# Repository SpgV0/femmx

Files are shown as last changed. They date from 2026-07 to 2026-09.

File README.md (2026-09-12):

# FEMMX

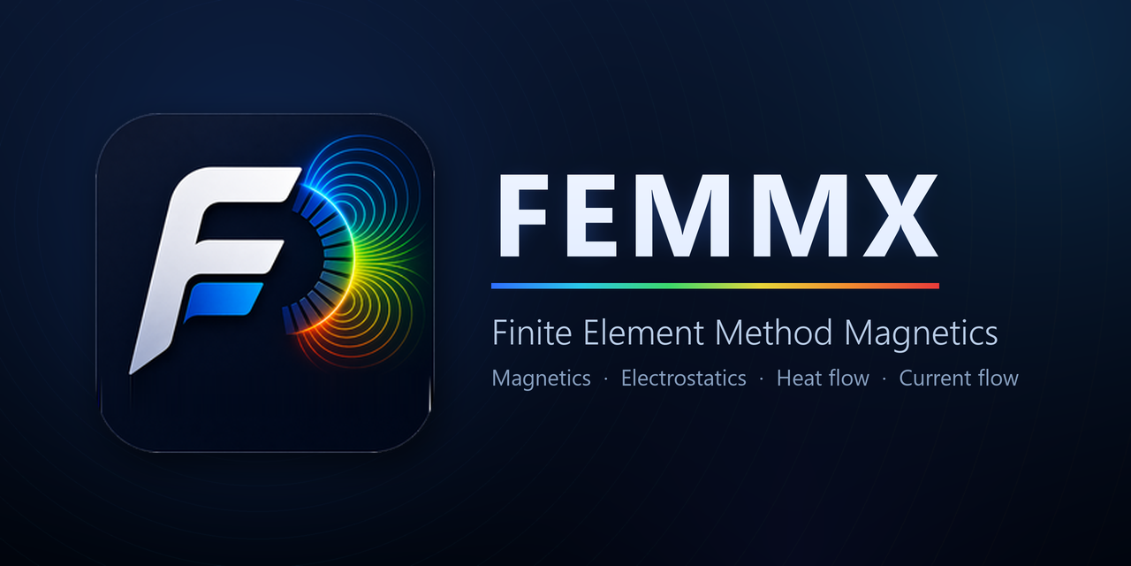
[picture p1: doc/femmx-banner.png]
FEMMX -- Finite Element Method Magnetics


FEMMX is a fork of [FEMM 4.2](https://www.femm.info/) (Finite Element Method
Magnetics), a Windows application for solving 2D planar and axisymmetric
problems in:

* Magnetics (magnetostatic and time-harmonic/eddy-current)
* Electrostatics
* Heat flow
* Current flow (DC conduction)

Problems are built and meshed in a native MFC editor (`femmx.exe`), solved by
one of four solver executables — one per problem type — and results are
inspected in a built-in post-processor.

| Problem type | Solver | Invoked from |
|---|---|---|
| Magnetics | `fkn.exe` | `femm/FemmeView.cpp` |
| Electrostatics | `belasolv.exe` | `femm/beladrawView.cpp` |
| Heat flow | `hsolv.exe` | `femm/hdrawView.cpp` |
| Current flow | `csolv.exe` | `femm/cdrawView.cpp` |

(`belasolv` is BELA, FEMM's electrostatics companion program. The Kelvin
transformation is a modelling technique for open boundaries, available across
problem types — not a solver of its own.)

Problems can also be driven entirely by script via
Lua (built in), Octave/Matlab (`octavefemm`), Mathematica (`mathfemm`),
Scilab (`scifemm`), or Python ([`pyfemm`](https://www.femm.info/wiki/pyFEMM),
via the `femm.ActiveFEMM` COM automation server).

This fork is hosted at https://github.com/SpgV0/femmx as a fork of
https://github.com/cenit/FEMM. It adds an optional CUDA-accelerated linear
solve, a CPU/GPU load monitor, dark-theme editor/results views, an installer
that mirrors the original `C:\femm42` layout with automatic COM
self-registration, and a pytest-based regression suite -- see
[CHANGELOG.md](CHANGELOG.md) for the full, dated history of every change
since the [22Oct2023](https://github.com/cenit/FEMM) upstream baseline, and
[NOTICE.md](NOTICE.md) for the license-required per-file modification
record.

FEMMX is distributed under the terms of the Aladdin Free Public License --
see [license.txt](license.txt).

## Requirements

Building and running FEMMX requires **Windows** (the project is MFC/Win32
native code; there is no cross-platform build). You'll need:

* [Git](https://git-scm.com/)
* [CMake](https://cmake.org/) 3.10 or later
* Visual Studio 2019 or 2022, with the **"Desktop development with C++"**
  workload, which must include the **MFC and ATL** optional component
  (`find_package(MFC REQUIRED)` in several `CMakeLists.txt` files depends on
  it)

Optional, depending on what you want to build:

* [NSIS](https://nsis.sourceforge.io/) (`makensis` on `PATH`) -- to build the
  installer (`FEMMX_v<version>_installer.exe`). If not found, the
  executables still build fine; only installer packaging is skipped.
* [NVIDIA CUDA Toolkit](https://developer.nvidia.com/cuda-toolkit), **12.x**
  (13.x dropped compute capability `sm_60`, one of this project's default
  target architectures) -- to build `fkn.exe`'s optional GPU-accelerated
  linear solver. Also needs an NVIDIA GPU to actually use at runtime (it
  falls back to the CPU solver automatically if none is found). CUDA's
  MSVC-support window tends to lag behind the newest installed Visual
  Studio, so a VS2022 toolset is also needed alongside a newer VS if one is
  installed (auto-detected by `build_cuda.bat`; see below).
* A LaTeX distribution (e.g. [MiKTeX](https://miktex.org/)), with `latex` on
  `PATH` -- to build the PDF manual (`manual/manual.tex.in`). Skipped
  automatically if not found.
* [Python](https://www.python.org/) 3.9+ with the packages in
  [`test/requirements.txt`](test/requirements.txt) -- to run the regression
  suite under `test/` (see [test/README.md](test/README.md)).

## Building

The simplest way to build is the zero-argument wrapper scripts, which
auto-detect all of the above and print diagnostics for anything missing:

```
build_plain.bat
```
builds `femmx.exe` and the other executables without GPU support, into
`bin\plain\`.

```
build_cuda.bat
```
additionally builds `fkn.exe`'s CUDA-accelerated linear solver, into
`bin\cuda\`. Auto-detects the CUDA Toolkit root (preferring a 12.x install)
and an `nvcc`-compatible VS2022 toolset; pass a CUDA Toolkit path as the
first argument to override, or set the `FEMM_CUDA_CCBIN` environment
variable to force a specific MSVC toolset.

Either way, once the build finishes you'll have:

* `bin\<plain|cuda>\femmx.exe` -- the main application
* `bin\<plain|cuda>\FEMMX_v<version>_installer.exe` -- the NSIS installer
  (if NSIS was found)

Both scripts are thin wrappers (`build_femmx.ps1`) around the underlying
`build.ps1`, which can also be invoked directly for more control, e.g.:

```
.\build.ps1 -DisableInteractive -DisableLaTeX -ForceTriangle32bit `
  -AdditionalBuildSetup "-DENABLE_CUDA_SOLVER=ON -DFEMM_CUDA_ROOT=`"C:\Program Files\NVIDIA GPU Computing Toolkit\CUDA\v12.6`""
```

`build.ps1` runs `cmake --build . --target install`, which places
executables directly in `bin\` (not the `plain\`/`cuda\` split -- that split
is done by `build_femmx.ps1` afterwards so a plain and a CUDA build don't
clobber each other).

### Useful CMake options

Pass these via `build.ps1`'s `-AdditionalBuildSetup "..."` parameter, or
directly to `cmake` if configuring by hand:

| Option | Default | Effect |
|---|---|---|
| `ENABLE_CUDA_SOLVER` | `OFF` | Build `fkn.exe`'s CUDA-accelerated solver. Requires `FEMM_CUDA_ROOT`. |
| `FEMM_CUDA_ROOT` | (none) | Path to the CUDA Toolkit, e.g. `C:/Program Files/NVIDIA GPU Computing Toolkit/CUDA/v12.6` |
| `FEMM_CUDA_CCBIN` | (none) | Optional `nvcc -ccbin` override: an alternate MSVC toolset `bin` dir |
| `FEMM_CUDA_ARCHS` | `60;75;86;89` | CUDA compute capabilities to build for |
| `BUILD_MANUAL` | `OFF` | Build the PDF manual (needs LaTeX) |
| `SKIP_<target>` | `OFF` | Skip building an individual component, e.g. `SKIP_scifemm` |

## Installing

Run the installer produced by the build (`bin\plain\FEMMX_v<version>_
installer.exe` or `bin\cuda\FEMMX_v<version>_installer.exe`). It installs to
a fixed `C:\FEMMX`, laid out like the original FEMM 4.2 installer:

```
C:\FEMMX\
  bin\        executables and data libraries
  mathfemm\   Mathematica interface
  mfiles\     Octave/Matlab interface (octavefemm)
  scifemm\    Scilab interface
```

and self-registers the `femm.ActiveFEMM` COM automation class (used by
`pyfemm`, Octave, Matlab, Mathematica, and Scilab), so scripting works
immediately after install with no separate manual registration step. A CUDA
build's installer also bundles the required CUDA runtime DLLs.

## Testing

The regression suite under `test/` builds and solves FEMM models through the
`pyfemm` COM interface and checks results, timings, and Lua-command
coverage. See [test/README.md](test/README.md) for details; in short:

```
pip install -r test/requirements.txt
pytest test/
```

## More information

* [CHANGELOG.md](CHANGELOG.md) -- dated history of every change, this fork
  and upstream
* [NOTICE.md](NOTICE.md) -- license-required modification record
* [test/README.md](test/README.md) -- regression suite details
* [manual/](manual/) -- LaTeX source for the user manual
* Upstream: https://github.com/cenit/FEMM, https://www.femm.info/

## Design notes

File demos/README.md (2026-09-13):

# FEMMX demo models

A small library of worked models, one set per problem type, intended to be opened,
solved and read rather than edited in place. Every one of them is a case with a known
closed-form answer, so the demo is not just "a model that opens" -- it is a model whose
result you can check against physics.

These are the sources the planned **File > Demo Models** browser lists (issue #89).
Treat this directory as read-only: a demo should be opened as a working copy, and
solving must not write mesh or solution files back here. The demos are committed, so
`git status` will notice if something does.

Each model also carries its own description in its `[Comment]` field, which the
Problem Information dialog shows.

## Magnetics (`.fem`)

| Model | What it shows | Analytic reference |
|---|---|---|
| `straight_wire.fem` | A single 10 A conductor in open-boundary air. The simplest model here. | `B = mu0*I/(2*pi*r)` |
| `coax_cable.fem` | Coax with equal and opposite currents; external inductance from stored energy. | `L' = (mu0/2pi)*ln(b/a)` |
| `circular_loop_axi.fem` | Single-turn loop, axisymmetric -- the standard introduction to axisymmetric modelling. | `B = mu0*I*a^2/(2*(a^2+z^2)^(3/2))` |
| `solenoid_axi.fem` | A solenoid short enough that end effects pull the centre field well below `mu0*n*I`. | finite-solenoid on-axis form |
| `two_wires_force.fem` | Force between parallel conductors; Lorentz and weighted stress tensor on the same block. | `F/L = mu0*I1*I2/(2*pi*d)` |
| `saturating_core.fem` | Nonlinear B-H core driven into saturation -- relative permeability falls from ~13000 to ~100. | no closed form; check against the B-H curve |
| `skin_effect_ac.fem` | Time-harmonic at 100 kHz: skin depth ~0.21 mm in a 5 mm conductor. | `delta = sqrt(2/(omega*mu*sigma))` |

## Electrostatics (`.fee`)

| Model | What it shows | Analytic reference |
|---|---|---|
| `parallel_plate.fee` | Periodic side boundaries remove fringing, leaving a uniform field. | `C = eps*A/d` |
| `coax_capacitor_axi.fee` | Coaxial conductors at fixed potentials; logarithmic potential. | `C' = 2*pi*eps/ln(b/a)` |

## Heat flow (`.feh`)

| Model | What it shows | Analytic reference |
|---|---|---|
| `slab_1d.feh` | 400 K / 300 K faces: linear profile, uniform flux. | `q = k*dT/L` |
| `cylindrical_shell_axi.feh` | Radial conduction, logarithmic rather than linear. | `T(r)` logarithmic |
| `convection_wall.feh` | A convection boundary, so the outer face temperature is solved rather than prescribed. | `q'' = h*(T_s - T_inf)` |

## Current flow (`.fec`)

| Model | What it shows | Analytic reference |
|---|---|---|
| `conducting_bar.fec` | Uniform current density between two fixed potentials. | `R = rho*L/A` |

## Where these came from

Each model was taken from the analytic regression suite -- `test/analytic_fields_test.py`
and `test/magnetics_analytic_test.py` build them and assert the results against the
formulas above, typically to well under 1%. `demos.json` records the source path for
each in its `derivedFrom` field.

That shared origin is deliberate: the demo library and the analytic tests stay
meaningful together, and a demo that stopped matching its formula would fail the test
suite first. Note the test suite regenerates its own copies under `test/results/`
(gitignored) on every run -- these committed copies are independent of that.

`demos.json` is the machine-readable manifest: title, problem type, description,
analytic reference and source path per demo.

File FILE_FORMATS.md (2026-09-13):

# FEMMX file formats

FEMMX uses four file types. `.fem`/`.ans` are the original, plain-text
formats shared by every FEMMX component (both GUIs, the solvers, and
every language binding). `.femx`/`.ansx` are newer, pure-binary **caches**
of that same data, introduced to make loading fast for large models —
never a second source of truth, and never shell-registered or meant to
be edited by hand.

Both GUIs (the classic MFC app, `femm/`, and the Qt app, `femmqt/`) read
and write all four formats independently — there is no shared parsing
code between them, matching this project's existing convention that each
consumer (GUI or solver) owns its own reader/writer for these formats.

## Relationship between the four formats

```
   .fem  (geometry + properties, text)
     |
     |  triangle.exe (mesh) + fkn.exe (solve)
     v
   .ans  (.fem's own header, plus the solved mesh, text)

   .femx = binary cache of .fem, regenerated whenever stale
   .fes  = femmqt's sketch layer for .fem -- NOT a cache, see below
   .ansx = binary cache of .ans's MESH data only, regenerated whenever stale
```

- A `.femx`/`.ansx` file is always named after its source
  (`foo.fem` → `foo.femx`, `foo.ans` → `foo.ansx`) and lives next to it.
- **Freshness check**: each cache's header records its source file's
  size (bytes) and mtime (seconds since epoch). A GUI opening `foo.fem`
  compares `foo.femx`'s recorded size/mtime against `foo.fem`'s current
  size/mtime on disk; any mismatch (or a missing/corrupt/wrong-version
  cache) means "stale" — the GUI falls back to the normal text parser
  and, on success, rewrites the cache for next time. This is always a
  **best-effort** step: a write failure (e.g. a read-only directory)
  never fails the operation the user actually asked for, it just means
  no speedup next time.
- Every numeric field in `.femx`/`.ansx` is a byte-for-byte copy of what
  the text parser would have produced from `.fem`/`.ans` — opening a
  file via its cache and via its text source must always produce
  identical in-memory state.

---

## `.fem` — geometry + properties (plain text)

Written by `CFemmeDoc::OnSaveDocument` (`femm/FemmeDoc.cpp`) /
`FemmFileIO::writeFem` (`femmqt/FemmFileIO.cpp`); read by
`OnOpenDocument` / `FemmFileIO::readFem`. Tag-value lines
(`[Tag]  =  value` or, inside a property block, `<Tag> = value`),
whitespace around `=` is not significant. Numbers are written with
`%.17g` (exact `double` round-trip). Every table below is 0-indexed in
memory but 1-indexed on disk (`0` = "none" for an optional reference; an
in-file index of `N` means the `N`th entry, 1-based, of the referenced
list).

### Header (top-level `[Tag] = value` lines, in this order)

| Tag | Field | Notes |
|---|---|---|
| `[Format]` | file format version | `4.0` currently |
| `[Frequency]` | Hz | 0 = magnetostatic |
| `[Precision]` | solver precision | e.g. `1e-8` |
| `[MinAngle]` | degrees | triangle.exe mesh quality constraint |
| `[DoSmartMesh]` | 0/1 | auto-refine mesh near small features |
| `[Depth]` | into-the-page depth | planar problems only |
| `[LengthUnits]` | `inches`\|`millimeters`\|`centimeters`\|`meters`\|`mils`\|`microns` | |
| `[ProblemType]` | `planar`\|`axisymmetric` | |
| `[Coordinates]` | `cartesian`\|`polar` | |
| `[ACSolver]` | 0=successive approx, 1=Newton | |
| `[GPUAccel]` | 0/1 | ask fkn.exe to try its CUDA solve; no effect unless fkn.exe was built with CUDA support |
| `[PrevType]` / `[PrevSoln]` | previous-solution info, for incremental permeability problems | |
| `[Comment]` | quoted string | free-text problem note |
| `[extZo]` / `[extRo]` / `[extRi]` | axisymmetric exterior-region parameters | only written if `extRo`/`extRi` are both non-zero |

### Property sections

Each is `[XProps]  = <count>` followed by `<count>` `<BeginX>...<EndX>`
blocks.

**`[PointProps]`** (`<BeginPoint>`): `<PointName>`, `<I_re>`/`<I_im>`
(applied point current, A), `<A_re>`/`<A_im>` (prescribed nodal value).

**`[BdryProps]`** (`<BeginBdry>`): `<BdryName>`, `<BdryType>` (0=fixed
A, 1=small-skin-depth eddy current, 2=mixed, 3=SDI, 4/5=periodic/
antiperiodic, 6/7=periodic/antiperiodic air-gap), `<A_0>`/`<A_1>`/
`<A_2>`/`<Phi>` (BdryType=0), `<c0>`/`<c0i>`/`<c1>`/`<c1i>` (mixed BC
coefficients), `<Mu_ssd>`/`<Sigma_ssd>` (eddy BC), `<innerangle>`/
`<outerangle>` (air-gap element rotation).

**`[BlockProps]`** (`<BeginBlock>`): `<BlockName>`, `<Mu_x>`/`<Mu_y>`
(relative permeability), `<H_c>` (magnetization, A/m), `<H_cAngle>`
(magnetization direction, degrees), `<J_re>`/`<J_im>` (applied current
density, MA/m²), `<Sigma>` (conductivity, MS/m), `<d_lam>` (lamination
thickness, mm), `<Phi_h>`/`<Phi_hx>`/`<Phi_hy>` (hysteresis angles,
degrees), `<LamType>` (0=none/in-plane, 1=x-laminated, 2=y-laminated,
≥3=stranded/litz), `<LamFill>` (lamination fill factor), `<NStrands>`,
`<WireD>` (strand diameter, mm), `<BHPoints>` followed by that many
`B<tab>H` lines (a linear material has `BHPoints = 0` and uses `Mu_x`/
`Mu_y` directly instead).

**`[CircuitProps]`** (`<BeginCircuit>`): `<CircuitName>`,
`<TotalAmps_re>`/`<TotalAmps_im>`, `<CircuitType>` (0=parallel,
1=series), and optionally `<VoltGradient_re>`/`<VoltGradient_im>`.

`<CircuitType>` selects how the circuit is driven. 0 is a *parallel*
circuit: the whole region carries `TotalAmps`, and the solver finds the
current density that delivers it. 1 is a *series* circuit: every turn
carries `TotalAmps`, so the region's current density is scaled by the
block label's `<Turns>` count.

`<VoltGradient_re>`/`<VoltGradient_im>` prescribe a voltage gradient
along the circuit instead of a current, and are read into
`CCircuit::dVolts_re/im` by every magnetics solve path
([`fkn/femmedoccore.cpp:965`](fkn/femmedoccore.cpp#L965), used in
`prob1big.cpp` through `prob4big.cpp`). They default to 0 and are written
only when non-zero, so a model that does not use them is byte-identical
to one written before they were supported.

> **This field is inert in the shipped solver.** `LoadCircuits` rewrites
> every `CircuitType` of 1 to 0 just before the solve
> ([`fkn/femmedoccore.cpp:1100`](fkn/femmedoccore.cpp#L1100)) — "now, all
> circuits look like parallel circuits" — and the branch that reads
> `dVolts` runs only for a non-zero type. So no `.fem` can currently
> reach it. Both editors nevertheless parse and preserve the tags,
> because until they did, a hand-authored or third-party file carrying a
> voltage-driven circuit lost it silently on its next save. Documented
> here as what it is rather than left out: an undocumented field that a
> published format spec omits is how the loss went unnoticed.

### Geometry sections (in this order)

- **`[NumPoints] = N`**, then `N` lines: `x  y  pointPropIndex  inGroup`
  (`pointPropIndex`: 0=none, else 1-based into `[PointProps]`).
- **`[NumSegments] = N`**, then `N` lines: `n0  n1  maxSideLength
  boundaryMarker  hidden  inGroup` (`maxSideLength`: `-1` = no mesh
  constraint; `boundaryMarker`: 0=none, else 1-based into `[BdryProps]`).
- **`[NumArcSegments] = N`**, then `N` lines: `n0  n1  arcLength
  maxSideLength  boundaryMarker  hidden  inGroup  mySideLength`
  (`arcLength`/`mySideLength` in degrees).
- **`[NumHoles] = N`**, then `N` lines: `x  y  inGroup` — block labels
  with no assigned material ("`<No Mesh>`" in the classic GUI's own
  in-memory model).
- **`[NumBlockLabels] = N`**, then `N` lines: `x  y  blockTypeIndex
  meshSizeDiameter  circuitIndex  magDir  inGroup  turns
  isExternal+isDefault  ["magDirFctn"]` (`blockTypeIndex`: 1-based into
  `[BlockProps]`; `meshSizeDiameter`: `-1` = no constraint, else
  `sqrt(4*maxArea/pi)` — the *area* constraint, converted to a
  *diameter* only for this on-disk field; `circuitIndex`: 0=none, else
  1-based into `[CircuitProps]`; trailing quoted string is a custom Lua
  `MagDirFctn` expression, present only if non-empty).

---

## `.ans` — solved mesh (plain text)

Written by `fkn.exe` (`fkn/prob1big.cpp`); read by `CFemmviewDoc::
OnOpenDocument` (`femm/FemmviewDoc.cpp`) / `AnsFileIO::readAns`
(`femmqt/AnsFileIO.cpp`). The header and property sections are **byte-
for-byte the same tag format as `.fem`** (both readers tolerate the
other file type's trailing sections they don't recognize) — solving
never changes the original geometry/properties, so `fkn.exe` just
carries them through unchanged ahead of its own solved-mesh section.

After the properties sections and geometry sections (same as `.fem`,
above) comes an untagged `[Solution]` marker, then:

1. **Mesh nodes**: `<count>`, then that many lines:
   `x  y  A_re  [A_im]` (`A_im` only present if `Frequency != 0`) —
   the complex nodal vector potential (planar) or `r·A` flux function
   (axisymmetric), in Wb/m or Wb respectively.
2. **Mesh elements**: `<count>`, then that many lines:
   `p0  p1  p2  lbl` (0-based node indices; `lbl` = 0-based index into
   the block-label list from the header section above).
3. **Per-block-label circuit correction**: `<count>` (always equal to
   the block-label count — every label gets a row, even ones with no
   circuit assigned), then that many lines: `Case  value_re  [value_im]`
   — `fkn.exe`'s own solved correction for circuits with a prescribed
   voltage (`Case=0`, `value` = the solved voltage-drop `dVolts`) or
   prescribed current (`Case=1`, `value` = the solved current-density
   correction `J`); a label with no circuit gets a harmless placeholder
   row (`Case=1`, `value=0`). This section is easy to miss reading the
   format casually — it's untagged and comes immediately after the
   element list with no header of its own.
4. **PBC (periodic boundary) data** — not actively used by either
   post-processor GUI today, but must still be read (to reach the data
   after it): `<count>`, then that many lines (skipped).
5. **Air gap elements**: `<count>`, then for each: a name line, a
   parameter line (`BdryFormat  InnerAngle  OuterAngle  ri  ro
   totalArcLength  agc_re  agc_im  totalArcElements  InnerShift
   OuterShift`), and (if `totalArcElements > 0`) further per-element
   sample data. Used for rotating-machine "moving band" simulations —
   an advanced, comparatively rare feature; not yet supported by the Qt
   GUI.

**Derived data, recomputed after loading, not stored in the file**:
each element's centroid, `rsqr` (max corner distance from centroid,
used for point-location queries), magnetization direction (evaluates
any custom `MagDirFctn` Lua expression), and `B1`/`B2` (flux density,
from nodal `A` via shape-function gradients) — this recomputation is
`.ans`'s single most expensive load step for a large mesh, and is
exactly what `.ansx` exists to cache (below).

---

## `.femx` — binary cache of `.fem`

Defined in `femmqt/FemxFileIO.h`/`.cpp`; ported to the classic GUI in
`femm/FemxFileIO.h`/`.cpp` (byte-for-byte the same format, independent
implementation — Qt types on one side, MFC/plain C++ on the other,
matching this project's established pattern of independent format
readers per consumer). Current version: **2**.

All multi-byte fields are little-endian (native x86/x64), and every
struct is `#pragma pack(push, 1)` — no padding.

```
FemxHeader {
  char     magic[8];            "FEMMFEMX"
  uint32_t version;              2
  uint32_t headerSize;           sizeof(FemxHeader) -- lets a future
                                  version add trailing fields a reader
                                  built against an older version can
                                  still skip past
  uint32_t problemType;          0=planar, 1=axisymmetric
  uint32_t lengthUnits;          matches .fem's [LengthUnits] encoding
  uint8_t  coordsPolar;
  uint8_t  smartMesh;
  uint8_t  reserved[6];
  double   frequency, precision, minAngle, depth;
  double   extZo, extRo, extRi;
  int32_t  acSolver, gpuAccel, prevType;
  char     prevSoln[260];        fixed-size, NUL-padded
  char     comment[512];         fixed-size, NUL-padded
  uint64_t sourceFemSize;        source .fem's size, for the freshness check
  uint64_t sourceFemMtimeSecs;   source .fem's mtime, for the freshness check
  uint64_t pointPropCount, boundaryPropCount, materialPropCount, circuitPropCount;
  uint64_t nodeCount, segmentCount, arcCount, blockLabelCount;
}                                 -- 952 bytes
```

Followed by flat arrays, in this order, each `count` from the header
above: point-prop records, boundary-prop records, material-prop records,
circuit-prop records, node records, segment records, arc records,
block-label records. Every property/geometry field maps directly to its
`.fem` text-format counterpart (see the `.fem` section above); a few
notable on-disk differences from the in-memory model:

- **BH curve data** (`FemxMaterialPropRecord`) is a fixed
  `double[256][2]` array (`bhPointCount` says how many are actually
  used) rather than a dynamic list — 256 comfortably exceeds every
  material in `bin/matlib.dat` (the largest ships 149 points); classic
  FEMM's own in-memory model has no fixed cap, so this is a cache-format
  limit only, not a modeled one. **Changing this cap changes the
  record's byte size and requires a version bump** — a real bug this
  session (cap silently truncating past-64-point curves) was caused by
  extending the in-memory field without remembering this.
- **Point/boundary/circuit references** (a node's point-prop, a
  segment/arc's boundary marker, a block label's material/circuit) are
  stored as the same 0/1-based index convention as the `.fem` text
  format, not as names — even though the classic GUI's own in-memory
  model stores these as name strings (`CString`) internally; the reader/
  writer resolves name↔index against the property arrays exactly like
  `.fem`'s own text reader/writer already does.
- **Block label area vs. diameter**: `.femx`'s `maxArea` field stores
  the *area* directly (unlike `.fem` text, which stores a derived
  diameter) — matching the in-memory field it mirrors, since there's no
  text-format round-trip step to justify the conversion here.

---

## `.ansx` — binary cache of `.ans`'s mesh

Defined in `femmqt/AnsxFileIO.h`/`.cpp`; ported to the classic GUI in
`femm/AnsxFileIO.h`/`.cpp`. Current version: **3**.

**Deliberately not a serialization of the whole `.ans` file** — only the
mesh-node and mesh-element arrays (the two sections whose size scales
with mesh size and dominates load time for a large solved model).
Geometry/properties, the per-block-label circuit correction section, and
the air gap element section are always still read from the source
`.ans` text regardless of whether the mesh cache is used — all three are
bounded by geometry complexity (not mesh density), so cheap even for a
multi-million-element mesh, and re-reading them keeps this format simple
and its scope obviously "mesh only."

```
AnsxHeader {
  char     magic[8];            "FEMMANSX"
  uint32_t version;              3
  uint32_t headerSize;           sizeof(AnsxHeader)
  uint32_t coordSystem;          0=planar, 1=axisymmetric
  uint32_t lengthUnits;
  double   frequency;
  double   bMagMin, bMagMax;     precomputed |B| range, for the density-plot legend
  uint64_t sourceSize;           source .ans's size, for the freshness check
  uint64_t sourceMtimeSecs;      source .ans's mtime, for the freshness check
  uint64_t nodeCount;
  uint64_t elementCount;
}                                 -- 80 bytes

AnsxNodeRecord {
  double x, y, Are, Aim;
}                                 -- 32 bytes

AnsxElementRecord {
  int64_t  p0, p1, p2, lbl;      node/label indices (int64 purely to
                                  keep every field 8-byte aligned, not
                                  because indices need the range)
  double   B1re, B1im, B2re, B2im;
  double   ctrX, ctrY;
  double   muX, muY;             resolved material properties (see below)
  double   sigma;
  double   jSrcRe, jSrcIm;
  double   jRe, jIm;             total current density: source + eddy +
                                  solved circuit correction, MA/m^2
}                                 -- 136 bytes
```

Followed by `nodeCount` node records then `elementCount` element
records.

- **B1/B2/centroid are precomputed**, not recomputed from nodal `A` on
  every load — this is the actual point of the format (see `.ans`'s own
  "derived data" note above). `rsqr` and magnetization direction are
  *not* cached (cheap, in-memory-only recomputation, no text re-parse
  needed either way) — a reader still derives those itself after loading
  either the text or the binary path.
- **muX/muY/sigma/jSrcRe/jSrcIm/jRe/jIm are precomputed too**, resolved
  once from each element's block label → material lookup (plus, for
  jRe/jIm, `fkn.exe`'s own solved circuit-correction data) — this is
  what drives the `|H|` and `|Js+Je|` density plots without needing a
  live material-list lookup at render time. The classic GUI's own
  post-processor doesn't need these cached (it already has fast,
  direct, in-memory material-list access at render time) but still
  writes them correctly, purely so a `.ansx` written by the classic GUI
  behaves identically when later opened by the Qt GUI.
  `CFemmviewDoc::GetJA()`'s return value is scaled to A/m² internally
  (despite its own comment claiming MA/m²) — the writer divides by 1e6
  to match every other current-density field's actual MA/m² units.

## The four solution formats

Each solver writes its own solution file, and each is **the model file it
was given, with a `[Solution]` section appended**. Everything before that
marker is the same `[PointProps]`/`[BdryProps]`/`[BlockProps]`/geometry
content the input had, so a solution file is openable as a model.

| physics | solver | solution | post-processor |
|---|---|---|---|
| magnetics | `fkn.exe` | `.ans` | `femm/FemmviewDoc.cpp` |
| electrostatics | `belasolv.exe` | `.res` | `femm/belaviewDoc.cpp` |
| heat flow | `hsolv.exe` | `.anh` | `femm/hviewDoc.cpp` |
| current flow | `csolv.exe` | `.anc` | `femm/CVIEWDOC.CPP` |

### The `[Solution]` section

After the `[Solution]` marker: a node count, that many node lines, an
element count, then that many element lines.

**Element lines are identical in all four** — `p0  p1  p2  lbl`, three
0-based mesh-node indices plus the 0-based index of the block label whose
material the element carries.

**Node lines carry that physics' potential, and differ:**

| physics | node line | notes |
|---|---|---|
| magnetics | `x  y  A_re  A_im` | `A_im` present **only when `[Frequency]` is non-zero**; a DC solution has three columns, not four |
| electrostatics | `x  y  V  Q` | `Q` is the conductor the node belongs to, or 0 |
| heat flow | `x  y  T  Q` | same shape as electrostatics, with temperature in place of voltage |
| current flow | `x  y  v_re  v_im  Q` | the only one that is both complex **and** carries a conductor column |

Two traps worth stating, because both produce a file that parses without
complaint and means something else:

- **Magnetics' column count depends on the frequency in the header.**
  Reading a DC `.ans` as though it were AC consumes the next line's `x`
  as `A_im`, and everything after is shifted. The frequency has to be
  known before the node loop starts — it is in the same file, above.
- **A magnetics node has no conductor column and the other three do.**
  The same asymmetry as the model formats, where magnetics attaches a
  circuit to block labels and the rest attach conductors to geometry.

An *incremental* magnetics solution additionally writes a boundary-code
int and the previous solution's `A` per node; femmqt does not produce
those.

### Derived quantities

The solvers store only the potential per node. Everything the viewer
plots is derived from its gradient over each element:

| physics | stored | derived |
|---|---|---|
| magnetics | `A` | `B = curl A`, `H = B/mu`, `J` |
| electrostatics | `V` | `E = -grad V`, `D = eps*E` |
| heat flow | `T` | `F = -k grad T`, `G = -grad T` |
| current flow | `V` | `E = -grad V`, `J = sigma*E` |

## The four model formats, and what differs between them

`.fem` (magnetics), `.fee` (electrostatics), `.feh` (heat flow) and
`.fec` (current flow) are the same file with different property
payloads. femmqt reads and writes all four through one driver
(`femmqt/ProblemFileIO.cpp`) with the differing parts in
`femmqt/PropertyCodec.cpp`; the classic GUI has four separate document
classes instead.

**Identical in all four:** the `[Format]`, `[Precision]`, `[MinAngle]`,
`[DoSmartMesh]`, `[Depth]`, `[LengthUnits]`, `[ProblemType]`,
`[Coordinates]`, `[extZo]`/`[extRo]`/`[extRi]`, `[GPUAccel]` and
`[Comment]` header scalars; the `[NumPoints]`, `[NumSegments]`,
`[NumArcSegments]` and `[NumHoles]` sections; and the
`<BeginX>`/`<EndX>` record framing of the property sections.

**Per-format header scalars:** `[Frequency]`, `[ACSolver]`, `[PrevType]`
and `[PrevSoln]` for magnetics; `[Frequency]` for current flow; `[dT]`
and `[PrevSoln]` for heat flow. Electrostatics has none of its own.

**Property payloads:**

| section | `.fem` | `.fee` | `.feh` | `.fec` |
|---|---|---|---|---|
| `[PointProps]` | `I_re` `I_im` `A_re` `A_im` | `Vp` `qp` | `Tp` `qp` | `vpr` `vpi` `qpr` `qpi` |
| `[BdryProps]` | `A_0`…`A_2` `Phi` `c0`/`c0i` `c1`/`c1i` `Mu_ssd` `Sigma_ssd` `innerangle` `outerangle` | `Vs` `qs` `c0` `c1` | `Tset` `qs` `beta` `h` `Tinf` `TinfRad` | `vsr` `vsi` `qsr` `qsi` `c0r`…`c1i` |
| `[BlockProps]` | `Mu_x` `Mu_y` `H_c` `J_re` `Sigma` `Phi_h` … `BHPoints` | `ex` `ey` `qv` | `Kx` `Ky` `Kt` `qv` `TKPoints` | `ox` `oy` `ex` `ey` `ltx` `lty` |
| sources | `[CircuitProps]` | `[ConductorProps]` | `[ConductorProps]` | `[ConductorProps]` |

**The geometry is *not* quite identical**, which is easy to miss and
expensive to get wrong:

- `.fee`, `.feh` and `.fec` carry a **conductor index** as an extra
  trailing column on every node and segment row, and on the arc row it
  sits **between `inGroup` and `mySideLength`** — so reading an arc with
  the magnetics column layout does not drop a field, it reads
  `mySideLength` out of the conductor column.
- `.fem` block-label rows are `x y blockType maxsidelen circuit MagDir
  group turns flags ["MagDirFctn"]`; the other three are
  `x y blockType maxsidelen group flags`. No circuit, no MagDir, no
  turns — those are magnetics ideas.

Magnetics attaches its source to a **block label** (a circuit carries
current through a region); the other three attach theirs to **nodes,
segments and arcs** (a conductor is an equipotential surface).

### `.femx` is magnetics-only, deliberately

The binary cache exists for `.fem` and is not extended to the other
three. It is a mirror of the `.fem` record layout and it exists **twice**
— `femmqt/FemxFileIO.cpp` and `femm/FemxFileIO.cpp`, which must stay
byte-identical — so each new format would mean another record layout kept
in lockstep across both copies. The payoff would be load time on models
that do not exist: the very large models that motivated the cache are
magnetics.

The format also has no field saying which physics it holds, so a `.femx`
cannot describe a `.fee` without a version bump invalidating every
existing cache.

The correctness consequence matters more than the reasoning: a `.femx`
sitting next to a `.fee` is a cache of some *other* model that shared the
base name, so femmqt consults the cache only when opening a `.fem`.

## `.fes` — the sketch sidecar (femmqt only)

`foo.fes` holds the constraints and dimensions femmqt's CAD sketch layer
attaches to `foo.fem`. Added for issue #27; before it, the sketch was
session-only and closing the file discarded every constraint.

It is **not a cache**. `.femx`/`.ansx` are regenerable from their source
and are rewritten whenever they go stale; `.fes` is the only copy of what
it holds, which is exactly why it could not live inside `.femx` — sketch
data there would be destroyed the first time anyone touched the `.fem` in
the classic editor, or copied only the `.fem` somewhere else.

- Plain text, versioned by a `<Format>` line, so it diffs and can be
  repaired by hand like `.fem` itself.
- **Nothing about the `.fem` changes.** A `.fem` written by femmqt with a
  sketch is byte-identical to one written without, so it stays readable
  by the classic MFC editor and all four solvers, none of which know
  anything about constraints.
- Safe to delete. A model with no `.fes` loads as an unconstrained
  sketch, which is what every model predating the feature is.
- Each reference is stored with a geometric fingerprint (a node's
  coordinates, an edge's two endpoints) as well as its index, because
  indices shift under insert and delete. On load the stored index is
  accepted only if the entity there still matches; otherwise the
  fingerprint finds it. If nothing matches, or several do, the constraint
  is **dropped and reported** rather than attached to whatever now
  occupies that index.
- Written best-effort, like the caches: a read-only directory never fails
  the save the user asked for. Unlike a cache, the failure is reported.

### Format 2 — construction geometry (issue #31)

`<Format> = 2` adds three sections, written **before** the constraints
because a constraint may reference what they define and references are
resolved as the file is read:

```
<NumConstructionNodes> = 1
cnode 5 0 0
<NumConstructionSegments> = 1
cseg 5 -2 5 12 0
<NumConstructionArcs> = 0
```

- `cnode x y group`
- `cseg x0 y0 x1 y1 group`
- `carc x0 y0 x1 y1 includedAngleDeg group`

Construction geometry is a centreline, a bolt circle, a reference
rectangle — something to constrain and dimension the real geometry
against. It is **excluded from the `.fem` and the `.femx`** and is never
meshed, so the `.fes` is its only copy; that is why these sections carry
the geometry itself rather than a flag.

Endpoints are stored by **coordinate, not index**, because these entities
do not exist in the `.fem` at all and so have no index there to survive
as. On load each endpoint finds the node already at that position or
creates one — finding it is the normal case and the important one, since
a centreline endpoint that coincides with a real corner is exactly what
it was drawn against.

A format-1 file simply has no construction sections, which reads as "no
construction geometry" — the state every model written before this is in.

Keeping it out of the `.fem` is what makes it safe: a centreline written
into the model would be a material boundary, splitting the region it runs
through, meshed and solved like any other edge.

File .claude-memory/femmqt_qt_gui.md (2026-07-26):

---
name: femmqt-qt-gui
description: "New Qt6-based GUI (femmqt/) built alongside the classic MFC GUI: magnetics-only Phase 1, full property editing, and a menu-by-menu parity pass (zoom/pan/grid/undo/move/copy/scale/mirror, mesh split, post-processor analysis tools) -- what it covers, what it doesn't, and where the design decisions live"
metadata:
  type: project
  originSessionId: 846a52dc-e5cc-4b0f-9a4f-7b5debeae297
  modified: 2026-07-24T19:07:58.144Z
---

**Current state (2026-07-21, supersedes Round 10 below): the CLASSIC GUI
is the default again, not Qt.** Round 10 made `FEMMX.lnk` launch
`femmqt.exe` exclusively; a later session reverted this per direct user
instruction ("QT has too many bugs at the moment, use the old GUI as the
default option") -- `script.nsi`'s `FEMMX.lnk` now launches `femmx.exe`
(classic), with a separate `FEMMX (Qt).lnk` for Qt. Also see
[[qt_gui_scope_deferred]]: as of the same session, new non-magnetics
physics-type work (heat/electrostatics/current-flow) is going into the
classic GUI + solvers only, not femmqt -- femmqt stays magnetics-only,
not being actively extended right now.

Built a second GUI for FEMMX, `femmqt/` (Qt6.11.1, MSVC kit at
`C:\Qt\6.11.1\msvc2022_64`), alongside the existing MFC one
(`femm/`/`femmx.exe`), per the user's request to modernize geometry
creation and solution plotting while keeping the classic GUI available.
Committed 2026-07-19 as `68e088c` on `new_features` (pushed).

**Scope: magnetics only (Phase 1).** Electrostatics/heat/current-flow are
untouched -- the classic GUI is still the only option for those. Full
design/implementation plan (including what's explicitly deferred) is at
`C:\Users\spgry\.claude\plans\quizzical-chasing-kernighan.md` -- read that
before starting Phase 2 (the other 3 physics types) or extending Phase 1.

**What it does**: `.fem` geometry editor (`QGraphicsScene`-based,
interactive add/move/delete of nodes/segments/arcs/block labels), drives
`triangle.exe` -> `fkn.exe` to solve (reimplements the `.poly`/`.pbc` mesh
step independently of `femm/writepoly.cpp`, verified byte-identical
output), and a density-plot solution viewer reading `.ans`.

**Two new binary cache formats**, both designed the same way (magic +
versioned header, flat POD record arrays, bulk read/write, staleness
checked via source file size+mtime, silently regenerated when stale):
- `.ansx` -- caches a solved `.ans`'s mesh with flux density precomputed
  once. ~80x faster to reopen than re-parsing the source `.ans`.
- `.femx` -- same idea for `.fem` geometry (added when the user asked
  for a `.fem`-side equivalent after seeing `.ansx`'s speedup).
Neither is a new "source of truth" format -- `.fem`/`.ans` stay canonical
and portable; the `x` variants are pure, regenerable performance caches,
each Qt-app-private (`femmx.exe`/`fkn.exe`/`triangle.exe` never read or
write them).

**GUI switching**: a "Switch to Qt/Classic GUI" menu item in *each* GUI
(added to the classic GUI's `IDR_FEMMETYPE`/`IDR_FEMMVIEWTYPE` menus too,
`femm/FemmeView.cpp`/`FemmviewView.cpp`'s `OnSwitchToQtGui` -- the first
change to `femm/` this whole effort made) writes `<PreferredGUI>` to
`femm.cfg` and hands the current file to the other executable via
`CreateProcess`/`QProcess::startDetached`, then closes. Verified working
in both directions. femmqt.exe is now the **default** GUI (`script.nsi`'s
primary Start Menu shortcut launches it; classic GUI has its own
`FEMMX (Classic).lnk`). **COM automation still targets `femmx.exe`
unchanged** -- femmqt.exe has no COM automation support, so pyfemm/
Octave/Mathematica/Scilab scripts are unaffected by any of this.

**Real bugs found and fixed during implementation** (worth knowing about
if touching this code): `.fem`'s bare closing tags (`<EndBdry>` etc. have
no `=`) need a special check before the tag-dispatch `continue`, or a
parser silently swallows the rest of the file (see FemmFileIO.cpp);
`QGraphicsItem`s need `ItemIgnoresTransformations` + explicit `setZValue`
for node handles to stay clickable/on-top regardless of zoom or z-order;
`QGraphicsScene` needs an explicit large fixed `setSceneRect()` or the
view silently repans between edits, breaking click-to-scene-coordinate
mapping; Qt's default double-click handling swallows the second press of
two same-position clicks, so tool-click handling must be duplicated into
`mouseDoubleClickEvent` too; populating a scene via `setPos()` on fresh
items fires the same `itemChange`/edited-signal path as a real drag, so
`m_dirty = false` must be set *after* `setProblem()`, not before.

**Build system notes**: `femmqt/CMakeLists.txt` is fully independent of
`femm/`'s (own `CMAKE_CXX_STANDARD 17`, since `femm/` has none and relies
on MSVC's legacy mode -- see [[build_and_com_registration_gotchas]] for
the related `<chrono>` finding). No 32-bit Qt6 kit exists, so `build.ps1`
now passes `-DSKIP_femmqt:BOOL=ON` on its 32-bit-only passes (both the
`-ForceTriangle32bit` secondary pass and the plain full-32-bit path).
`build_femmx.ps1`'s plain/cuda variant-move step now also moves Qt's
plugin subdirectories (`platforms/`, `styles/`, etc.), not just top-level
files, using a named allowlist rather than "any directory in bin\" --
learned the hard way after a blanket-move first draft relocated an
unrelated pre-existing stray folder.

See also [[push_branch_policy]] (updated same day: now push to
`new_features` once a day as a work backup, not just when told).

**Update (2026-07-19, same day): full property editing added, committed
`e2cad69`.** Problem Properties dialog; Material/Boundary/Circuit/
PointProp libraries via a shared `PropertyListDialog` (Add/Duplicate/
Edit/Delete callbacks) + a per-type field editor, under a new Problem
menu; per-entity (node/segment/arc/block-label) dialogs on double-click
in Select mode; an Add Arc tool; index-renumbering helpers
(`FemmProblemEdit::delete*Prop`) so deleting a still-referenced property
resets/renumbers cleanly instead of corrupting indices. Toolbar is now
icon-only (`femmqt/toolbar_icons/*.svg`), recolored at runtime from
`QPalette::ButtonText` (`IconTheme.cpp`) so it's correct in both light
and dark modes without shipping two asset sets.

**Real bug found and fixed**: `FemmNode`'s third `.fem` column was
modeled as a `boundaryProps` reference (matching Segment/Arc's own
`boundaryMarker`) but the classic GUI's writer (`femm/FemmeDoc.cpp:
2596-2601`) actually resolves it against `nodeproplist`/`pointProps` --
individual nodes only ever carry a *point* property in classic FEMM,
never a standalone boundary condition. Renamed to `pointPropIndex`
everywhere (FemmProblem.h, FemmFileIO.cpp, FemxFileIO.cpp,
MeshBuilder.cpp). Round-tripping was already correct by accident (the
raw integer just passed through untouched, nothing dereferenced it), so
this stayed latent until building the point-property assignment UI
required getting the semantics right. Worth checking for if this data
model is extended further.

**Other gotchas found this round**: `qt_standard_project_setup()` does
NOT reliably enable `CMAKE_AUTORCC` -- a `.qrc` listed in
`qt_add_executable()`'s sources silently never got compiled until
`set(CMAKE_AUTORCC ON)` was added explicitly before the `qt_add_executable`
call. `.gitignore`'s standalone `Icon?` line (for macOS's cursed
`Icon\r` custom-folder-icon files) collides case-insensitively with any
5-letter directory named `icons` on Windows git (`core.ignorecase`) --
new icon assets went in `femmqt/toolbar_icons/` instead, not
`femmqt/icons/`, to dodge it (don't touch the `Icon?` rule itself, it's
legitimate elsewhere). A `.qrc`'s resource path is `prefix + "/" +
alias` (default alias = the `<file>` text verbatim) -- `<file>icons/
foo.svg</file>` under `prefix="/icons"` resolves to `:/icons/icons/
foo.svg`, not `:/icons/foo.svg`; use an explicit `alias="foo.svg"` to
get the shorter runtime path.

**Update (2026-07-19, later same day): menu-by-menu parity pass,
committed on `new_features`.** User asked directly whether every classic-
GUI button had been covered -- it hadn't (checked `femm.rc`'s actual menu
resources for the real gap list). Added: geometry-editor Zoom/Pan/Grid,
single-level Undo (snapshot-before-destructive-op, matching classic's own
`UpdateUndo`/`Undo`), Move/Copy/Scale/Mirror on selection, Show Block
Names, Mesh menu split (Create/Show/Purge, separate from Solve --
`SolveRunner::mesh()`/`MeshOverlay.h`), Show Orphans, simplified Group
mode, Help/Recent Files; post-processor Contour/Vector plot modes
alongside Density (`MeshSolutionItem::PlotMode`), Point/Contour/Area
analysis tools, Plot X-Y (text table, no charting lib linked), Problem
Info. Full details and exact scope trims (Create Radius/Open Boundary/
Materials Library/Preferences/Dark Theme toggle/DXF/Print/Lua Console all
deliberately deferred, documented) are in the plan doc's "Round 3"
section -- read that before extending any of this further. Contour/
Vector plots verified against a real solved file (straight wire) with
textbook-correct output (concentric equipotential circles; tangential
right-hand-rule B field) -- high confidence. Point/Area tools share the
same verified interpolation code but weren't independently click-tested
(see the UI-automation note below -- the host was in active concurrent
use during this round, confirmed via `win32gui.GetForegroundWindow()`
changing mid-script, so heavy interactive automation was deliberately
scaled back in favor of code review + build verification).

**Update (2026-07-19, later still): user asked directly whether Round 3
covered the analysis (post-processor) window -- it hadn't.** Checking
`femm.rc`'s `IDR_FEMMVIEWTYPE` menu directly (rather than trusting my own
earlier summary) showed Zoom/Edit/several View items had only been added
to the geometry editor, not the Solution Viewer. Also caught a dead stub
in my own prior work: `MeshSolutionItem::setSmoothing()` was wired to a
member no paint method ever read. Filled in: Zoom menu, Copy as Bitmap,
real Smoothing (bands on node-averaged |B| -- `QPainter` has no native
triangle-gradient primitive so this approximates true Gouraud shading,
see `m_nodeBMagAvg`), Show Mesh/Points overlays, Status Bar toggle (added
to both windows -- missing from the geometry editor too), Reload, Recent
Files (shares `MainWindow`'s `QSettings` key), Switch to Classic GUI,
Help Topics/License, Integrate. Full accounting of what's still missing
(Circuit Props/BH Curves/Print/Preferences/Dark Theme/Lua Console/Output
Window) is in the plan doc's "Round 4" section.

**Real bug found via my own testing of this round's work**: zooming in
past ~8x on a real solved mesh showed black gaps between triangles in
the density plot. Root-caused (by toggling Smoothing on/off -- no
change -- and reloading fresh at low zoom -- clean) to `QPainter::
Antialiasing` being off (a pre-existing large-mesh-performance choice)
combined with triangles shrinking to a few screen pixels at high zoom --
a case only newly reachable because this round added zoom controls that
didn't exist before. Fixed with a scale-dependent AA toggle
(`SolutionGraphicsView::updateAntialiasingForScale()`, threshold 8x)
called after every zoom-changing operation. Worth remembering: adding a
new capability (zoom) can expose a latent issue in *unrelated*,
already-shipped code that was fine under the old, narrower reachable
state space -- re-test old features after adding new ways to reach them,
not just the new feature itself.

**`.qrc` resource paths and `CMAKE_AUTORCC` gotchas** (from the toolbar
icons work earlier the same day): a `.qrc`'s runtime resource path is
`prefix + "/" + alias` where alias defaults to the `<file>` element's
text verbatim -- `<file>icons/foo.svg</file>` under `prefix="/icons"`
resolves to `:/icons/icons/foo.svg`, not the shorter path you'd expect;
use an explicit `alias="foo.svg"` to get `:/icons/foo.svg`. Separately,
`qt_standard_project_setup()` does NOT reliably enable `CMAKE_AUTORCC` --
a `.qrc` listed in `qt_add_executable()`'s sources silently never got
compiled into a `qrc_*.cpp` until `set(CMAKE_AUTORCC ON)` was added
explicitly before the call, and the runtime symptom (`QFile::open(":/...")`
failing) doesn't point at the build system at all, easy to chase in the
wrong place. Also: this repo's `.gitignore` has a standalone `Icon?` line
(macOS Finder's cursed `Icon\r` custom-folder-icon convention) that
collides case-insensitively with any 5-letter directory literally named
`icons` on Windows git (`core.ignorecase`) -- new icon assets live in
`femmqt/toolbar_icons/`, not `femmqt/icons/`, to dodge this; don't touch
the `Icon?` rule itself, it's legitimate elsewhere.

**Double-click UI-automation gotcha (test methodology, not an app bug)**:
`pywinauto.mouse.double_click()` / `click_input(double=True)` did not
reproduce a genuine Qt double-click in this environment no matter the
timing -- confirmed via a temporary `mouseDoubleClickEvent` stderr trace
that Qt never received a coalesced double-click event, only two separate
single presses. A raw `ctypes`/`user32.SendInput`-style sequence
(`SetCursorPos` + `mouse_event(LEFTDOWN)` + 20ms + `mouse_event(LEFTUP)`,
~50ms gap, repeat) reliably registers as a real double-click. Reach for
this first next time double-click automation is needed against this app
rather than re-discovering it.

**Round 5 (2026-07-19, "implement these too"): the rest of Round 3/4's
deferred list, committed `c9f7e8d` on `new_features` (pushed).** User
explicitly rejected an `Agent`/subagent tool call for this round's
research -- all of it was done via direct `Read`/`Grep`, a hard
constraint for any further work on this codebase unless told otherwise.
Implemented, each a faithful port of the classic algorithm (not an
approximation) unless noted:
- **Create Radius**: all 3 cases (two segments/two arcs/one of each)
  ported from `femm/FemmeDoc.cpp`'s `CreateRadius` -- the tangent-circle
  geometry (up to 8 candidate solutions via `std::complex`, filtered by
  which actually touch both original entities) is in
  `FemmProblemEdit::createRadius`.
- **Create Open Boundary (ABC)**: `bin/init.lua`'s `mi_makeABC`, including
  the exact `u2D0`/`u2D1`/`uAx0`/`uAx1` permeability tables (n=1..12),
  transcribed verbatim into `OpenBoundaryDialog.cpp`.
- **Materials Library**: `MaterialLibraryIO` parses `bin/matlib.dat`'s
  `<BeginFolder>`/`<BeginBlock>` tree (same tags as `.fem`'s own
  `BlockProps`) into a browsable dialog.
- **DXF import/export** (`DxfIO.h/.cpp`): ports `femm/MOVECOPY.CPP`'s
  `ReadDXF`/`WriteDXF` line-for-line (POINT/LINE/ARC/CIRCLE/LWPOLYLINE/
  POLYLINE+VERTEX, bulge-factor arc splitting). One deliberate
  simplification, documented in the header: node merging is coincident-
  point dedup only, not classic's full `FancyEnforcePSLG`
  intersection-splitting -- a DXF with genuinely crossing, non-coincident
  geometry imports with those crossings unresolved.
- **Preferences + Dark Theme**: `AppPreferences` mirrors `GuiSwitch`'s
  tag-preserving femm.cfg read/write (the classic GUI's 5 keys +
  `<QtDarkTheme>`). `AppTheme` drives both `QApplication::setPalette()`
  and named scene colors that `GeometryScene`/`SolutionView` now read
  instead of hardcoded `Qt::black` etc. -- toggling calls `refreshTheme()`
  (a full `rebuild()`) since item colors are baked in at creation, not
  read live per-paint. Verified live: canvas, menus, and toolbar icons all
  repaint correctly on toggle.
- **CPU/GPU/RAM Load Monitor**: Qt-painted port of
  `femm/LoadMonitorDlg` (GetSystemTimes/NVML-dynamic-load/
  GlobalMemoryStatusEx same as the original). Exposed a real architecture
  gap while wiring it in: `SolveRunner::solve()`/`mesh()` used to call
  `QProcess::waitForFinished(-1)`, which blocks the event loop entirely --
  fine on its own, but it meant the Load Monitor's `QTimer` could never
  fire during a solve. Fixed by polling in short bursts and pumping
  `QCoreApplication::processEvents()` between them; `MainWindow` now
  disables its menu bar for the duration (that pumping makes a second
  concurrent solve/mesh reachable, which isn't safe -- both would write
  the same `.poly`/`.pbc`/`.ans` files).
- **Output Window**: a persistent dock in the Solution Viewer echoing
  every Point/Contour/Area result (classic FEMM only ever shows the
  *last* one in its docked `IDC_OUTBOX`; keeping a scrollback is strictly
  more useful and no harder).
- **Exterior Region dialog**, **Print/Print Preview** (Qt's built-in
  `QPrintDialog`/`QPrintPreviewDialog`), **Copy as Bitmap** for the
  geometry editor.

**Still deliberately deferred, with reasons** (not silently dropped):
Circuit Props and BH Curves need per-element J/sigma data (a
`GetJA`-equivalent current density calc, multi-turn `LocalEnergy`
correction, `PlnInt`/`AxiInt` integration) that `.ans`/`.ansx`/
`MeshSolutionElement` don't currently carry at all -- confirmed by
reading `femm/CircDlg.cpp` and `femm/FemmviewDoc.cpp`'s
`GetVoltageDrop`/`GetFluxLinkage` in full; this is a real numerical
feature on the order of the original `.ans` reader itself, not a
menu-item-sized task. Lua Console remains out of proportion
(`femmeLua.cpp` is thousands of lines). Copy as Metafile still skipped
(no clean cross-platform EMF path in Qt).

**Verification this round**: full local rebuild via `build_qt` (direct
`cmake --build . --target femmqt`, not the full `build.ps1`, for faster
iteration -- caught two real compile errors this way: `windows.h`'s
`max`/`min` macros clobbering `std::max`/`std::min` in
`LoadMonitorDialog.cpp`, needing `#define NOMINMAX` before the
`#include <windows.h>`). Then live-tested: launched the built exe,
force-foregrounded it (the established `keybd_event(VK_MENU)` +
`SetForegroundWindow` trick), and screenshotted the Edit/Problem/View
menus (all new items present), the Dark Theme toggle (canvas + toolbar
icons repainted correctly), the Preferences dialog, and the Load Monitor
dialog (GPU trace detected via NVML on this machine) -- all opened and
rendered correctly with no crash. Note for next time: pywinauto's
`Application.windows()`/`app.window(title=...)` did NOT enumerate a
QDialog as a top-level window in this environment (returned only the
main window) even though it was genuinely open and visible -- had to
fall back to raw `win32gui.EnumWindows` + `win32process.
GetWindowThreadProcessId` to find its real HWND, then drive it via
`win32gui`/`win32api` directly (or `app.window(handle=...)` once the
HWND is known) instead of pywinauto's own window-finding.

**Round 6 (2026-07-19, same day, "continue with the rest"): Circuit
Props and BH Curve editing, committed `5cc2ca5` on `new_features`
(pushed).** User pushed past Round 5's Circuit Props/BH Curves deferral;
delivered both. Lua Console stays deferred -- and got a second, sharper
reason while investigating: `liblua/CMakeLists.txt` calls
`find_package(MFC REQUIRED)` (`CMAKE_MFC_FLAG 2`), so femmqt (which
deliberately avoids MFC -- see this file's very first paragraph) can't
link the existing liblua target as-is; embedding Lua would mean building
a second, non-MFC variant of it first, on top of the ~200-function
`femmeLua.cpp` binding surface already flagged as its own project.

**BH Curve editing** (`BHCurveDialog.h/.cpp`): straightforward --
`FemmMaterialProp::bhData` was already read/written by `FemmFileIO.cpp`,
just not exposed for editing. A `QTableWidget` (B, H columns) plus a
Qt-painted linear/log chart, wired into `MaterialPropDialog` via a new
"Edit BH Curve..." button. Verified live: added rows, typed in a real
saturation-curve-shaped point set via raw coordinate clicks (pywinauto
couldn't address `QTableWidgetItem`s as `Edit` controls until a cell is
double-clicked into edit mode -- raw `win32api.mouse_event` double-click
at the cell's screen coordinates worked instead), and the chart rendered
the correct curve shape.

**Circuit Props** (`CircuitAnalysis.h/.cpp`) -- the one worth reading
carefully before touching again. Ported `femm/FemmviewDoc.cpp`'s
`GetVoltageDrop`/`GetFluxLinkage`/`GetJA`, solid-conductor branches only
(stranded/litz needs `GetFillFactor`'s frequency-dependent curve fits,
not ported; zero-current circuits need a separate mutual-inductance
cascade, not ported -- both rejected with a clear `Result::error` rather
than guessed at). The real story is the validation method, not the
formulas themselves:

1. First pass: derived the solid-conductor voltage/current relationship
   from first principles (Kirchhoff's current law over the block, solving
   for the unknown terminal voltage) rather than trusting a literal
   source port, out of concern that classic FEMM's own length-unit
   conventions (`LengthConv[LengthUnits]`) might not be applied
   consistently across the functions involved.
2. That derivation was WRONG -- off by exactly the length-conversion
   factor (1000x for a millimeters file) -- caught only by an empirical
   check: opened the *same* real solved file
   (`test/results/straight_wire_field/straight_wire_field.ans` -- a 10A
   DC single-solid-conductor series circuit, currently untracked/
   uncommitted local test data, not yet in git) in the classic GUI
   (`bin/plain/femmx.exe`) via the same UI-automation approach used
   throughout this session, read its actual Circuit Properties dialog
   output (Voltage Drop = 5.48984e-05 V, Flux Linkage = 1.1653e-08 Wb),
   and cross-checked a standalone Python re-implementation against it.
3. Root cause: `Depth` (planar) DOES need `LengthConv` to meters in the
   final `Volts = -Depth*dVolts` formula, but the raw `dVolts` value read
   directly from `.ans`'s block-label circuit-info section (right after
   the node/element lists in `[Solution]`, written by
   `fkn/prob1big.cpp`'s `WriteStatic2D`) is used as-is, NOT further
   converted -- an inconsistency-looking mix that's exactly what the real
   source does, and exactly what an "obviously correct" reasoned
   re-derivation got wrong.
4. After fixing, re-verified BOTH the standalone Python calc AND the
   actual built Qt app's Circuit Properties dialog against the same
   file -- byte-identical to the classic GUI's displayed values (Total
   current, Voltage Drop, Flux Linkage, Flux/Current, Voltage/Current,
   Power all matched).

**Round 7 (2026-07-19, same day, "skip the lua console, make sure
everything else is added... show coordinates when drawing... and the
value of the field when hovering"), committed `65df00f` on
`new_features` (pushed).** Two explicitly-requested live status-bar
readouts, plus a fresh femm.rc audit now that the big deferred-list items
were done (found real remaining gaps: Print Setup was missing in both
windows, Print/Print Preview/Print Setup were missing *entirely* from
the Solution Viewer, Delete/Open Selected had no menu items -- keyboard/
double-click only -- and the Solution Viewer had no read-only "BH
Curves" viewer distinct from the geometry editor's editable one).
- **Mouse-position readout** (geometry editor): `GeometryScene::
  mousePositionChanged` emitted from `mouseMoveEvent` (grid-snapped),
  driving a permanent status-bar `QLabel` in `MainWindow`. Needed
  `GeometryView::setMouseTracking(true)` -- without it, `QGraphicsScene::
  mouseMoveEvent` only fires while a button is held (dragging), not on
  plain hover.
- **Field-value-on-hover readout** (Solution Viewer): `SolutionGraphicsView::
  hoveredAt`, reusing the Point tool's own `findContainingElement`/
  `interpolateA`. Throttled to ~20 updates/sec (`QElapsedTimer`) --
  `findContainingElement` is a documented linear scan over every mesh
  element, fine for one deliberate click but not for firing on every
  pixel of mouse movement across a multi-million-element mesh.
- Verified live for both: screenshotted the status bar mid-hover over the
  straight-wire test file -- showed live x/y plus `|B|`/`A` matching the
  known-correct field pattern at that point.

**Round 8 (2026-07-19, same day, 3 direct fixes: dark-theme text
contrast, cursor-following coordinates "like Fusion 360", and toolbar
icons), committed `f191e1a` on `new_features` (pushed).**
- **Dark theme text-field bug, found and fixed**: `QLineEdit`/
  `QComboBox` backgrounds stayed a light native gray with barely-visible
  near-white text in every dialog, even though the custom `QPalette` was
  applied and OTHER widgets (labels, checkboxes) went dark correctly.
  Root cause, confirmed by screenshotting Problem Properties before/
  after: Windows' native styles (windowsvista/windows11) render those
  two controls from OS theme chrome rather than fully honoring a custom
  `QPalette::Base`. Fix: `AppTheme::setDark(true)` now also switches to
  the Fusion style (Qt's own recommended style for custom palettes --
  the ONLY style that reliably honors every palette role), restoring
  whatever native style was active at startup on light mode. **Lesson
  for any future Qt dark-mode work on Windows**: a custom `QPalette`
  alone is not sufficient for full theming on native Windows styles --
  pair it with `QStyleFactory::create("Fusion")` or expect exactly this
  kind of silently-wrong-contrast bug in text-entry widgets specifically.
- **Cursor-following coordinate/value readout** ("like Fusion 360"): a
  floating `QLabel` parented to the viewport, repositioned on every
  mouse move (offset down-right of the cursor, clamped to the viewport
  edges) -- `GeometryView` shows the live model-space coordinate while
  drawing, `SolutionGraphicsView` shows coordinate + interpolated `|B|`/
  `A`. Additive to the fixed status-bar readouts added in Round 7, not a
  replacement -- both now show the same live text.
- **Toolbar icons**: searched `femm.rc`'s actual `TOOLBAR` resource
  blocks (`IDR_FEMMETYPE`, `IDR_LEFTBAR`, `IDR_FEMMVIEWTYPE`) for the
  authoritative icon list per direct user request ("list all the icons
  used... by searching in the old GUI") rather than guessing -- found
  the Solution Viewer had **no toolbar at all** (text menus only) and
  the geometry editor only had its original 5 drawing-tool icons.
  ~32 new SVGs added to `toolbar_icons/` (same `CURRENTCOLOR`-
  placeholder convention as the existing 5). Wired into 4 new toolbars
  total: geometry editor gets Edit (Undo/Open Selected/Delete/Move/Copy/
  Scale/Mirror/Create Radius/Create Open Boundary/Select by Group), Mesh
  (Create Mesh/Solve/View Results), and a left-docked Navigate toolbar
  (Zoom/Pan/Grid, matching `femm.rc`'s own separate `IDR_LEFTBAR`
  layout); Solution Viewer gets one Operation toolbar (Point/Contours/
  Areas/Plot X-Y/Integrate/Circuit Props/Show Mesh/Contour/Density/
  Vector Plot). Checkable actions reuse the exact same `QAction` objects
  their menu items already created (not copies) so toolbar buttons and
  menu checkmarks never drift apart -- `MainWindow`/`SolutionWindow` each
  got an `addThemedAction()` helper that remembers every new action's
  icon path in `m_themedActions` so `refreshToolbarIcons()` re-tints all
  of them (not just the original 5) after a dark/light toggle.
- Verified live: screenshotted both windows' toolbars in light and dark
  mode (icons correctly re-tint), the floating tooltips tracking the
  cursor with live text in both windows, and the fixed dark-theme dialog
  fields (white-on-dark, confirmed before/after the Fusion-style fix).

**Round 9 (2026-07-19, same day, 3 more direct requests: 2-second hover
help text on every icon, "make sure all icons have the implemented
functionality and test it", and boundary-condition edge coloring),
committed `1accc3c` on `new_features` (pushed).**
- **2-second hover tooltips** (`HoverTooltip.h/.cpp`): Qt's own tooltip
  appears almost instantly (~700ms) -- this suppresses that (`QEvent::
  ToolTip` swallowed in an event filter) and shows the same text itself
  via `QToolTip::showText()` from an `Enter`-triggered 2000ms `QTimer`
  instead. Every toolbar action in both windows got an explicit
  `setToolTip()` -- text pulled from `femm.rc`'s own `STRINGTABLE`
  where a description exists for that command ID (confirmed most core
  edit/mesh/zoom/pan/grid commands DO have one there), written fresh for
  Qt-only commands (Dark Theme, Load Monitor, Circuit Props, plot
  modes) that have no classic equivalent. Verified by screenshotting a
  button at 0.8s (nothing) and 2.2s (tooltip visible, correct text).
- **Comprehensive click-through verification**: opened a real test file
  and clicked every single toolbar button in both windows, checking for
  a REAL effect (dialog opened with sane content, geometry actually
  changed, files actually written), not just "didn't crash". Caught and
  fixed a genuine TEST-SCRIPT bug worth remembering for next time: using
  `win32gui.GetWindowRect` (full window incl. title bar) instead of the
  client area for click coordinates silently misaligned every click by
  the title-bar height -- fixed by using `win32gui.ClientToScreen(hwnd,
  (0,0))` as the coordinate origin instead. Also hit a **modal-dialog-
  eats-later-clicks** trap: a `QDialog::exec()`-opened dialog left open
  by an earlier test step silently absorbed every subsequent synthetic
  click in the same script (no crash, no visible effect) -- looked
  exactly like "button does nothing" until checking for a stray already-
  open window. Confirmed genuinely working, with real evidence, not just
  a click: Create Mesh (fresh `.node`/`.ele`/`.poly`/`.pbc` files with
  matching timestamps), Zoom In (5 clicks visibly revealed individual
  mesh triangles), Zoom Window (a real multi-step rubber-band drag
  correctly reframed the view -- a single-jump `SetCursorPos` drag
  without intermediate move steps did NOT register with Qt, worth
  remembering: synthetic drags need multiple intermediate `SetCursorPos`
  calls, not just press-at-A/release-at-B), Delete+Undo (node removed,
  then restored), Solve (produced a real solved `.ans`, auto-opened the
  Solution Viewer), and in the Solution Viewer: Point/Contours/Areas
  (each produced correct results, all three echoed to the Output
  Window), Circuit Props (reproduced this session's earlier-validated
  reference numbers exactly, again), Density/Contour/Vector plot mode
  (Vector mode visibly showed real directional arrows).
- **Boundary-condition edge coloring** (`AppTheme::boundaryEdgeColor()`,
  wired into `GeometryScene::addSegmentItem`/`addArcItem`): a segment or
  arc with `boundaryMarker != 0` now renders in a distinct orange shade
  instead of its normal segment/arc color -- classic FEMM has no
  equivalent, purely a modern-CAD-style affordance. Free-riding on
  already-existing behavior: `MainWindow::onEntityDoubleClicked` already
  unconditionally calls `m_scene->rebuild()` after any accepted property
  edit, so this recolors automatically the moment a boundary condition
  is assigned/cleared via the properties dialog -- no new refresh logic
  needed. Verified live against a file with a real Dirichlet ("A=0")
  boundary on its outer arc -- rendered orange as expected.

**Lesson, worth remembering beyond this one feature**: when a classic-
FEMM formula involves `LengthConv`/unit conversions, do not trust a
"this looks dimensionally sensible" re-derivation over a literal port --
this codebase's internal unit conventions are inconsistent enough
(confirmed directly: the same physical quantity is converted in one call
site and left raw in another, apparently deliberately, not a typo) that
only two things are reliable: (a) a literal, line-by-line port of the
actual source, or (b) empirical validation against the classic GUI's own
output on a real file. Prefer having both, as this round ended up doing.
The `bin/plain/femmx.exe` + UI-automation-screenshot technique (already
established this session for other verification) is directly reusable as
an oracle for any future post-processing/numerical feature ported from
`femm/FemmviewDoc.cpp` -- worth reaching for immediately rather than
trusting a from-scratch derivation, given this session's experience.

## Round 10: v2.0.0 -- Qt becomes the sole Start Menu entry, a real MFC bug found via user report (2026-07-19/20)

Committed `d2eb7c8` on `new_features` (pushed). User reported "switch to
qt gui did not work for me" / "the application crashed" after launching
"FEMMX (Classic)" from the Start Menu and using its Solution Viewer's
"Switch to Qt GUI..." menu item.

**Real bug, confirmed by direct reproduction, not the user's environment**:
`femm/FemmviewView.cpp`'s `CFemmviewView` (the classic GUI's post-
processor) had a fully-implemented `OnSwitchToQtGui()` handler and a
correctly-declared header/menu-resource entry, but the
`ON_COMMAND(ID_VIEW_SWITCHTOQT, OnSwitchToQtGui)` line was simply
missing from its `BEGIN_MESSAGE_MAP`/`END_MESSAGE_MAP` block -- clicking
the menu item silently did nothing (not a crash; "did not work" was the
accurate half of the report). `femm/FemmeView.cpp` (the pre-processor/
editor)'s copy of the same feature *was* wired correctly, which is why
reproducing against the editor first showed nothing wrong -- only
testing the post-processor specifically (`.ans` file, not `.fem`)
surfaced it. **Reproduction technique**: launch `femmx.exe <file>` as a
real subprocess, find its real window via `win32gui.EnumWindows` +
`win32process.GetWindowThreadProcessId` filtered to that PID (there can
be more than one top-level window -- e.g. a modeless "FEMM Output"
dialog, class `#32770`, alongside the real main frame; grabbing the
first enumerated match without checking the title is a trap), then
`win32gui.PostMessage(hwnd, win32con.WM_COMMAND, <resource.h ID>, 0)` --
exactly reproduces a real menu click for MFC's command routing (verified
`GetMenu`/`GetSubMenu`/`GetMenuItemID` walk to confirm the ID is really
in that window's menu tree first), and poll `proc.poll()` / `Get-Process
-Id ... | Responding` afterward to distinguish "silently did nothing"
(still alive, responsive, no effect) from a real crash/hang. Fix: one
added `ON_COMMAND` line.

**Per user request, also removed the "FEMMX (Classic)" Start Menu
shortcut** (`script.nsi`) -- a user following it out of habit is exactly
who hit the bug above. `femmx.exe` stays fully installed (still load-
bearing: `femm.ActiveFEMM` COM automation, and the only option for
electrostatics/heat-flow/current-flow, which femmqt doesn't support
yet), just no longer pinned to the Start Menu -- reachable via
`bin\femmx.exe` directly or the Qt GUI's own "Switch to Classic GUI".
`FEMMX.lnk` now launches `femmqt.exe` exclusively. This is a real
behavior change other users of the installer will notice.

**Version bumped to 2.0.0** (major, not patch -- marks Qt becoming the
default a fresh install actually launches): `femm/femm.rc`'s
`FEMMX_VERSION_MAJOR`/`MINOR` macros + the 2 hardcoded strings
(`IDD_ABOUTBOX`, `IDR_MAINFRAME` STRINGTABLE) that can't use the macro
(rc.exe rejects it there, RC2116/RC2108 -- established in the v1.2.0
round), `script.nsi`'s `PROJECT_VERSION`, `CHANGELOG.md`. **Not tagged**
-- version bump only, per explicit instruction; tagging/merge-to-main is
a separate, not-yet-done step (see [[release_tagging_workflow]]).

**Found while touching versioning: `manual/manual.tex` is gitignored**
(`.gitignore:38`, pre-existing, not something this session added) -- so
the v1.2.0-era changelog's claim of updating the manual's title page
never actually landed (found it still hardcoded "1.1.1" from the v1.1.1
round). Fixed locally (now says "2.0.0") but that edit is *not*
committed/pushed and never will be under the current `.gitignore` --
flagged to the user rather than unilaterally changing `.gitignore`
(their call whether that's intentional or an oversight).

**Build hygiene lesson, expensive to learn**: killing a `build_cuda.bat`
mid-compile (via `TaskStop` on the background task) does NOT clean up
`bin\` -- whatever CMake had already written there (in this case ~900MB
of CUDA runtime DLLs, staged early via an `install(FILES ...)`-style
step, well before final linking) sits there and silently contaminates
the *next* build, regardless of variant. Concretely: a killed CUDA build
left `cudart64_12.dll`/`cublas64_12.dll`/etc. in top-level `bin\`; the
next `build_plain.bat` run's move-to-`bin\plain\` step swept them in
too, producing a 664MB "plain" installer (should be ~32MB) that bundled
CUDA libraries a CPU-only build has no business shipping, and separately
made `test/gpu_solver_test.py` wrongly detect the plain build as CUDA-
capable (see [[gpu_speedup_investigation]] for the test-heuristic
detail). Fix used: `git clean -ndx bin/` (dry run first) then `-fdx` --
safe because the 6 static data files (`condlib.dat`, `heatlib.dat`,
`init.lua`, `license.txt`, `matlib.dat`, `statlib.dat`) are git-tracked
and `git clean` never touches tracked files, so it's the right tool for
"wipe build output, keep source assets" in this repo specifically.
**Rule going forward**: never trust `bin\` after killing a build
mid-flight -- `git clean -fdx bin/` before the next build, every time.

**GPU regression test results this round** (see
[[gpu_speedup_investigation]] for full detail and the older, conflicting
DC-speedup numbers): full plain-build suite clean (15 passed, 2 correctly
skipped, run in isolation -- no concurrent build). CUDA build's own
correctness checks pass perfectly on both DC and AC problems; AC/harmonic
GPU solve genuinely 3.16x faster, but DC/real-valued GPU solve measured
3x *slower* than CPU this round -- left as an honest failing assertion,
not investigated further (out of scope), not worked around.

## Round 12: geometry editor zoom/pan stutter -- FullViewportUpdate, fixed by porting SolutionGraphicsView's own prior fix (2026-07-21)

User: "the problem i find is that when i zoom i[n] or move the geometry
is not smooth." Found via direct code reading (no Agent/subagent, per
the standing constraint from Round 5): `GeometryView`'s constructor set
`setViewportUpdateMode(QGraphicsView::FullViewportUpdate)` to fix a
stale-tooltip-trail bug (the floating cursor coordinate readout is a
plain `QLabel` child of the viewport, not a scene item, so
`MinimalViewportUpdate`'s scene-change-driven dirty tracking doesn't
know to repaint its old position when it moves). But `FullViewportUpdate`
forces a full repaint on **every** viewport update, not just tooltip
moves -- including every wheel-zoom (`scale()` in `wheelEvent`) and
every toolbar/scrollbar pan (`onPanLeft/Right/Up/Down` in
`MainWindow.cpp`, plain `scrollBar->setValue()` calls, which normally
get a cheap blit-and-fill-the-new-strip optimization that
`FullViewportUpdate` disables) -- exactly the reported stutter.

**The fix already existed in the codebase, just not ported.**
`SolutionGraphicsView::mouseMoveEvent` (`SolutionView.cpp`) had already
solved the *identical* tooltip problem the right way:
`scene()->invalidate(mapToScene(oldGeometry).boundingRect())` on just
the tooltip's vacated rect -- `scene()->invalidate()` is the mechanism
`MinimalViewportUpdate` actually respects for "redraw this region even
though nothing scene-side changed." Its own comment even names a PRIOR
"everything is slow on large geometries" complaint that motivated that
fix -- meaning this exact class of regression had already been found
and fixed once, in the solution viewer, and just never got applied to
the geometry editor. Ported it: removed `GeometryView`'s
`FullViewportUpdate` call entirely, added the same
`scene()->invalidate()` call to its `mouseMoveEvent`. Zoom and pan now
go through Qt's efficient default update path; only genuine mouse-hover
moves pay the (correctly-scoped) invalidate cost, same frequency as
before.

**Lesson**: when two sibling classes solve the same UI problem (here:
`GeometryView` and `SolutionGraphicsView`, both `QGraphicsView`
subclasses with an identical floating-tooltip pattern), check whether
one already has a better fix before re-deriving one -- grep for the
similar class name/pattern first, don't assume symmetry has to be
re-verified from scratch every time.

**Verified live**: built via `build_qt` (`cmake --build build_qt --target
femmqt`), then launched the real exe against a loaded `.fem`, swept the
cursor across the canvas with synthetic `SetCursorPos` calls, and
screenshotted -- confirmed exactly one tooltip label at the final
position, no stale trail left behind anywhere along the path. Confirms
`FEMMQT_HAVE_OPENGL` is active in this build too (`QOpenGLWidget`
viewport, per the constructor's `#ifdef`), so the fix is layered on top
of already-GPU-composited rendering, not fighting it.

**Separately investigated but not (yet) fixed**: `MeshSolutionItem`'s
constructor (`SolutionView.cpp:104-166`, runs synchronously on the UI
thread every time a solved file opens) does 6 full passes over every
mesh element -- one per `DensityQuantity` enum value -- eagerly
precomputing node-averaged values and min/max ranges for all 6 plot
quantities, even though a session typically only ever looks at 1-2.
Not captured by the file's own `QElapsedTimer` load-time profiling
(that timer stops *before* this constructor runs) so it's an invisible
cost in whatever load-time numbers already exist. Recommended fix:
lazy per-quantity computation on first actual use instead of eager-all-6
at construction. Not implemented -- flagged to the user, awaiting a
decision on whether it's worth doing (tradeoff: switching density
quantities mid-session would get a one-time hitch instead of being
instant, in exchange for a faster initial big-file open).

## Round 12b: floating tooltip removed entirely; mesh-point-dots-grow-when-zoomed bug fixed (2026-07-21, same day as Round 12)

Follow-up to Round 12 (zoom/pan stutter fix). User: "if the moving text
box slows down things, remove and make it stationary somewhere." Rather
than keep tuning `GeometryView`'s floating cursor-following tooltip
(the thing that needed the `scene()->invalidate()` workaround at all),
removed it entirely -- `GeometryView::mouseMoveEvent`/`leaveEvent` are
now just the base `QGraphicsView` behavior (no override needed). The
stationary status-bar coordinate readout (`MainWindow::m_positionLabel`,
wired independently via `GeometryScene::mousePositionChanged`, added
back in Round 7) shows the same x/y info with zero per-move viewport
cost -- confirmed nothing was lost by checking it live after the
removal. **Left `SolutionGraphicsView`'s identical floating tooltip
alone** -- user's ask was scoped to "the geometry" (the editor), and
that one already uses the cheap `scene()->invalidate()` approach with
no reported complaint against it.

User then asked: "when the geometry is zoomed, I want the edges and
points to not appear thicker -- is this some kind of vector graphics?"
plus "same in solution viewer, I want an option to show the edges and
points." Investigated both:

- **Answer to the conceptual question**: it's not really about "vector
  vs. raster" per se (an SVG zoomed via image scaling would ALSO get
  thicker lines) -- it's specifically whether the pen width is defined
  in *device pixels* (a "cosmetic" pen, `QPen::setCosmetic(true)`) vs.
  *scene/world units* (the default, which DOES scale with zoom). The
  classic GDI-based GUI gets the same constant-width effect via
  `PS_COSMETIC` pens.
- **Geometry editor**: already correct in current source --
  `GeometryScene.cpp` sets `pen.setCosmetic(true)` on every segment/arc/
  node pen, and `NodeItem`/block-label markers already use
  `ItemIgnoresTransformations` for constant on-screen size. Tested
  directly (built via `build_qt`, zoomed ~264x on a real loaded model,
  screenshotted before/after) and could NOT reproduce any thickening --
  edges and node dots stayed visually the same size. **If the user still
  sees this, they're very likely testing an older installed/pre-built
  exe** (the Start Menu shortcut, or a `bin\plain\`/`bin\cuda\` copy from
  earlier in this session), not current source -- worth asking which
  exe before assuming a live bug exists.
- **Solution Viewer -- real bug found and fixed**: "Show Mesh" and
  "Show Points" already existed as checkable View-menu items
  (`SolutionView.cpp`'s `viewMenu->addAction("Show &Mesh"/"Show
  &Points")`, wired since Round 4) -- confirmed live via a real menu
  click + screenshot that "Show Mesh" already renders correctly. But
  `MeshSolutionItem::paintMeshOverlay`'s "Show Points" dots WERE
  genuinely growing with zoom: `drawEllipse(pos, r, r)` used
  `r = model_diagonal * 0.0015`, a fixed SCENE-space value, unlike the
  mesh edges just above (a cosmetic `QPen`, correctly zoom-invariant).
  `QPen::setCosmetic` only affects *stroked* lines, not a filled
  shape's own geometry -- a filled circle needs the equivalent done by
  hand: divide a fixed on-screen pixel radius by
  `painter->worldTransform().m11()` (the app only ever does uniform
  `scale()` zooming, never skew, so `m11()` alone is a safe proxy for
  the current zoom factor without needing a full singular-value
  decomposition). Fixed, verified live (built, enabled Show Points,
  screenshotted before/after a ~13x zoom -- dots stayed small and
  consistent instead of growing into blobs).

**UI-automation gotcha hit again this round**: keyboard menu mnemonics
(`Alt+V` then a letter) misfired at least once -- landed on "Contour
Plot" instead of "Show Mesh"/"Show Points", turning the whole density
plot into a solid-white contour render that looked like a rendering bug
at first glance. Switched to direct mouse clicks on the menu (open View,
screenshot to find the exact row, click it) instead, which worked
reliably. **Also**: `SolutionWindow`'s actual canvas center is NOT the
client-rect center -- the docked Output Window panel eats a large
fraction of the bottom of the window, so a wheel-zoom aimed at the
naive client-rect midpoint can land on the Output Window instead of the
canvas and silently do nothing (looked like "zoom doesn't work" until
traced to aiming at the wrong widget). Use a screenshot-verified
canvas-area point instead of assuming client-rect center is inside the
graphics view for this specific window.

## Round 12c: "white screen" in Contour Plot root-caused (not fixed); original problem geometry was entirely missing from the Solution Viewer (fixed) (2026-07-21, same day)

User: "i see a white screen there, is it supposed to look like this?"
(Contour Plot mode, the default -- see Round 12b -- on
`gpu_solver_cpu.ans`, a wire+ABC magnetics model).

**Root-caused, not yet fixed**: confirmed `paintContour`'s algorithm
itself is correct by opening a clean reference file
(`straight_wire_field.ans`) -- renders textbook concentric circles.
Directly measured `gpu_solver_cpu.ans`'s node values (two ways: parsing
`[Solution]` in the raw `.ans` text directly, AND a slow ~38K-node
`mo_getpointvalues` COM loop as a cross-check) -- the vector potential
A itself has NO extreme outlier values (smooth percentile distribution,
p1-p99 span is 72% of the full span). But switching the SAME file to
Density Plot revealed the real story: `|B|` is anomalously HIGH in a
ring right at the outer domain boundary (>3.66e-3 T there vs. ~2-6e-4 T
everywhere else) -- almost certainly from `mi_makeABC`'s multi-layer
Kelvin-transform boundary construction. Since Contour Plot spaces its
20 levels evenly across A's *value* (not radius), and that thin outer
boundary region evidently accounts for a large fraction of A's total
dynamic range despite being geometrically thin, nearly all 20 contour
lines end up compressed into/near that boundary -- exactly what the
NEW geometry-overlay feature (below) then visually confirmed: you can
literally see the multiple closely-packed ABC layers there once
segment/arc geometry is drawn. **Offered but not implemented**: making
Contour Plot's level computation more robust (e.g. percentile-based
instead of true min/max) -- user hasn't asked for this yet.

**Real, separate feature gap found and fixed**: user's follow-up, "in
the solution viewer the edges and nodes of the geometry do not show
up." Checked `femm/FemmviewView.cpp` directly -- the classic GUI
ALWAYS overlays the original problem geometry (nodelist/linelist/
arclist -- the actual nodes/segments/arcs drawn in the pre-processor,
e.g. "20 nodes, 20 arcs") on top of whichever plot is active in the
post-processor, completely distinct from the solved FE MESH (millions
of elements). femmqt had genuinely nothing for this -- "Show Mesh"/
"Show Points" only ever meant the solved mesh's own triangulation/
nodes. Added `MeshSolutionItem::setProblemGeometry()`/
`paintProblemGeometry()` (`SolutionView.cpp`/`.h`): segments/arcs as
cosmetic-pen lines (`AppTheme::segmentColor()`/`arcColor()`, matching
the geometry editor's own colors -- arcs via an independent copy of
`GeometryScene.cpp`'s `arcGeometry()` math, this codebase's established
precedent over a shared header), nodes as small fixed-screen-size
squares (same divide-by-`worldTransform().m11()` technique as the
mesh-point-radius fix two rounds ago). Always drawn when available, no
new toggle -- matches classic's own unconditional behavior for
segments/arcs.

`SolutionWindow` didn't have the original `FemmProblem` at all before
this (only the `MeshSolution`) -- `openAnsFile()`'s two load paths
needed different plumbing: the slow (.ans direct) path already parses
`FemmProblem` as a side effect of extracting `problemType`/
`lengthUnits`/`frequency`, so it's now just kept (`m_problemGeometry =
problem;`) instead of discarded; the fast (.ansx cache) path has
nothing to reuse (the cache only ever stores the mesh, by design), so
it does one extra best-effort `FemmFileIO::readFem()` call against the
`.ans` file -- already proven safe/fast against `.ans` files elsewhere
in this exact class (`onProblemInfoTriggered`/`onCircuitPropsTriggered`/
`onBhCurvesTriggered` all do the same thing already).

Verified live against both files mentioned above -- concentric boundary
arcs and node markers now clearly visible over the density plot in
both, and neither grows when zoomed (confirmed by construction, reusing
the just-established fixed-screen-size technique, not just assumed).

## Round 11: real installer bug behind "the shortcut doesn't work" -- missing Qt6PrintSupport.dll (2026-07-20)

Committed `47b3414` on `new_features` (pushed), plus two CI-only commits
(`65d9a67`, `4bc1b38`) fixing an unrelated Qt6-install-in-CI mirror/module
issue found along the way (see [[build_and_com_registration_gotchas]] for
that one). User reported the installed app's Start Menu shortcut "doesn't
work" after installing the real `bin\cuda\FEMMX_v2.0.0_installer.exe` --
this turned out to be a second, genuine bug, unrelated to Round 10's
message-map fix: `script.nsi` bundled `femmqt.exe`'s Qt6 DLLs via
individually-named `File` lines, and `Qt6PrintSupport.dll` (added when
femmqt gained Print/Print Preview support) was never added to that list.
Every installed copy silently shipped without it. Symptom was NOT a loud
"DLL missing" dialog -- `femmqt.exe` would start, load 41 DLLs, then hang
forever (0% CPU, zero windows, `qwindows.dll` never loaded) -- see
[[build_and_com_registration_gotchas]] for the full diagnostic play-by-
play (module-count polling, CPU-delta deadlock check, `Compare-Object`
directory diffing, `dumpbin /dependents`) and the fix (switched to a
`Qt6*.dll` wildcard). Verified end-to-end this round: clean uninstall,
fresh silent install from the rebuilt installer, launched via the real
`FEMMX.lnk` Start Menu shortcut, screenshotted working.
**Also worth remembering**: ~13 failed test launches from before the fix
each left an undismissed native "System Error" dialog on screen (owned by
`csrss.exe`, not the failed app's own PID) -- a *later*, genuinely-working
launch's screenshot (a screen-region capture, not a true per-window
capture) visually picked up one of those stale overlapping dialogs,
making the fix look broken until the stale dialogs were found via
`EnumWindows` and closed. Don't trust a "still broken" screenshot without
checking what's actually still on screen from earlier test runs.

## Round 13: spurious vertical line when arcs form a circle -- Qt's arcTo angle convention needed a sign flip; undo extended to a 20-step stack (2026-07-21/22)

User reported a spurious straight line appearing when arcs are drawn to
form a circle, in both the geometry editor and Solution Viewer, most
visibly on ABC-boundary shell circles (e.g. `test/results/straight_wire_field/straight_wire_field.fem`'s outermost, boundary-marked shell pair).
Root-caused via a minimal from-scratch repro (a 2-node, 1-or-2-arc `.fem`,
isolating every variable the real file had -- mesh overlay, block labels,
9 nested shells, etc.) rather than continuing to stare at the 20-arc
file: a single 180-degree, exactly-vertical arc reproduced it standalone,
proving the CURVE itself rendered correctly (both semicircle bulges
present, correctly shaped) but grew an EXTRA straight bridging line from
the `moveTo()` point to a second point.

Cause: `arcGeometry()`'s `startAngleDeg = atan2(y0 - cy, x0 - cx)` used
plain math atan2, but `QPainterPath::arcTo`'s own point-at-angle formula
effectively negates the y-term (Qt's documented convention: 0 deg = 3
o'clock, 90 deg = 12 o'clock, even though scene y increases downward --
confirmed by deriving the y0=2*cy-y0 mirror relationship and checking it
against Qt's own worked example). Whenever Qt's own arc-start point
(computed from our `startAngleDeg` via ITS formula) didn't match the
`moveTo()` point we'd already placed, Qt bridged the two with a straight
line before drawing the curve. For a 180-degree, purely-vertical arc,
the y-mirror of the start point lands EXACTLY on the opposite node --
maximally visible as a full diametric line -- which is why this went
unnoticed for non-vertical/non-180 arcs (the mismatch there is a shorter,
easy-to-miss bridging segment or a wrong-bulge-direction curve, not a
dramatic full-height line).

Fix: negate the y-term -- `atan2(-(y0 - cy), x0 - cx)` -- applied
identically to both independent copies of `arcGeometry()`
(`GeometryScene.cpp` and `SolutionView.cpp`, per this codebase's
established precedent of independent copies over a shared header, see
Round 9's note on the same function). Verified empirically, not just by
re-deriving the math again: (1) minimal 1-arc and 2-arc vertical repros
both went from "curve + spurious diameter line" to "clean curve, no
line"; (2) the real `straight_wire_field.fem` file, opened fresh (after
deleting its stale `.femx` cache) with NO click performed, rendered with
zero stray lines -- the earlier "still broken" screenshot in this same
investigation turned out to be a SEPARATE artifact: the repro script's
own diagnostic click (deliberately aimed at the old bug's line location)
was landing on the now-correctly-positioned arc's edge and selecting it,
and Qt's default dashed-selection-rectangle outline (one edge sitting
exactly on the shared node x-coordinate) was being mistaken for a
surviving version of the original bug; (3) an asymmetric, off-axis,
non-90-degree arc (endpoints (30,5) and (10,25), 75-degree sweep)
rendered identically in femmqt and the classic GUI (via COM automation
screenshot comparison) -- confirms the fix produces the geometrically
*correct* bulge direction, not merely "no visible line" for the
symmetric cases that happened to be tested.

Same session, follow-up request: extend `MainWindow`'s undo from a
single overwritten snapshot (`m_undoSnapshot`/`m_hasUndo`, matching
classic FEMM's own single-slot `CFemmeDoc::UpdateUndo`/`Undo`) to a
20-step stack. Mechanical change -- `QList<FemmProblem> m_undoStack`
capped at `kMaxUndoSteps = 20` (push in `snapshotForUndo()`, evicting the
oldest via `pop_front()` once over the cap; `onUndoTriggered()` pops via
`takeLast()`) -- covering the exact same 7 call sites as before (Create
Radius, Create Open Boundary, Import DXF, Move/Copy/Scale/Mirror
Selected, and Delete Selected via the `aboutToEdit` signal); still no
redo (wasn't requested, and classic FEMM doesn't have one either).
Verified two ways, both via UI automation with numeric ground truth
(reading saved `.fem` node coordinates back, not just eyeballing
screenshots): (1) 3 sequential single-node deletes followed by 4 Ctrl+Z
presses showed the node count step correctly back up 2->3->4->5 with the
status bar reporting "Undone (N more steps available)" at each step, and
the 4th (extra) undo correctly reported "Nothing to undo"; (2) a 25-node
file with 25 sequential `Move (+1,0)` operations (using a rubber-band
re-select before each -- `rebuild()` after a move does not preserve the
graphics-item selection state, so a stale selection would silently hit
"Nothing selected" on the 2nd+ iteration if not re-selected) followed by
21 Ctrl+Z presses: saving and reading the `.fem` back at each checkpoint
showed +25mm after the moves, +5mm after 20 undos (exactly 20 of 25
recovered, confirming the cap evicts the oldest 5), and still +5mm
unchanged after the 21st undo (confirming it correctly no-ops once the
stack is empty rather than under- or over-shooting).
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

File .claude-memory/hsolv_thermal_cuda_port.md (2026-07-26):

---
name: hsolv-thermal-cuda-port
description: "CUDA-accelerated linear solve ported from fkn (magnetics) to ALL THREE other solvers -- hsolv (heat), belasolv (electrostatics), csolv (current flow) -- plus *_setgpuaccel/*_setredraw Lua commands for each. Shipped on new_features."
metadata: 
  node_type: memory
  type: project
  originSessionId: 846a52dc-e5cc-4b0f-9a4f-7b5debeae297
  modified: 2026-07-21T14:48:39.167Z
---

Implemented and shipped 2026-07-21 in three commits on `new_features` in
`femmx` (see [[push_branch_policy]]): `8e9093f` (hsolv/heat), `6e1f271`
(belasolv/electrostatics + csolv/current-flow), `72f4b5f` (CHANGELOG +
CI fix). Direct continuation of [[gpu_speedup_investigation]]'s
architecture (originally fkn/magnetics-only), now applied to **all four**
FEMM solvers. Session order: hsolv first (own request), then belasolv +
csolv together (user: "now make the same steps for electrostatics and
current flow" + "GPU acceleration related and add the redraw function" +
"Also add the load monitor option in all of them").

## What shipped

- `hsolv/spars_cuda.h`/`.cu` (new): real-only port of `fkn/spars_cuda.h`/
  `.cu`'s `CudaPCGSolve` (no complex counterpart needed -- heat flow has
  no AC/harmonic formulation).
- `hsolv/SPARS.H`/`.CPP`: `CBigLinProb::GPUAccel` + `PCGSolveGPU()`,
  dispatched from `PCGSolve()` exactly like fkn's, adapted to hsolv's own
  `MsgBox`-based singularity-check style (no `fprintf(stderr,...)`) and
  `ChsolvDlg* TheView` (not `CFknDlg`).
  `hsolv/CMakeLists.txt`: full CUDA build wiring (nvcc custom command,
  `FEMM_CUDA_ENABLED` define, delay-loaded CUDA runtime DLLs, DLL
  install/copy) mirroring `fkn/CMakeLists.txt`, declared self-sufficiently
  (own `FEMM_CUDA_ROOT`/`FEMM_CUDA_CCBIN`/`FEMM_CUDA_ARCHS` cache vars,
  not assumed to inherit fkn's since subdirectory order isn't guaranteed).
  `ENABLE_CUDA_SOLVER` itself is declared once at the root CMakeLists.txt
  (added in an earlier session), visible to both fkn's and hsolv's
  subdirectories regardless of add_subdirectory() order (CMake cache vars
  are global once set).
- `hsolv/hsolvdoc.h`/`.cpp` (the solver's own `.feh` reader) + `MAIN.CPP`:
  `Doc.GPUAccel` parsed from `[GPUAccel]`, passed through to
  `L.GPUAccel` before `PCGSolve`. Default 0 (not gated on
  `FEMM_CUDA_ENABLED`) -- matches fkn/femmedoccore.cpp's convention: the
  solver-side default is always CPU-only; the GUI is what defaults it to
  1 on CUDA builds when creating a *new* problem.
- Classic GUI (`femm/HDRAWDOC.H`/`.CPP`): `GPUAccel` field, default
  `#ifdef FEMM_CUDA_ENABLED 1 #else 0` in `OnNewDocument` (mirrors
  `CFemmeDoc`'s identical pattern), `.feh` `[GPUAccel]` read/write.
- `femm/HDRAWLUA.CPP`: **both registration and implementation live in
  this one file** for heat flow (unlike magnetics, which splits across
  `femm/femmeLua.cpp`) -- `hi_setgpuaccel` (mirrors `mi_setgpuaccel`) and
  `hi_setredraw` (mirrors `mi_setredraw`; the underlying `NoDraw` field +
  `hdrawView.cpp` honoring it were *already* present for heat flow, just
  missing the Lua command to toggle it -- confirmed by grep before
  assuming it needed new plumbing).
- Documented both new commands in `manual/heatlua.tex` (Problem Commands
  / Editing Commands sections) and added `octavefemm/mfiles/
  hi_setgpuaccel.m` + `hi_setredraw.m` (one-function-per-file convention,
  each a thin `callfemm(...)` wrapper -- no CMakeLists/installer changes
  needed, `script.nsi` globs `octavefemm\mfiles\*.m`).
- Deliberately did **not** add a Problem Definition dialog checkbox for
  `hi_setgpuaccel` (magnetics has one, `IDC_GPUACCEL`) -- out of scope
  per explicit user direction this session ("don't bother with Qt for
  other problem types yet, just focus on the old GUI and solver
  accelerations"); the Lua command + `.feh` persistence is sufficient for
  scripted use and the regression test.
- `test/thermal_gpu_solver_test.py` (new): mirrors `gpu_solver_test.py`'s
  shape. Model is a radial heat-conduction annulus (fixed-temperature
  inner/outer boundaries via two pairs of arcs, `hi_addboundprop(name,
  0, Tset)` for Dirichlet), NOT a wire+ABC domain like magnetics --
  `hi_makeABC` exists for heat flow too but is unnecessary/inappropriate
  for a bounded conduction problem. **Gotcha caught before it could
  become a flaky test**: the disk inside the inner boundary (r <
  INNER_RADIUS) is a separate enclosed region that needs its own block
  label -- without one, `hi_analyze` fails outright with "Material
  properties have not been defined for all regions" (not a silent wrong
  answer). Fixed by adding a block label there with `hi_setblockprop("<No
  Mesh>", 0, 1, 0)` to mark it as an excluded hole, same sentinel
  mechanism as `.fem`'s `<No Mesh>` block type confirmed earlier during
  the `.femx`/`.ansx` port. Verified against the analytic steady-state
  solution T(r) = T1 + (T0-T1)*ln(r/r1)/ln(r2/r1): test measured
  T(20mm)=26.906, analytic=26.83 -- close enough to confirm the model
  and solve are physically correct, not just internally self-consistent.

## Verification

Initially built/tested on this machine's plain (non-CUDA) build only.
**Updated 2026-07-21, same day**: also built with
`-DENABLE_CUDA_SOLVER=ON` (`-DFEMM_CUDA_ROOT="C:\Program Files\NVIDIA GPU
Computing Toolkit\CUDA\v12.6"`) on this machine's real CUDA 12.6 + RTX
GPU -- all three of hsolv/belasolv/csolv's `spars_cuda.cu` files compiled
via nvcc and linked cleanly, matching what the `win-cuda` GitHub Actions
job does (see the CI section below). Re-registered COM at
`bin\cuda\femmx.exe` (via `scripts\register_femm_com.ps1
-FemmExePath bin\cuda\femmx.exe`) and reran all three tests for real
numbers -- correctness still exact (0.0000% diff) for all three.
**Speedup at this problem size (~35K nodes): hsolv 1.02x, belasolv
1.00x, csolv 0.98x -- essentially none.** This matches
[[gpu_speedup_investigation]]'s own "Conflicting DC/real-solver speedup
measurement" finding for fkn's real-valued solver at similar sizes --
not a new regression, a consistent pattern across every real-valued
(non-AC) GPU path in this codebase so far. Left as an honest, documented
result (`test/results/*/[...]_gpu_solver.txt`, committed) rather than
tuned to force a pass -- `currentflow_gpu_solver_test.py`'s
`test_gpu_is_faster_when_available` assertion actually FAILS at this
problem size on real hardware (0.98x), though CI never hits this since
its `win-cuda` job deselects that assertion entirely (no GPU on CI
runners). **Before assuming any of these three solvers benefit from GPU
acceleration at typical problem sizes, don't just trust this note --
rerun for real; a larger problem (see fkn's own 700K-node 3.49x result)
might show genuine speedup where this ~35K-node test doesn't.**
Restored COM back to `bin\plain\femmx.exe` afterward and deleted the
temporary top-level `bin\cudart64_12.dll` copy (see
[[gpu_speedup_investigation]]'s "hides the CUDA DLLs from
gpu_solver_test.py's own detection heuristic" gotcha for why that copy
was needed at all) -- don't leave either change lying around for a
future session to trip over.

**Update, same day, user asked for a 10x-node comparison**: reran both
hsolv (real-valued) and csolv (complex) at ~10x the node count (mesh
size scaled by 1/sqrt(10), ~0.19mm instead of 0.6mm -> ~343K nodes each,
via ad-hoc scratch scripts, not committed tests -- mirrored the real
test models exactly). **Still no speedup at 10x either: hsolv 1.03x
(65.1s CPU vs 63.4s GPU), csolv 1.00x (80.0s vs 80.3s)** -- essentially
identical to the ~35K-node result, not a "just needs a bigger problem"
issue. This is now a **robust, reproduced-twice-at-two-sizes** finding,
not noise -- worth taking seriously before ever claiming GPU
acceleration helps for these three solvers on annulus-shaped problems on
this hardware (RTX 4060 Laptop). Contrast with fkn's own DC path, which
in one measurement DID show growing speedup with size (1.32x@70K ->
3.49x@700K) -- so "bigger problem = more speedup" is true for *that*
solver/problem-shape combination but evidently not guaranteed in
general; something about hsolv/belasolv/csolv's specific problem
structure, matrix bandwidth (thin annulus + Cuthill-McKee renumbering),
or subprocess/mesh-generation overhead swamping the actual solve time is
suppressing the GPU win here. **Not root-caused** (out of scope for a
quick benchmark ask) -- if this matters later, profile where the wall-
clock time actually goes (mesh generation vs. matrix assembly vs. PCG
iterations themselves, same technique as the original "CPU profiling
that motivated the AC/harmonic extension" section in
[[gpu_speedup_investigation]]) before assuming the GPU kernel itself is
at fault.

## CI verification (2026-07-21, prompted by "is the manual build working in CI too" / "do you need to update anything for CI")

Found and fixed a real gap: `.github/workflows/ccpp.yml`'s `win-cuda`
job hardcoded its pytest file list (only `gpu_solver_test.py`
`ac_gpu_solver_test.py`) rather than running the whole `test/` directory
like the plain `win-vcpkg` job does -- so it was already compiling
hsolv/belasolv/csolv with CUDA (shared `ENABLE_CUDA_SOLVER` option) but
never actually running their new tests. Fixed by adding the three new
test files to that line (commit `72f4b5f`).

Also **directly verified, not just read the config for**, two other
CI-relevant things this session, both confirmed working:
- **The manual PDF build**: CI's `manual/build_manual.bat` uses plain
  `latex.exe` -> `dvips.exe` -> `ps2pdf.exe` (NOT `xelatex`, despite
  `manual.tex`'s own misleading `!TEX program = XeLaTeX` magic comment
  at the top -- that comment is contradicted by the document's own
  `\usepackage[dvips]{graphicx}`/`[dvips]{hyperref}` options, and is
  just a stale/wrong editor hint, not what any actual build path uses).
  Ran that exact pipeline locally (this machine's MiKTeX is installed
  but not on PATH -- same class of issue as
  [[build_and_com_registration_gotchas]]'s choco-latex finding; used
  `C:\Users\spgry\AppData\Local\Programs\MiKTeX\miktex\bin\x64\` directly)
  and it succeeded end-to-end, producing a clean 164-page PDF with the
  new `hi_`/`ei_`/`ci_` `setgpuaccel`/`setredraw` content rendering
  correctly.
- **The CUDA build itself** (see above) -- confirms `win-cuda`'s
  `-DENABLE_CUDA_SOLVER=ON` build will succeed for all four solvers, not
  just fkn.

Also checked and confirmed no other CI changes needed: `test/
requirements.txt` already covers everything the 3 new test files import
(just `pytest`+`pyfemm`, nothing new); all 5 test files referenced in
the `win-cuda` pytest line actually exist; no other hardcoded
file/solver lists exist elsewhere in `ccpp.yml`.

## belasolv (electrostatics) -- same shape as hsolv

Structurally identical port: `belasolv/spars.h`/`.cpp` already had the
exact same `CBigLinProb` (real-valued, SSOR CPU / Jacobi GPU PCG) as
hsolv's, byte-for-byte same `PCGSolve` including the `MsgBox("singular
flag tripped...")` style and `Lambda=1.5` placement -- confirmed by
direct comparison before writing anything, not assumed. `ei_setgpuaccel`/
`ei_setredraw` added to `femm/beladrawLua.cpp` (doc pointer is
`pBeladrawDoc`, view class `CbeladrawView`). File extension `.fee`.
`test/electrostatic_gpu_solver_test.py` reuses the exact same annulus
model as the thermal test (same Laplace equation, same analytic profile)
-- passed first try, T(20mm)=26.906 again (same geometry -> same answer).
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

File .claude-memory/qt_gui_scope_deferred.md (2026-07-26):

---
name: qt-gui-scope-deferred
description: "User wants new physics-type work (heat/electrostatics/current-flow) done in the classic MFC GUI + solvers first, not the Qt GUI, which stays magnetics-only for now"
metadata: 
  node_type: memory
  type: feedback
  originSessionId: 846a52dc-e5cc-4b0f-9a4f-7b5debeae297
  modified: 2026-07-21T11:17:34.978Z
---

When adding a feature for a non-magnetics physics type (heat flow,
electrostatics, current flow), implement it in the classic MFC GUI
(`femm/`) and the relevant solver, not [[femmqt_qt_gui]] (which per its
own plan is deliberately magnetics-only, Phase 1 MVP).

**Why:** stated directly, 2026-07-21: "Do not bother with the qt
application for the other problem types yet, just focus on the old gui
and the solver accelerations." This came mid-turn while I was mid-
investigation for the hsolv (heat-flow) CUDA port -- confirms the
existing plan's magnetics-only Qt scope is intentional and current, not
just an unfinished backlog item to pick up opportunistically.

**How to apply:** default new non-magnetics feature work to classic
GUI + solver only. Only extend femmqt to a new physics type if the user
explicitly asks for it.

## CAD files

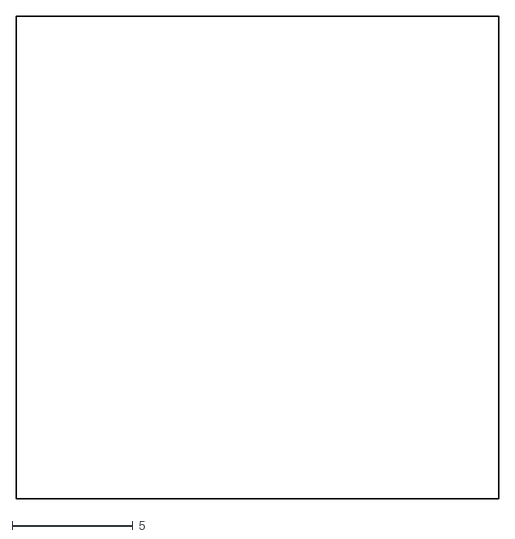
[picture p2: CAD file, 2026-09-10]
test/fixtures/dxf/square.dxf
20.0 x 20.0

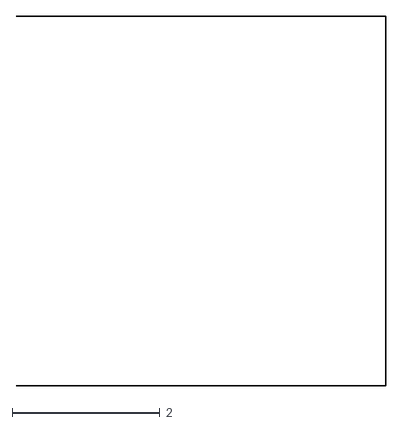
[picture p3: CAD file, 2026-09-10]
test/fixtures/dxf/layers.dxf
5.00 x 5.00

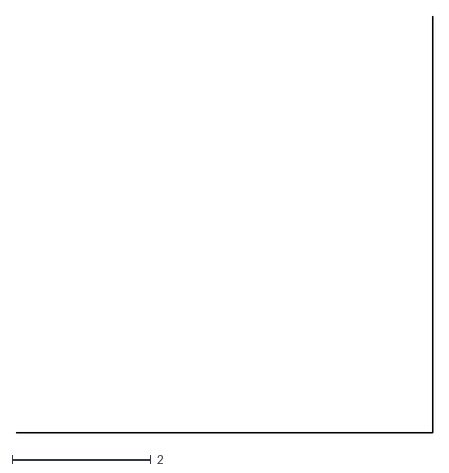
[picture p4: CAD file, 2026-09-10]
test/fixtures/dxf/polyline.dxf
6.00 x 6.00

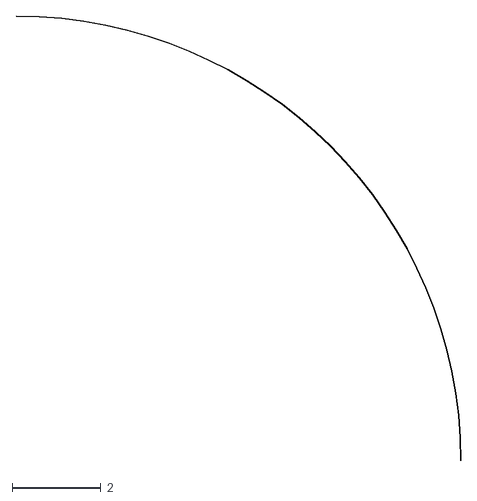
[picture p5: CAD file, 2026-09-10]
test/fixtures/dxf/arc.dxf
10.0 x 10.0

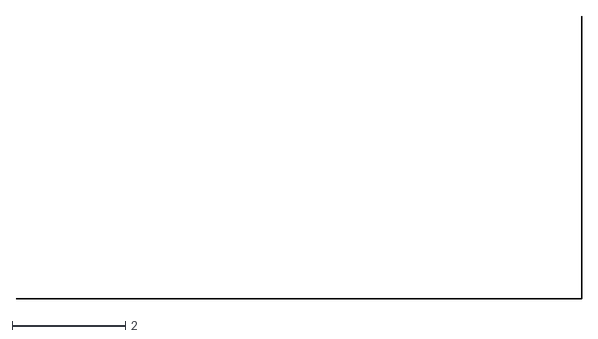
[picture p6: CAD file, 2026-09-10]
test/fixtures/dxf/line.dxf
10.0 x 5.00

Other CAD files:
test/fixtures/dxf/circle.dxf
test/fixtures/dxf/garbage.dxf
test/fixtures/dxf/truncated.dxf
test/fixtures/dxf/lwpolyline.dxf
test/fixtures/dxf/inches.dxf

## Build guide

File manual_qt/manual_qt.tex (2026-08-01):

% !TEX program = pdflatex
% !TEX spellcheck = en_US
%
% FEMMX Qt GUI (femmqt) User's Manual.
% Companion to manual/manual.tex (the classic MFC GUI manual) -- this
% document covers only the new Qt6-based GUI (femmqt.exe), which as of
% this writing supports Magnetics and Heat Flow problems sharing one
% geometry editor, one Materials library, and the same property-list
% workflow. Built with a plain pdflatex pipeline (native PNG support,
% no dvips/Ghostscript step) -- see build_manual.bat.
\documentclass[11pt]{report}

\usepackage[letterpaper,margin=1in]{geometry}
\usepackage{graphicx}
\usepackage{float}
\usepackage{enumitem}
\usepackage{xcolor}
\usepackage{hyperref}
\usepackage{parskip}

\graphicspath{{images/}}

\hypersetup{
  colorlinks=true,
  linkcolor=blue!50!black,
  urlcolor=blue!50!black,
  citecolor=blue!50!black,
  pdftitle={FEMMX Qt GUI User's Manual},
  pdfauthor={FEMMX Project}
}

% Every figure in this manual is small and directly tied to the
% paragraph that introduces it, so pin them with [H] rather than
% letting LaTeX's float algorithm drift them onto later pages.
\newcommand{\dlgfig}[2]{%
  \begin{figure}[H]
    \centering
    
    \caption{#2}
  \end{figure}
}
\newcommand{\winfig}[2]{%
  \begin{figure}[H]
    \centering
    
    \caption{#2}
  \end{figure}
}

\title{\LARGE FEMMX Qt GUI\\[8pt]\Large A Modern Interface for Magnetics and Heat Flow\\[8pt]\large User's Manual}
\author{}
\date{\today}

\begin{document}

\begin{titlepage}
\centering
\vspace*{2in}
{\LARGE FEMMX Qt GUI (femmqt)\par}
\vspace{16pt}
{\Large A Modern Interface for Magnetics and Heat Flow Analysis\par}
\vspace{24pt}
{\large Version 2.1.0\par}
\vspace{8pt}
{\large User's Manual\par}
\vspace{16pt}
\today
\vspace{48pt}

\begin{minipage}{0.8\textwidth}
\centering
\small
This manual documents \texttt{femmqt.exe}, the Qt6-based graphical
interface that ships alongside FEMMX's original interface (the
``Classic GUI''). It is a companion to, not a replacement for, the main
FEMMX manual -- the underlying solvers, file formats, and Lua scripting
interface are unchanged and are documented there. This manual covers
only the Qt GUI's own windows, menus, and dialogs, and walks through
two complete worked examples: a magnetics problem, and adding a
heat-flow analysis to that same geometry.
\end{minipage}

\vfill
FEMMX project \\
\href{https://github.com/SpgV0/femmx}{\tt github.com/SpgV0/femmx}
\end{titlepage}

\tableofcontents

\chapter{Introduction}

FEMMX's Qt GUI (\texttt{femmqt.exe}) is a second, modern interface for
building and solving finite-element problems, built with Qt6 instead of
the original MFC toolkit. It is designed to feel closer to a modern CAD
program -- mouse-wheel zoom, click-and-drag selection, a real Undo, and
a resizable window -- while reading and writing the exact same file
formats the Classic GUI and command-line solvers already use.

\section{Magnetics and Heat Flow, one workflow}

The Qt GUI currently supports two physics types:

\begin{itemize}
  \item \textbf{Magnetics} (\texttt{.fem} problem files, \texttt{.ans}
    solutions) -- the same planar/axisymmetric magnetics analysis as
    the rest of FEMMX.
  \item \textbf{Heat Flow} (\texttt{.feh} problem files, \texttt{.anh}
    solutions) -- steady-state thermal conduction analysis.
\end{itemize}

The key idea behind the Qt GUI is that these two physics types
\emph{share one geometry editor and one Materials library}. You draw
your nodes, segments, arcs, and block labels once. Every material in
your problem carries \emph{both} its magnetic properties (permeability,
conductivity, BH curve, \ldots) \emph{and} its heat-flow properties
(thermal conductivity, heat capacity, volumetric heat generation) in a
single, unified Material Property dialog -- if a material has no data
for one side, that side is simply left at zero, rather than being
hidden or forced to some faked default. This means a typical workflow
is: finish drawing and solving your magnetics problem, then -- reusing
the exact same geometry -- open the Heat Flow boundary/point property
lists, assign a thermal boundary condition to the same segments, save
the result as a sibling \texttt{.feh} file, and solve for temperature
without redrawing anything. The second worked example in this manual
(Chapter~\ref{ch:example-heatflow}) does exactly this.

Boundary conditions and point properties are \emph{not} unified the
same way materials are, because the two physics types' boundary
concepts are genuinely different (a magnetics ``Mixed'' boundary and a
heat-flow ``Convection'' boundary need different input fields). Instead,
each physics type gets its own boundary/point property list, but both
lists use the exact same Add/Duplicate/Edit/Delete workflow, so once you
know one you know the other.

\section{Everything you do here is optional -- the Classic GUI still works}

Nothing in the Qt GUI modifies how the Classic GUI or the command-line
solvers (\texttt{fkn.exe}, \texttt{hsolv.exe}, \ldots) behave, and files
are fully interchangeable in both directions: a \texttt{.fem}/\texttt{.feh}
file saved from the Qt GUI opens correctly in the Classic GUI, and vice
versa. A ``Switch to Classic GUI'' menu item is available from the File
menu of both the main editor and the Solution Viewer if you want to move
a file over to the older interface.

\chapter{The Main Window}

\begin{figure}[H]
  \centering
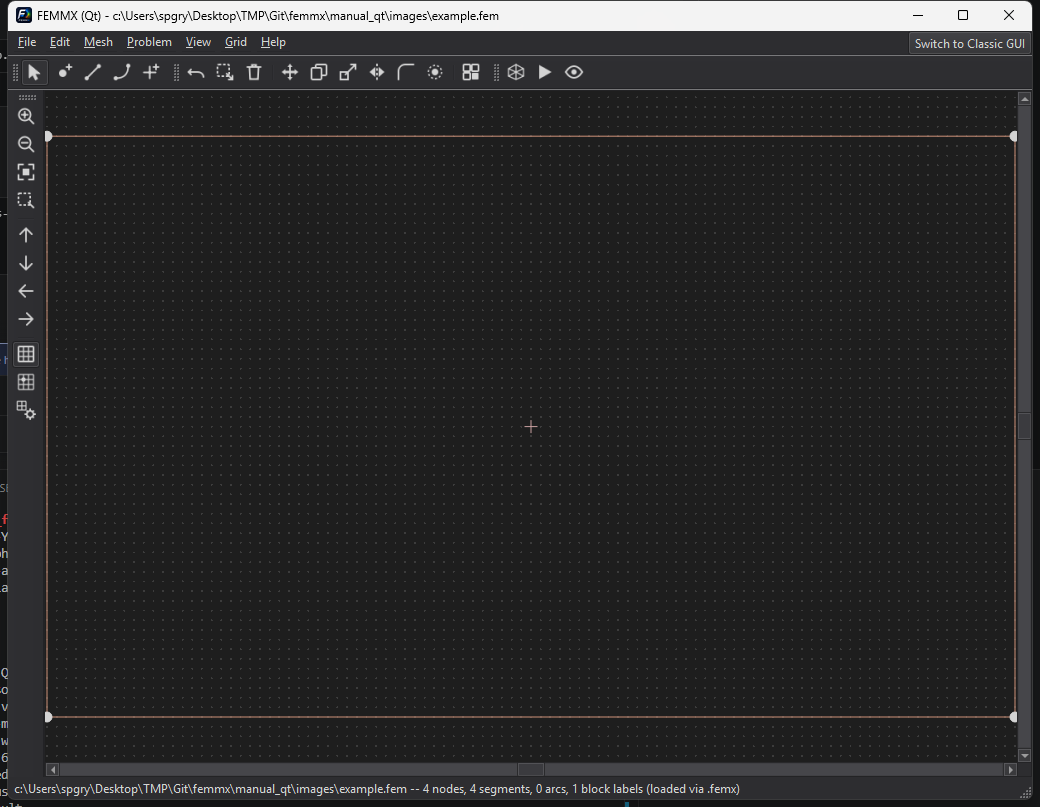
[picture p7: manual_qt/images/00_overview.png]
  
  \caption{The main window: an empty problem, showing the drawing
    toolbar (left), zoom/pan/grid tool buttons (far left), and the
    six main menus.}
\end{figure}

The main window is where you build problem geometry, assign materials
and boundary conditions, and launch a solve. The left-hand toolbar
provides drawing/editing tools (Select, Add Node, Add Segment, Add Arc,
Add Block Label, Undo, Open Selected, Delete, Move, Copy, Scale,
Mirror, Create Radius, Create Open Boundary, and Select by Group),
mirroring the Edit menu described below in the same order; the
play-arrow icon solves the problem and the eye icon opens the Solution
Viewer. A narrower strip of buttons on the far left controls zoom,
pan, and the grid. Hovering over any toolbar button shows its name in
a tooltip.

\section{File menu}
\winfig{menu_file.png}{The File menu.}

\begin{description}[leftmargin=2cm,style=nextline]
  \item[New / Open\ldots / Save / Save As\ldots] Standard file
    operations for the \textbf{magnetics} (\texttt{.fem}) problem.
  \item[Open Heat Flow\ldots / Save Heat Flow / Save Heat Flow As\ldots]
    The same operations for the \textbf{heat-flow} (\texttt{.feh})
    problem sharing this window's geometry. See
    Section~\ref{sec:dual-save} for how the two save paths interact.
  \item[Import DXF\ldots / Export DXF\ldots] Import or export the
    geometry (nodes, segments, arcs) as a DXF file.
  \item[Print Preview\ldots / Print\ldots / Print Setup\ldots] Print the
    geometry view.
  \item[Recent Files] A shared list of recently opened files, for
    either physics type.
  \item[Switch to Classic GUI\ldots] Saves the current file(s) if
    needed, launches \texttt{femmx.exe} (the Classic GUI) with the same
    file open, and closes this window.
\end{description}

\subsection{Saving both a magnetics and a heat-flow file together}
\label{sec:dual-save}

The main window tracks two independent file paths: the currently open
\texttt{.fem} path and the currently open \texttt{.feh} path, since both
can refer to the same underlying geometry. Once \emph{both} paths have
been established (i.e.\ you have saved or opened both a \texttt{.fem}
and a \texttt{.feh} for this geometry), saving one opportunistically
re-saves the other too, so they never drift out of sync with each
other's copy of the shared geometry. When you use ``Save Heat Flow
As\ldots'' for the first time on a geometry that already has a saved
\texttt{.fem}, the Save dialog conveniently defaults the suggested file
name to the \texttt{.fem}'s own base name with a \texttt{.feh}
extension (Figure~\ref{fig:save-heatflow-dialog}) -- the concrete
realization of ``finish the magnetics problem, then easily add heat
flow to it.''

\begin{figure}[H]
  \centering
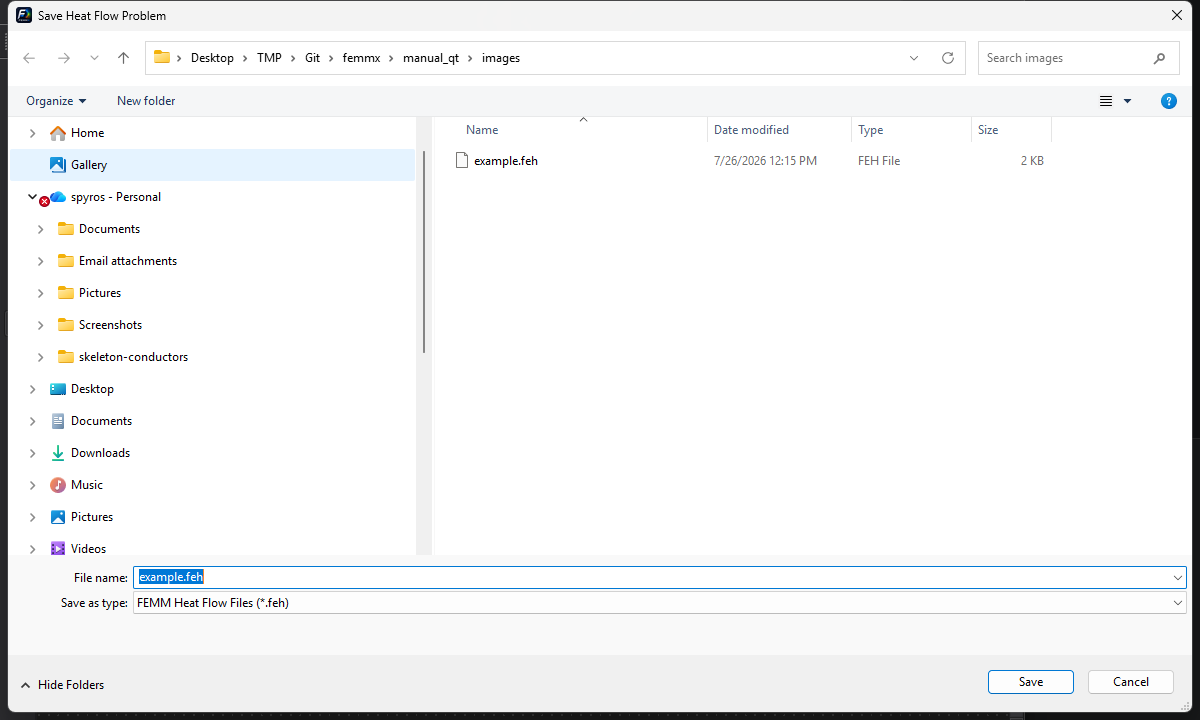
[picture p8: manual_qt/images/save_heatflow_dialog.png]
  
  \caption{``Save Heat Flow As\ldots'' defaults to \texttt{example.feh}
    because \texttt{example.fem} was already saved in this folder.}
  \label{fig:save-heatflow-dialog}
\end{figure}

\section{Edit menu}
\winfig{menu_edit.png}{The Edit menu.}

\begin{description}[leftmargin=2cm,style=nextline]
  \item[Undo] Reverts the last destructive operation (a single-level
    undo, matching the Classic GUI's own behavior).
  \item[Open Selected] Opens the properties dialog for whatever is
    currently selected (equivalent to double-clicking it).
  \item[Delete] Deletes the current selection.
  \item[Move\ldots / Copy\ldots / Scale\ldots / Mirror\ldots] Geometric
    transforms applied to the current selection.
  \item[Create Radius\ldots] Fillets a corner between two selected
    segments/arcs into a smooth radius.
  \item[Create Open Boundary\ldots] Adds an asymptotic outer-boundary
    layer (the Kelvin-transform ``ABC'' technique) around the selected
    region, for problems that extend to infinity.
  \item[Copy as Bitmap] Copies the current geometry view to the
    clipboard as an image.
  \item[Select by Group\ldots / Set Group\ldots] Selects, or assigns,
    entities by their numeric group ID.
  \item[Preferences\ldots] Opens the application Preferences dialog
    (Section~\ref{sec:preferences}).
\end{description}

\section{Mesh menu}
\label{sec:mesh-menu}
\winfig{menu_mesh.png}{The Mesh menu.}

\begin{description}[leftmargin=2.5cm,style=nextline]
  \item[Create Mesh / Show Mesh / Purge Mesh] Generate, toggle the
    display of, and delete the triangular mesh, without running a
    solve.
  \item[Solve] Meshes (if needed) and solves the \textbf{magnetics}
    problem, then opens the Solution Viewer on the resulting
    \texttt{.ans}.
  \item[View Results\ldots] Opens an existing \texttt{.ans} file in the
    Solution Viewer.
  \item[Solve (Heat Flow)] The same, for the \textbf{heat-flow} problem
    sharing this geometry -- meshes and solves the \texttt{.feh},
    producing a \texttt{.anh}.
  \item[View Results (Heat Flow)\ldots] Opens an existing \texttt{.anh}
    file in the Solution Viewer.
\end{description}

Both Solve commands require the corresponding problem file
(\texttt{.fem} or \texttt{.feh}) to already be saved to disk, since the
mesher and solver are external executables (\texttt{triangle.exe}, then
\texttt{fkn.exe} or \texttt{hsolv.exe}) invoked against that file --
exactly as the Classic GUI does.

\section{Problem menu}
\label{sec:problem-menu}
\winfig{menu_problem.png}{The Problem menu. Note the single, unified
  \emph{Materials\ldots} entry near the top -- materials are shared
  between physics types, so there is no separate ``Heat Flow
  Materials'' item. Boundary Properties and Point Properties, by
  contrast, are physics-specific, so each gets its own entry.}

\begin{description}[leftmargin=3cm,style=nextline]
  \item[Problem Properties\ldots] Top-level problem settings shared by
    both physics types (Section~\ref{sec:problem-properties}).
  \item[Exterior Region\ldots] Defines an axisymmetric exterior region
    for the Kelvin-transform technique (Section~\ref{sec:exterior-region}).
  \item[Materials\ldots] The unified Materials list -- every material
    in the problem, with both magnetic and heat-flow properties
    (Section~\ref{sec:materials}).
  \item[Materials Library\ldots] Browse FEMMX's bundled material
    library and add entries to the current problem's Materials list
    (Section~\ref{sec:materials-library}).
  \item[Boundary Properties\ldots] The magnetics boundary-condition
    list (Section~\ref{sec:boundary-props}).
  \item[Circuits\ldots] The magnetics circuit list
    (Section~\ref{sec:circuits}).
  \item[Point Properties\ldots] The magnetics point-property list
    (Section~\ref{sec:point-props}).
  \item[Heat Flow Boundary Properties\ldots] The heat-flow
    boundary-condition list (Section~\ref{sec:heat-boundary-props}).
  \item[Heat Flow Point Properties\ldots] The heat-flow point-property
    list (Section~\ref{sec:heat-point-props}).
\end{description}

\section{View menu}
\winfig{menu_view.png}{The View menu.}

\begin{description}[leftmargin=2.5cm,style=nextline]
  \item[Zoom In / Zoom Out / Natural / Window] Zoom controls (the
    mouse wheel also zooms). \emph{Natural} fits the whole geometry in
    the view; \emph{Window} lets you drag a rectangle to zoom into.
  \item[Scroll Left/Right/Up/Down] Pans the view.
  \item[Show Block Names] Labels each block label with its material
    name directly on the canvas.
  \item[Show Orphans] Highlights any node not connected to a segment or
    arc, to help spot accidentally disconnected geometry.
  \item[Status Bar] Toggles the bottom status bar.
  \item[Dark Theme] Switches the whole application between light and
    dark palettes; the toolbar icons recolor to match automatically.
  \item[Load Monitor] Opens the CPU/GPU/RAM Load Monitor
    (Section~\ref{sec:load-monitor}).
\end{description}

\section{Grid menu}
\winfig{menu_grid.png}{The Grid menu.}

\begin{description}[leftmargin=2.5cm,style=nextline]
  \item[Show Grid] Toggles the dotted background grid.
  \item[Snap to Grid] When enabled, new points and dragged nodes snap
    to the nearest grid intersection.
  \item[Set Grid\ldots] Sets the grid spacing.
\end{description}

\section{Help menu}
\winfig{menu_help.png}{The Help menu.}

\begin{description}[leftmargin=2.5cm,style=nextline]
  \item[Help Topics] Opens the FEMMX manual (this document, or the main
    Classic-GUI manual, depending on what is installed).
  \item[License] Shows the license text.
  \item[About FEMMX\ldots] Shows the version number and credits.
\end{description}

\chapter{Drawing and Editing Geometry}

Geometry is built from four entity types, each with its own toolbar
button and its own Properties dialog (opened by double-clicking the
entity in Select mode, or via Edit~$\to$~Open Selected):

\section{Nodes}
Click the Add Node tool, then click anywhere on the canvas to place a
node. Double-clicking an existing node opens its Properties dialog:

\dlgfig{dlg_node_props.png}{Node Properties.}

\begin{description}[leftmargin=2.5cm,style=nextline]
  \item[X / Y] The node's coordinates; editable directly here as an
    alternative to dragging.
  \item[Point Property] Which magnetics point property (if any) is
    applied at this node (Section~\ref{sec:point-props}).
  \item[Point Property (Heat Flow)] Which heat-flow point property (if
    any) is applied at this node (Section~\ref{sec:heat-point-props}) --
    independent of the magnetics assignment above it.
  \item[In Group] The node's numeric group ID, used by Select by
    Group.
\end{description}

\section{Segments}
The Add Segment tool draws a straight line between two nodes (clicking
an empty point first places a node there). Double-clicking a segment
opens:

\dlgfig{dlg_segment_props.png}{Segment Properties.}

\begin{description}[leftmargin=2.5cm,style=nextline]
  \item[Boundary] The magnetics boundary condition applied along this
    segment (Section~\ref{sec:boundary-props}).
  \item[Boundary (Heat Flow)] The heat-flow boundary condition applied
    along this segment (Section~\ref{sec:heat-boundary-props}) --
    independent of the magnetics assignment.
  \item[Let Triangle choose mesh size / Max Segment Size] Controls how
    finely this segment is discretized by the mesher.
  \item[Hide this segment in postprocessor] Excludes the segment from
    the Solution Viewer's rendering (useful for internal construction
    lines).
  \item[In Group] The segment's numeric group ID.
\end{description}

\section{Arcs}
The Add Arc tool works like Add Segment, but after picking the two
endpoints it prompts for the arc's included angle:

\dlgfig{dlg_add_arc_prompt.png}{The Add Arc angle prompt.}

Once placed, an arc's Properties dialog offers the same fields as a
Segment's (Boundary, Boundary (Heat Flow), meshing controls, group),
plus the arc angle and maximum segment size used to discretize the
curve.

\section{Block Labels}
The Add Block Label tool drops a marker inside a closed region to
identify what material fills it (and, for magnetics, whether it
belongs to a circuit). Double-clicking a block label opens:

\dlgfig{dlg_blocklabel_props.png}{Block Label Properties.}

\begin{description}[leftmargin=2.7cm,style=nextline]
  \item[Block Type] Which material fills this region
    (Section~\ref{sec:materials}) -- this single field is used by
    \emph{both} a magnetics solve and a heat-flow solve of the same
    geometry, since materials are unified.
  \item[In Circuit] Which magnetics circuit (if any) this region
    belongs to (Section~\ref{sec:circuits}).
  \item[Let Triangle choose mesh size / Mesh Size] Controls the local
    mesh density inside this region.
  \item[Magnetization Direction (deg) / Mag.\ Direction Function
    (Lua, optional)] For permanent-magnet materials: a fixed
    magnetization angle, or an optional Lua expression for a spatially
    varying one.
  \item[Number of Turns] For regions inside a circuit, how many times
    the circuit's current effectively passes through this block
    (positive or negative, for winding direction).
  \item[In Group] The block label's numeric group ID.
  \item[Is an external region label (axisymmetric)] Marks this label as
    the exterior (Kelvin-transformed) region for an axisymmetric open
    boundary problem.
  \item[Is the default block label] Marks this as the material used to
    fill any point not enclosed by a labeled region.
\end{description}

\chapter{Materials, Boundaries, Circuits, and Point Properties}

These four property types are each edited through the same list-based
workflow: Problem menu $\to$ (property type), giving an
Add~New/Duplicate/Edit/Delete list, then a per-type field editor.
Once defined, a property is assigned to geometry from that entity's own
Properties dialog (Chapter~2).

\section{Materials}
\label{sec:materials}

Problem $\to$ Materials\ldots opens the list of every material defined
in the current problem:

\dlgfig{dlg_materials_list.png}{The Materials list.}

Choosing Add New or Edit\ldots opens the Material Property dialog --
and this is where the ``one shared library'' design is most visible:
every material carries \emph{both} its magnetics fields \emph{and} its
heat-flow fields in the same dialog, under a \textbf{Heat Flow}
section:

\begin{figure}[H]
  \centering
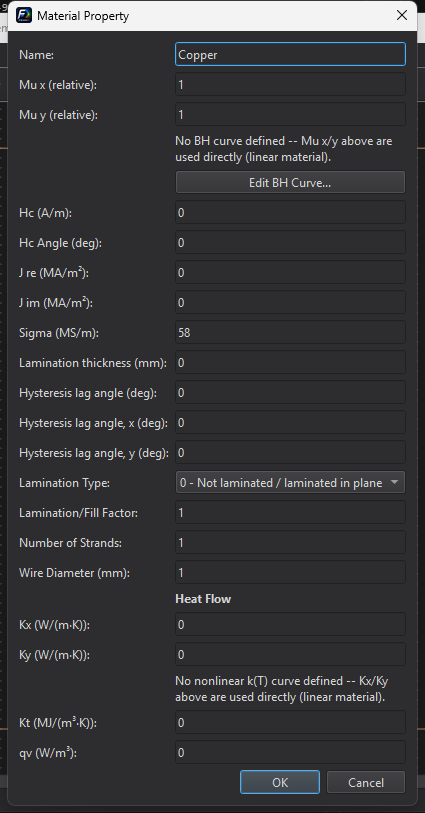
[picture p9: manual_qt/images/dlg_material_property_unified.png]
  
  \caption{Material Property: a purely-magnetic material (like
    ``Copper'' fresh from the library) leaves its Heat Flow fields at
    zero.}
\end{figure}

\begin{figure}[H]
  \centering
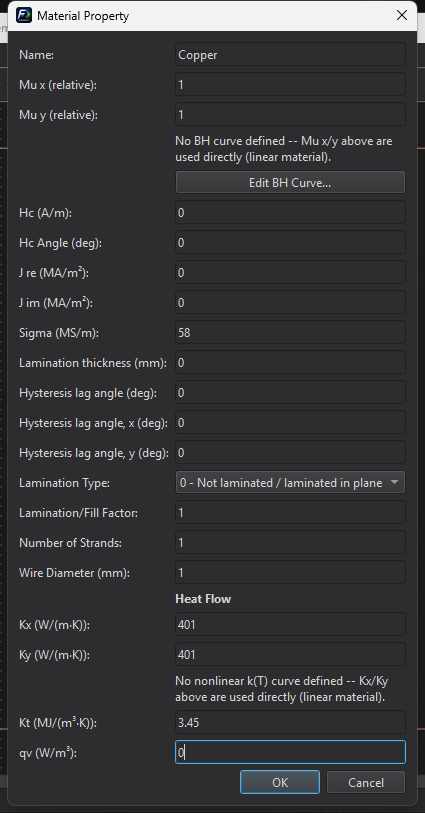
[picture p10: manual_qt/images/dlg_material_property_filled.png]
  
  \caption{The same material after filling in its thermal
    conductivity ($K_x$, $K_y$) and volumetric heat capacity ($K_t$).}
\end{figure}

\begin{description}[leftmargin=2cm,style=nextline]
  \item[Mu x / Mu y (relative)] Relative permeability, or use \emph{Edit
    BH Curve\ldots} for a nonlinear material.
  \item[Hc, Hc Angle] Coercivity, for permanent magnets.
  \item[J re / J im] Applied source current density (for solid
    conductors driven directly, rather than through a circuit).
  \item[Sigma] Electrical conductivity.
  \item[Lamination thickness, Hysteresis lag angles, Lamination Type,
    Lamination/Fill Factor, Number of Strands, Wire Diameter] Fields
    controlling laminated-core and stranded-wire loss/eddy-current
    modeling -- identical in meaning to the Classic GUI's Block
    Property dialog.
  \item[Kx, Ky (W/(m$\cdot$K))] Thermal conductivity in the x and y
    directions. Leave at 0 if this material is never used in a
    heat-flow problem.
  \item[Kt (MJ/(m$^3\cdot$K))] Volumetric heat capacity (only relevant
    for transient heat-flow analyses).
  \item[qv (W/m$^3$)] Volumetric heat generation -- use this to model
    resistive/ohmic heating, chemical reaction heat, etc. See
    Chapter~\ref{ch:example-heatflow} for a worked example that sets
    this field.
\end{description}

If \emph{no} thermal data is available for a material, simply leave
its Heat Flow fields at zero -- this is a deliberate design choice
(rather than substituting some made-up default conductivity), so it is
always obvious from the dialog whether a material actually has
thermal data behind it.

\subsection{Materials Library}
\label{sec:materials-library}

Problem $\to$ Materials Library\ldots browses FEMMX's bundled
\texttt{matlib.dat}/\texttt{heatlib.dat} material database and lets you
add an entry straight into the current problem's Materials list:

\dlgfig{dlg_materials_library.png}{The Materials Library, collapsed to
  its top-level folders.}

\dlgfig{dlg_materials_library_expanded.png}{Expanding ``Solid
  Non-Magnetic Conductors'' reveals its materials.}

The library is built by merging two source files: \texttt{matlib.dat}
(magnetics properties, organized by the folders shown above) and
\texttt{heatlib.dat} (heat-flow properties for a different, and only
partially overlapping, set of material names). Where a name matches
between the two files (case-insensitively), the resulting entry carries
both sets of properties already filled in. Any \texttt{heatlib.dat}
entry that has no matching magnetics material is still made available,
grouped under a final \textbf{Heat Flow Materials (no magnetics
match)} folder, so no thermal data from the bundled library is ever
silently dropped.

\section{Boundary Properties}
\label{sec:boundary-props}

Problem $\to$ Boundary Properties\ldots manages magnetics boundary
conditions, assigned to segments/arcs from their own Properties dialog:

\dlgfig{dlg_boundary_list.png}{The Boundary Properties list.}
\dlgfig{dlg_boundary_edit.png}{Editing a Fixed-A boundary.}

The \textbf{Type} dropdown selects the boundary condition form (Fixed
A, Small Skin Depth, Mixed, Strategic Dual Image, Periodic,
Antiperiodic); the fields below it change to match whichever type is
selected.

\section{Circuits}
\label{sec:circuits}

Problem $\to$ Circuits\ldots manages named circuits, which a Block
Label can join via its \emph{In Circuit} field (with a turns count):

\dlgfig{dlg_circuits_list.png}{The Circuits list.}
\dlgfig{dlg_circuit_edit.png}{Editing a circuit.}

\begin{description}[leftmargin=2.5cm,style=nextline]
  \item[Total Amps re / im] The total current driven through the
    circuit (real and imaginary parts, for AC problems).
  \item[Circuit Type] \emph{Series} (every block sees the same total
    current, split by turns) or \emph{Parallel} (current divides
    inversely with each block's impedance).
\end{description}

\section{Point Properties}
\label{sec:point-props}

Problem $\to$ Point Properties\ldots manages magnetics point
properties, assigned to nodes from the Node Properties dialog:

\dlgfig{dlg_pointprops_list.png}{The Point Properties list.}
\dlgfig{dlg_pointprop_edit.png}{Editing a point property.}

\begin{description}[leftmargin=2cm,style=nextline]
  \item[I re / I im] A point current source at this node.
  \item[A re / A im] A fixed value of the vector potential at this
    node.
\end{description}

\chapter{Heat Flow Properties}

Heat-flow boundary conditions and point properties are edited the same
way as their magnetics counterparts (Chapter~3), just from their own
Problem-menu entries -- there is deliberately no separate ``Heat Flow
Materials''; that list is shared (Section~\ref{sec:materials}).

\section{Heat Flow Boundary Properties}
\label{sec:heat-boundary-props}

\dlgfig{dlg_heat_boundary_list_empty.png}{The Heat Flow Boundary
  Properties list, before anything has been added.}

Choosing Add New opens the editor with sensible defaults for a new,
unnamed boundary:

\dlgfig{dlg_heat_boundary_edit_default.png}{A freshly added heat-flow
  boundary, defaulting to Fixed Temperature.}

\begin{description}[leftmargin=2cm,style=nextline]
  \item[BC Type] \emph{Fixed Temperature}, \emph{Heat Flux}, or
    \emph{Convection} (mixed convective/radiative).
  \item[Tset (K)] The fixed temperature, for a Fixed Temperature
    boundary.
  \item[qs (W/m\textsuperscript{2})] The prescribed heat flux, for a
    Heat Flux boundary.
  \item[h (W/(m\textsuperscript{2}K)) / Tinf (K)] The convective heat
    transfer coefficient and ambient temperature, for a Convection
    boundary.
  \item[beta / TinfRad (K)] Radiative emissivity coefficient and
    ambient radiative temperature, also for a Convection boundary.
\end{description}

Filling these in for a convective boundary to ambient air looks like
this:

\dlgfig{dlg_heat_boundary_edit_filled.png}{An ``Ambient Air'' convective
  boundary: $h=25\,\mathrm{W/(m^2K)}$, $T_\infty=293\,\mathrm{K}$.}

\dlgfig{dlg_heat_boundary_list.png}{The list after adding it.}

\section{Heat Flow Point Properties}
\label{sec:heat-point-props}

\dlgfig{dlg_heat_point_list_empty.png}{The Heat Flow Point Properties
  list, before anything has been added.}
\dlgfig{dlg_heat_point_edit.png}{Editing a heat-flow point property.}

\begin{description}[leftmargin=2cm,style=nextline]
  \item[Tp (K)] A fixed point temperature at the node this property is
    assigned to.
  \item[qp (W)] A point heat source at that node.
\end{description}

\chapter{Problem-Level Settings}

\section{Problem Properties}
\label{sec:problem-properties}

Problem $\to$ Problem Properties\ldots edits settings that apply to
the whole geometry, regardless of which physics type you solve for
(length units, mesh refinement, precision) alongside a few
magnetics-only fields (frequency, AC solver choice) that are simply
ignored when solving for heat flow, since heat flow here is
steady-state only:

\dlgfig{dlg_problem_properties.png}{Problem Properties.}

\begin{description}[leftmargin=2.7cm,style=nextline]
  \item[Problem Type] Planar or Axisymmetric.
  \item[Length Units] The units nodes' X/Y coordinates are given in.
  \item[Frequency (Hz)] The AC excitation frequency for a magnetics
    solve (0 for a magnetostatic/DC problem).
  \item[Smart Mesh] Enables automatic mesh refinement near sharp
    corners.
  \item[Depth] The out-of-plane depth used to scale integral
    quantities (planar problems only).
  \item[Precision] The linear solver's convergence tolerance.
  \item[Min Angle] The minimum triangle angle the mesher is asked to
    maintain.
  \item[AC Solver] \emph{Successive Approximation} or a direct solve,
    for AC magnetics problems.
  \item[GPU Accel] Requests the CUDA-accelerated linear solve, if the
    installed solver executables were built with CUDA support.
  \item[Prev Type / Prev Solution] References a previous solution to
    use as the starting point (for nonlinear time-stepping problems).
  \item[Comment] A free-text description saved with the file.
\end{description}

\section{Exterior Region}
\label{sec:exterior-region}

Problem $\to$ Exterior Region\ldots defines the parameters used by the
Kelvin-transform asymptotic boundary condition (paired with a Block
Label marked ``Is an external region label'' and a boundary/segment set
up via Edit~$\to$~Create Open Boundary\ldots):

\dlgfig{dlg_exterior_region.png}{Exterior Region Properties.}

\section{Preferences}
\label{sec:preferences}

Edit $\to$ Preferences\ldots controls a few application-wide defaults:

\dlgfig{dlg_preferences.png}{Preferences.}

\begin{description}[leftmargin=2cm,style=nextline]
  \item[Use smart mesh refinement by default] The initial value of new
    problems' Smart Mesh setting.
  \item[Open XY plots in a separate window] Whether Plot X-Y
    (Section~\ref{sec:plotxy}) opens as its own window or docks inline.
  \item[Show the Output Window] The Solution Viewer's Output Window
    default visibility.
  \item[Dark theme] The application's default color theme.
\end{description}

\section{CPU/GPU/RAM Load Monitor}
\label{sec:load-monitor}

View $\to$ Load Monitor opens a live strip-chart of CPU, RAM, and (if
present) GPU utilization, with green/red markers showing when a solve
started and finished -- useful for judging how much of a long solve is
actually using the GPU accelerated path:

\winfig{view_loadmonitor_check.png}{The Load Monitor, docked over the
  geometry view.}

\chapter{The Solution Viewer}
\label{ch:solution-viewer}

Solving a problem (or choosing View Results\ldots/View Results (Heat
Flow)\ldots) opens the Solution Viewer, a dedicated window for
inspecting a solved mesh. Its menu bar and toolbar are independent of
the main editor's.

\section{File menu}
\winfig{sv_menu_file.png}{The Solution Viewer's File menu, shown over a
  density plot of $|B|$ from the magnetics worked example
  (Chapter~\ref{ch:example-magnetics}).}

\begin{description}[leftmargin=2.7cm,style=nextline]
  \item[Open Solution\ldots / Open Heat Flow Solution\ldots] Opens an
    \texttt{.ans} or \texttt{.anh} file directly.
  \item[Reload] Re-reads the current solution file from disk.
  \item[Print Preview\ldots / Print\ldots / Print Setup\ldots] Print
    the current plot.
  \item[Recent Files] Shares its list with the main editor's.
  \item[Switch to Classic GUI\ldots] Reopens the same solution in the
    Classic GUI's post-processor.
\end{description}

\section{Edit menu}
\winfig{sv_menu_edit.png}{The Edit menu.}

Copy as Bitmap copies the current plot to the clipboard as an image.

\section{Zoom menu}
\winfig{sv_menu_zoom.png}{The Zoom menu.}

Zoom In/Out/Natural and Scroll Left/Right/Up/Down work the same as
their main-editor counterparts.

\section{View menu and plot modes}
\winfig{sv_menu_view.png}{The View menu, over a Contour Plot -- the
  equipotential ($A$) contour lines of the same coil problem.}

\begin{description}[leftmargin=2.7cm,style=nextline]
  \item[Density Plot / Contour Plot] The two main plot modes. Density
    Plot fills each element with a color from a legend according to
    the selected quantity; Contour Plot instead draws lines of constant
    value, which for a magnetics solution are the field's flux lines,
    and for a heat-flow solution are isotherms.
  \item[Density Quantity] Which scalar quantity the Density Plot color
    scale represents -- $|B|$, $B_{re}$, $B_{im}$, $\log_{10}|B|$,
    $|H|$, or $|J_s+J_e|$ for a magnetics solution. (A heat-flow
    solution's Density Plot always shows the magnitude of the heat
    flux vector, labeled accordingly in the legend -- see
    Chapter~\ref{ch:example-heatflow}.)
  \item[Density Plot Options\ldots] Customize the legend's color range.
  \item[Smoothing] Blends each triangle's color from its corner nodes'
    averaged values, instead of showing one flat color per element.
  \item[Show Mesh / Show Points / Show Field Arrows] Overlay the
    triangular mesh, mesh nodes, or a fixed-length vector plot of the
    field's direction.
  \item[Show Legend] Toggles the color-scale legend.
  \item[Circuit Props\ldots] For a magnetics solution: shows computed
    current, voltage, flux linkage, and power for a circuit
    (Section~\ref{sec:sv-circuit-props}). Not applicable to a
    heat-flow solution.
  \item[BH Curves\ldots] Shows the BH curve of a nonlinear material
    used in the solution. Not applicable to a heat-flow solution.
  \item[Problem Info\ldots] Shows a summary of the solved problem's
    settings and property counts.
  \item[Output Window / Status Bar / Dark Theme] Same toggles as the
    main editor.
\end{description}

\section{Operation menu -- Point, Contour, and Area tools}
\winfig{sv_menu_operation.png}{The Operation menu.}

\begin{description}[leftmargin=2.5cm,style=nextline]
  \item[Point Properties] Click anywhere in the mesh to read off the
    interpolated field value at that exact point.
  \item[Contours] Click a sequence of points to draw a polyline across
    the mesh; use \emph{Finish Contour} (below) to report its length
    and the field difference between its two endpoints.
  \item[Areas] Click inside a block-label region to report its area and
    the area-weighted average field magnitude across every element that
    shares that label.
  \item[Finish Contour / Clear Contour] Completes or discards the
    contour currently being drawn.
\end{description}

\subsection{Circuit Properties}
\label{sec:sv-circuit-props}

\dlgfig{sv_circuit_props.png}{Circuit Properties for the ``Coil
  Circuit'' from the magnetics worked example: 5\,A total current, with
  the resulting voltage drop, flux linkage, and impedance.}

\section{Plot X-Y}
\label{sec:plotxy}
\winfig{sv_plotxy_chart2.png}{Plot X-Y along a drawn contour, showing
  $|A|$ sampled along its length.}

After drawing a contour with the Contours tool, Plot~X-Y samples a
chosen field quantity at evenly spaced points along it and displays the
result as a chart (switchable to a raw data table), exportable as a PNG
image or a CSV file.

\section{Integrate menu}

A convenience alias for the same contour-integral result shown by
Finish Contour, exposed as its own top-level command.

\section{Help menu}
\winfig{sv_menu_help.png}{The Solution Viewer's Help menu.}

\chapter{Worked Example: A Coil Cross-Section (Magnetics)}
\label{ch:example-magnetics}

This example builds a small magnetostatic problem from scratch: a
$100\,\mathrm{mm}\times 60\,\mathrm{mm}$ rectangular cross-section of a
current-carrying coil, surrounded by a fixed-boundary condition, solved
for its magnetic field. Chapter~\ref{ch:example-heatflow} continues
this same example by adding a heat-flow analysis of the coil's resistive
heating, reusing this exact geometry.

\begin{enumerate}
  \item \textbf{Draw the geometry.} Using the Add Node tool, place four
    nodes at $(0,0)$, $(100,0)$, $(100,60)$, and $(0,60)$ (all in
    millimeters). Using the Add Segment tool, connect them into a
    closed rectangle: $(0,0)\to(100,0)\to(100,60)\to(0,60)\to(0,0)$.
  \item \textbf{Define materials.} Open Problem $\to$ Materials
    Library\ldots and add ``Air'' and a solid ``Copper'' to the
    problem's Materials list (Section~\ref{sec:materials-library}).
  \item \textbf{Define a boundary condition.} Open Problem $\to$
    Boundary Properties\ldots, add a new boundary named ``Fixed
    A=0'' of Type \emph{Fixed A} with all fields left at zero
    (Section~\ref{sec:boundary-props}), then double-click each of the
    four segments and set its \emph{Boundary} field to ``Fixed A=0''.
  \item \textbf{Define a point property and circuit.} Open Problem
    $\to$ Point Properties\ldots and add ``Applied Current'' with
    $I_{re}=5$ (Section~\ref{sec:point-props}); double-click node
    $(0,0)$ and set its \emph{Point Property} to ``Applied Current''.
    Open Problem $\to$ Circuits\ldots and add ``Coil Circuit'', Series,
    Total Amps~re $=5$ (Section~\ref{sec:circuits}).
  \item \textbf{Place and assign a block label.} Using the Add Block
    Label tool, click once inside the rectangle (e.g.\ at
    $(50,30)$). Double-click it and set \emph{Block Type} to
    ``Copper'', \emph{In Circuit} to ``Coil Circuit'', and
    \emph{Number of Turns} to 1.
  \item \textbf{Save.} File $\to$ Save As\ldots, as \texttt{example.fem}.
  \item \textbf{Solve.} Mesh $\to$ Solve (Section~\ref{sec:mesh-menu}).
    The Solution Viewer opens automatically once the solve completes.
\end{enumerate}

\begin{figure}[H]
  \centering
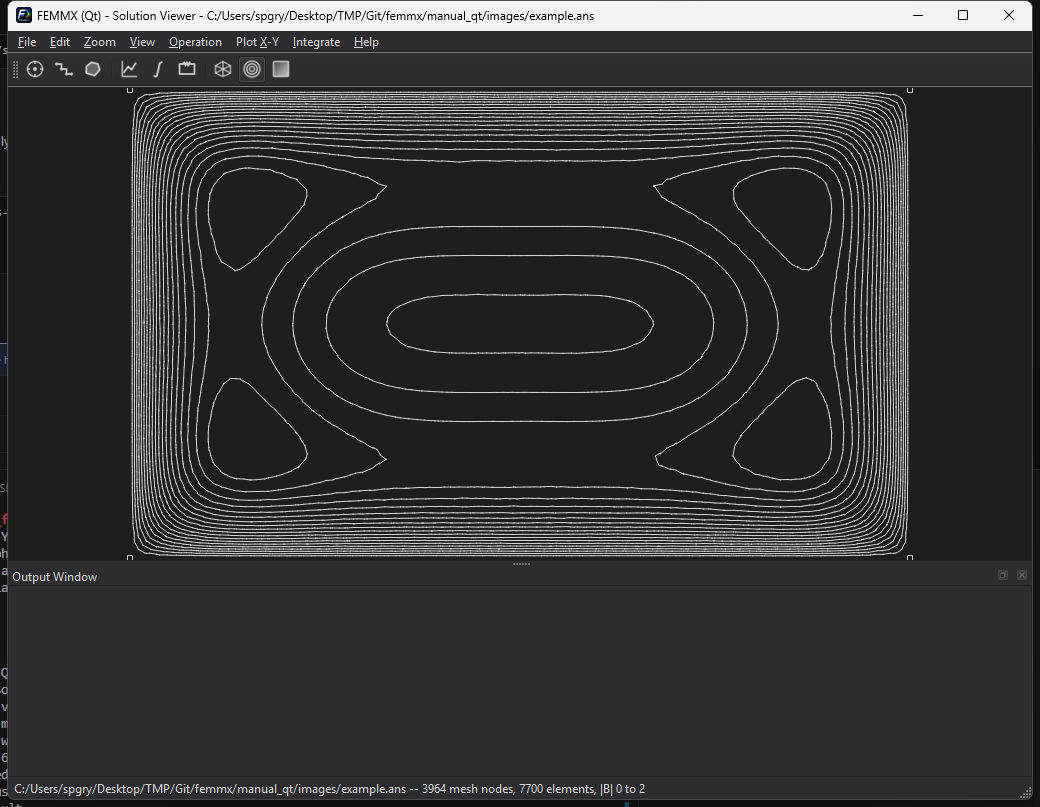
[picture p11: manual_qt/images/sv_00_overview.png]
  
  \caption{The solved coil problem's default Contour Plot: field lines
    bulge symmetrically out of the coil cross-section toward the four
    fixed-$A{=}0$ walls, exactly as expected for a single conductor
    centered in a shielded rectangular boundary.}
\end{figure}

\begin{figure}[H]
  \centering
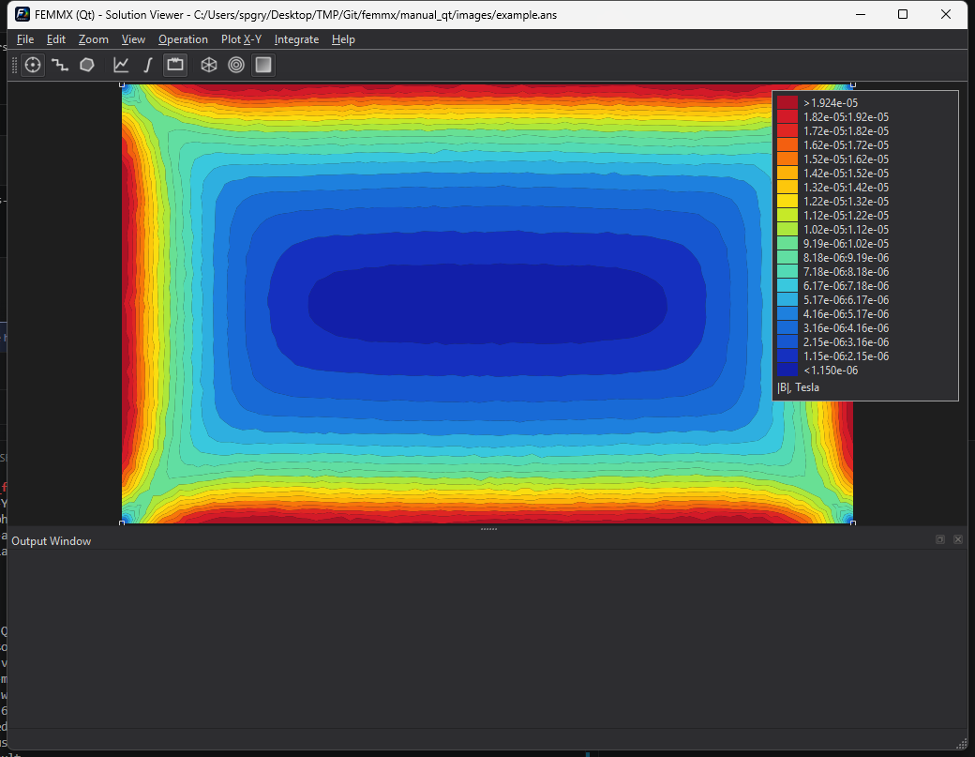
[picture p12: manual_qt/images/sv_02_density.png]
  
  \caption{The same solution as a Density Plot of $|B|$: field strength
    peaks inside the conductor and falls off toward the walls.}
\end{figure}

Opening View $\to$ Circuit Props\ldots and selecting ``Coil Circuit''
confirms the circuit actually carried the 5\,A we specified, and reports
the resulting voltage drop, flux linkage, and impedance
(Figure~\ref{fig:circuit-props-recap} -- the same figure shown in
Section~\ref{sec:sv-circuit-props}).

\begin{figure}[H]
  \centering
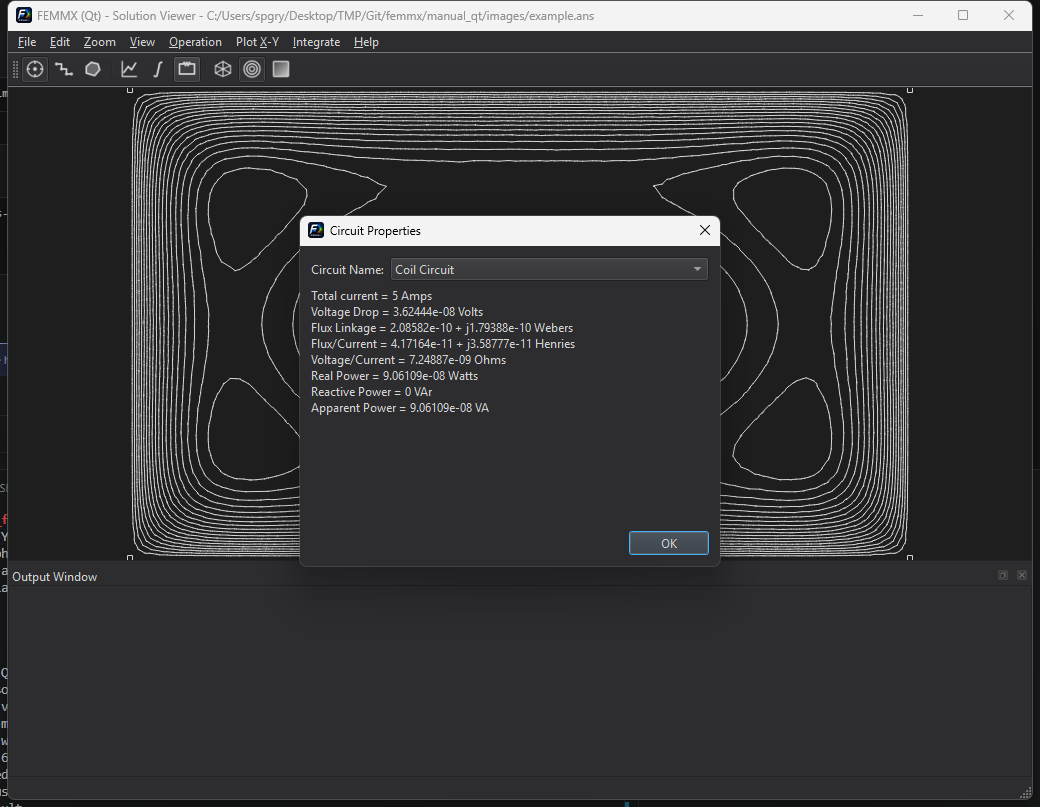
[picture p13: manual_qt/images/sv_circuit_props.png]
  
  \caption{Circuit Properties for ``Coil Circuit''.}
  \label{fig:circuit-props-recap}
\end{figure}

\chapter{Worked Example: Adding Heat Flow to the Same Model}
\label{ch:example-heatflow}

Continuing directly from Chapter~\ref{ch:example-magnetics}, this
example adds a steady-state heat-flow analysis to the exact same
rectangular geometry -- modeling the coil's resistive (I$^2$R) heating,
and asking how hot its cross-section gets before that heat conducts out
to the surrounding air.

\begin{enumerate}
  \item \textbf{Start the heat-flow file.} With \texttt{example.fem}
    still open, choose File $\to$ Save Heat Flow As\ldots. Because
    \texttt{example.fem} is already saved, the dialog defaults the
    suggested name to \texttt{example.feh} in the same folder
    (Figure~\ref{fig:save-heatflow-dialog}) -- accept it. The window
    title now shows both files, and its geometry (the same rectangle,
    same block label) is shared between them.
  \item \textbf{Define a convective boundary.} Open Problem $\to$ Heat
    Flow Boundary Properties\ldots and add a new boundary named
    ``Ambient Air'', Type \emph{Convection}, with $h=25\,
    \mathrm{W/(m^2K)}$ and $T_\infty=293\,\mathrm{K}$
    (Section~\ref{sec:heat-boundary-props}).
  \item \textbf{Assign it to the boundary.} Double-click each of the
    four segments in turn and set its \emph{Boundary (Heat Flow)} field
    to ``Ambient Air'' -- leaving the segment's magnetics
    \emph{Boundary} field (``Fixed A=0'') untouched, since the two
    assignments are independent.
  \item \textbf{Add a heat source.} A coil with no dissipation and a
    boundary already at ambient temperature would solve to a trivial,
    uniform $293\,\mathrm{K}$ everywhere -- not a very illuminating
    plot. Open Problem $\to$ Materials\ldots, Edit\ldots the ``Copper''
    material, and set its \textbf{qv} field
    (Section~\ref{sec:materials}) to $2{,}000{,}000\,\mathrm{W/m^3}$, a
    representative volumetric resistive-heating rate.
  \item \textbf{Save and solve.} File $\to$ Save Heat Flow, then Mesh
    $\to$ Solve (Heat Flow). The Solution Viewer opens on the resulting
    \texttt{.anh}.
\end{enumerate}

\begin{figure}[H]
  \centering
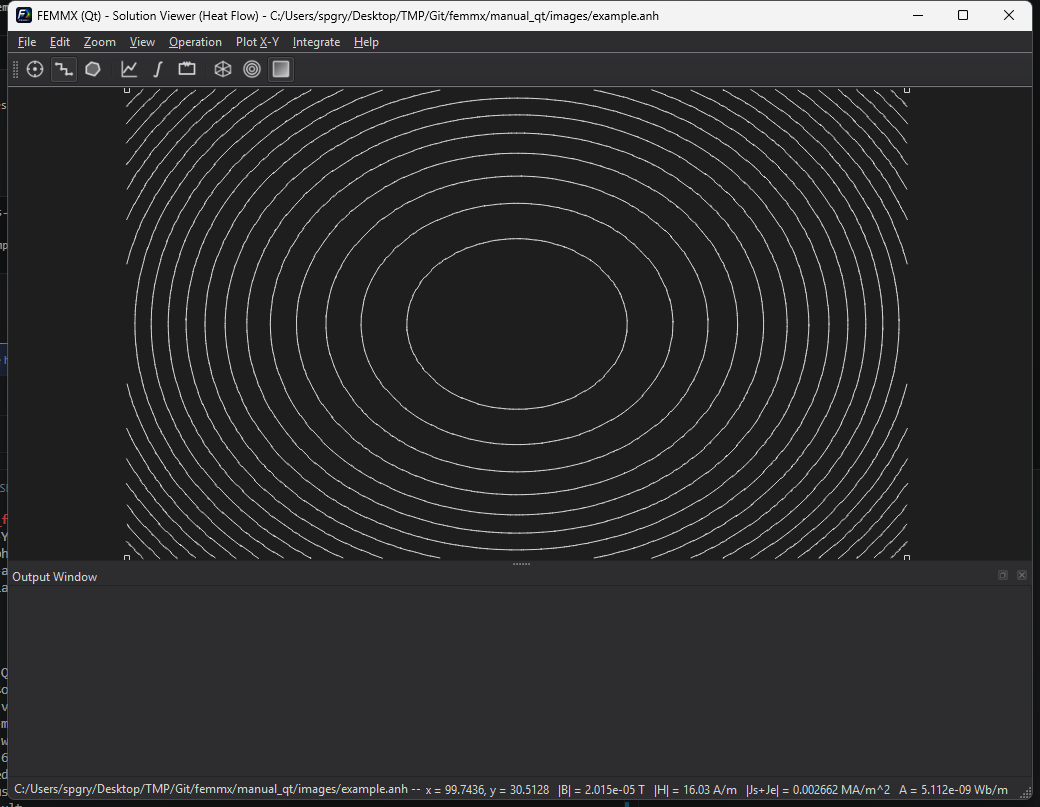
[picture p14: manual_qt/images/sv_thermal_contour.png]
  
  \caption{Contour Plot of the heat-flow solution: with the Density
    Plot/Contour Plot machinery reused from the magnetics side
    (Chapter~\ref{ch:solution-viewer}), the contour lines are now
    \emph{isotherms} -- concentric rings of constant temperature,
    hottest at the copper block's center and cooling smoothly toward
    the ambient boundary on all four sides.}
\end{figure}

\begin{figure}[H]
  \centering
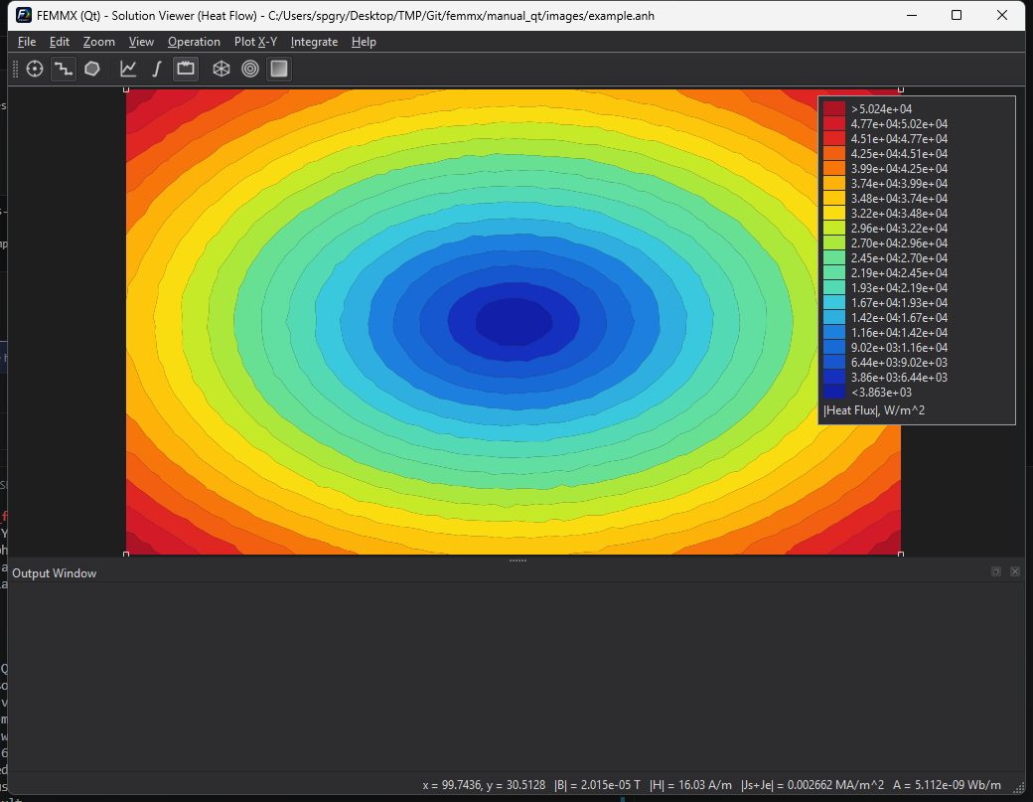
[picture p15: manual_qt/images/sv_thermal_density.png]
  
  \caption{Density Plot of the same solution: this always shows
    $|\mathrm{Heat\ Flux}|$ (in $\mathrm{W/m^2}$) for a heat-flow
    result. Flux is lowest at the symmetric center (where, by symmetry,
    no net heat flows in any one direction) and highest near the
    boundary, where all of the heat generated inside must ultimately
    cross to reach the ambient air.}
\end{figure}

This is the complete pattern for combining the two physics types on one
model: draw geometry once, keep materials in one shared list, and give
each physics type its own boundary/point property assignments and its
own Solve command -- without ever having to redraw or re-import
anything between them.

\end{document}

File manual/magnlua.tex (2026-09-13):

% ------------------------------------------------------------------------
%  My Format for a Article
%
% Modified by Claude (Anthropic), noreply@anthropic.com, 2026-07-09:
% documented mi_setgpuaccel (Problem Commands) and mi_setredraw (Editing
% Commands), the two Lua commands added since the femm-4.2-22Oct2023
% pre-fork baseline (see femm/femmeLua.cpp).
% Modified by Claude (Anthropic), noreply@anthropic.com, 2026-07-09:
% documented get_solve_stats() (Common Lua Command Set) -- reports the
% last solve's CPU/GPU/RAM/duration stats from the Load window, for
% benchmarking scripts (see femm/femm.cpp's lua_getsolvestats).

\chapter{Lua Scripting}

\section{What Lua Scripting?}

The Lua extension language has been used to add scripting/batch
processing facilities to FEMM. The Interactive Shell can run Lua scripts
through the {\tt Open Lua Script} selection on the Files menu, or Lua commands can be
entered in directly to the Lua Console Window.

Lua is a complete, open-source scripting language.  Source code for
Lua, in addition to detailed documentation about programming in
Lua, can be obtained from the Lua homepage at
\href{http://www.lua.org}{\tt http://www.lua.org}. 
%\verb+http://www.lua.org+. 
Because the
scripting files are text, they can be edited with any text editor
({\em e.g.} notepad). As of this writing, the latest release of Lua
is version 5.0. However, the version of Lua incorporated into FEMM
is Lua 4.0.

In addition to the standard Lua command set described in \cite{luaman}, a number of
FEMM-specific functions have been added for manipulating files in
both the pre- and post-processor.  These commands are described in
the following sections.

\section{Common Lua Command Set}

A number of FEMM-specific Lua commands exist that are not
associated with any particular problem type.

\begin{itemize}

\item {\tt clearconsole()} Clears the output window of the Lua console.

\item {\tt get\_solve\_stats()} Returns CPU/GPU/RAM usage and execution
time for the most recently completed solve (magnetics, heat flow,
electrostatics, or current flow), as tracked by the CPU/GPU/RAM Load
window (View menu). Intended for benchmarking scripts. Returns seven
values, in order: {\tt exec\_time} (seconds), {\tt cpu\_max}, {\tt
cpu\_avg}, {\tt gpu\_max}, {\tt gpu\_avg}, {\tt ram\_max}, {\tt
ram\_avg}. All usage figures are percentages from 0 to 100. {\tt
gpu\_max} and {\tt gpu\_avg} are {\tt -1} if no NVIDIA GPU was
available to sample. Raises a Lua error if the Load window is
disabled, or if no {\tt mi\_/hi\_/ei\_/ci\_analyze} has completed yet
in this session. Example:
\begin{verbatim}
mi_analyze(1)
exec_time,cpu_max,cpu_avg,gpu_max,gpu_avg,ram_max,ram_avg =
    get_solve_stats()
\end{verbatim}

\item {\tt newdocument(doctype)} Creates a new preprocessor document
and opens up a new preprocessor window.  Specify {\tt doctype} to
be {\tt 0} for a magnetics problem, {\tt 1} for an electrostatics
problem, {\tt 2} for a heat flow problem, or {\tt 3} for a current
flow problem. An alternative syntax for this command is {\tt create(doctype)} 

\item{\tt hideconsole()} Hides the floating Lua console window.

\item{\tt hidepointprops()} Hides the floating FEMM Properties
display window.

\item \texttt{messagebox("message")} displays the \texttt{"message" }string to the
screen in a pop-up message box.

\item {\tt open("filename")} Opens a document specified by
{\tt filename}.

\item \texttt{pause()} Waits for the ok button to be pressed, a debug helper.

\item \texttt{print()} This is standard Lua ``print'' command directed to the
output of the Lua console window. Any number of comma-separated items can be
printed at once via the print command.

\item \texttt{prompt("message")} This function allows a Lua script to prompt a
user for input. When this command is used, a dialog box pops up with the
\texttt{"message"} string on the title bar of the dialog box. The user can
enter in a single line of input via the dialog box. prompt returns the
user's input as a string. If a numerical value is desired, the syntax
\texttt{tonumber(prompt("message"))} can be used.

\item {\tt quit()} Close all documents and exit the the Interactive
Shell at the end of the currently executing Lua script.

\item {\tt setcompatibilitymode(value)} If {\tt value} is set to {\tt 1}, various magnetics-related
commands with complex arguments revert to their definitions in the FEMM 4.1 manual.  If {\tt value} is
set to {\tt 0}, the FEMM 4.2 definitions are used.  The default mode is compatibility mode {\tt 0}. Affected functions include:
\begin{itemize}
\item {\tt mi\_addmaterial}
\item {\tt mi\_modifymaterial}
\item {\tt mi\_addpointprop}
\item {\tt mi\_modifypointprop}
\item {\tt mi\_addcircprop}
\item {\tt mi\_modifycircprop}
\item {\tt mo\_getpointvalues}
\item {\tt mo\_lineintegral}
\item {\tt mo\_blockintegral}
\item {\tt mo\_getcircuitproperties}
\end{itemize}

\item {\tt setgui("name")} Chooses which GUI renders for the script
commands that produce GUI-derived output --- at present {\tt mi\_savepng}
and {\tt mo\_savepng}. Accepts {\tt "classic"} (equivalently {\tt "old"},
{\tt "femm"}, {\tt "mfc"} or {\tt 0}) for the traditional MFC interface,
and {\tt "qt"} ({\tt "new"}, {\tt "femmqt"} or {\tt 1}) for the newer Qt
interface. Lua itself always runs inside the classic application, so this
does not move the script; under {\tt "qt"} the commands above hand the
saved file to {\tt femmqt.exe}, which draws it with its own antialiased
density/contour plotting.

The setting lasts for the current session only. It starts out matching the
{\tt <PreferredGUI>} entry in {\tt femm.cfg}, so a script that never calls
{\tt setgui} renders with whichever GUI is preferred, but {\tt setgui}
deliberately does not write that entry back --- a script asking for one
image in a particular style should not change which GUI opens by default
afterwards. Use the {\tt View} menu's {\tt Switch To\ldots} item for that.

\item {\tt getgui()} Returns the current setting as a string, either
{\tt "classic"} or {\tt "qt"}.

\item{\tt showconsole()} Displays the floating Lua console window.

\item{\tt showpointprops()} Displays the floating FEMM Properties
display window.

\item{\tt smartmesh(state)} Calling with a state of 0 turns off ``smart mesh'' functionality for the present session; calling with a state of 1 turns ``smarth meshing'' on. The {\tt smartmesh} function applies across all problem types. 
To set smart meshing on or off on a file-by-file basis, use  \verb+mi_smartmesh+,\verb+ei_smartmesh+, \verb+hi_smartmesh+, and \verb+ci_smartmesh+, depending on problem type.  Note that calling the global \verb+smartmesh+ with a value of -1 sets the program to defer to the file-by-file setting rather than forcing all smart meshing on or off.
\end{itemize}

\section{Commands Added Since FEMM 4.2}

Every command below is specific to FEMMX and is not present in FEMM
4.2. They are documented in full alongside their peers in the sections
that follow; this list exists so that a script written for FEMM 4.2 can
be told apart from one that requires FEMMX.

\begin{itemize}
\item {\tt get\_solve\_stats()} --- returns the last solve's duration
and CPU/GPU/RAM usage, for benchmarking scripts.
\item {\tt setgui("name")} / {\tt getgui()} --- choose which GUI renders
for the commands that produce GUI-derived output.
\item {\tt mi\_setgpuaccel(flag)}, {\tt ei\_setgpuaccel(flag)},
{\tt hi\_setgpuaccel(flag)} and {\tt ci\_setgpuaccel(flag)} --- opt the
corresponding solver into CUDA-accelerated solving. All four solvers
carry the CUDA port and all four commands are registered; earlier
revisions of this list credited only the first two.
\item {\tt mi\_setredraw(flag)}, {\tt ei\_setredraw(flag)},
{\tt hi\_setredraw(flag)} and {\tt ci\_setredraw(flag)} --- suppress
redraws during a scripted sequence of edits. As with every other
command, the underscore-separated spelling ({\tt mi\_set\_redraw}, and
so on) works too.
\item {\tt mi\_savepng("filename")}, {\tt ei\_savepng("filename")},
{\tt hi\_savepng("filename")} and {\tt ci\_savepng("filename")} in the
editors, and {\tt mo\_savepng}, {\tt eo\_savepng}, {\tt ho\_savepng} and
{\tt co\_savepng} in the post-processors --- save a PNG screenshot; FEMM
4.2 could only write bitmaps and metafiles. The magnetics pair came
first; the other six were added later, since a script working in any
other physics could otherwise produce nothing but BMP or WMF.

All eight now honour {\tt setgui("qt")}. The six non-magnetics commands
refused it until {\tt femmqt} gained an editor and a Solution Viewer for
all four physics; what remains of that refusal is narrower and more
useful. The Qt Solution Viewer draws exactly one density quantity for
electrostatics, heat flow and current flow --- the field its solver
stores, namely {\tt |D|} in C/m$^2$, {\tt |F|} in W/m$^2$ and {\tt |J|}
in A/m$^2$ --- so if the view is showing the potential or the other
gradient instead, {\tt eo\_savepng} and its two siblings say so by name
and ask for {\tt setgui("classic")}, rather than rendering the one
quantity they do have and letting it pass for the one requested.
Contour plots, which show the potential, are drawn for every physics.
\end{itemize}

\section{Magnetics Preprocessor Lua Command Set}

A number of different commands are available in the preprocessor.
Two naming conventions can be used: one which separates words in
the command names by underscores, and one that eliminates the
underscores.

\subsection{Object Add/Remove Commands}

\begin{itemize}

\item{\tt mi\_addnode(x,y)} Add a new node at x,y

\item{\tt mi\_addsegment(x1,y1,x2,y2)} Add a new line segment from node
closest to (x1,y1) to node closest to (x2,y2)

\item{\tt mi\_addblocklabel(x,y)} Add a new block label at (x,y)

\item{\tt mi\_addarc(x1,y1,x2,y2,angle,maxseg)} Add a new arc segment
from the nearest node to (x1,y1) to the nearest node to (x2,y2)
with angle `angle' divided into `maxseg' segments.

\item{\tt mi\_deleteselected} Delete all selected objects.

\item{\tt mi\_deleteselectednodes} Delete selected nodes.

\item{\tt mi\_deleteselectedlabels} Delete selected block labels.

\item{\tt mi\_deleteselectedsegments} Delete selected segments.

\item{\tt mi\_deleteselectedarcsegments} Delete selects arcs.
\end{itemize}

\subsection{Geometry Selection Commands}

\begin{itemize}
\item{\tt mi\_clearselected()} Clear all selected nodes, blocks, segments
and arc segments.

\item{\tt mi\_selectsegment(x,y)} Select the line segment closest to
(x,y)

\item{\tt mi\_selectnode(x,y)} Select the node closest to (x,y).
Returns the coordinates of the selected node.

\item{\tt mi\_selectlabel(x,y)} Select the label closet to (x,y).
Returns the coordinates of the selected label.

\item{\tt mi\_selectarcsegment(x,y)} Select the arc segment closest to
(x,y)

\item{\tt mi\_selectgroup(n)} Select the $n^{th}$ group of nodes, segments, arc
segments and blocklabels. This function will clear all previously selected
elements and leave the editmode in 4 (group)

\item{\tt mi\_selectcircle(x,y,R,editmode)} selects objects within a circle of radius
R centered at (x,y).  If only x, y, and R parameters are given, the current
edit mode is used.  If the editmode parameter is used, 0 denotes nodes, 2
denotes block labels, 2 denotes segments, 3 denotes arcs, and 4 specifies
that all entity types are to be selected.

\item{\tt mi\_selectrectangle(x1,y1,x2,y2,editmode)} selects objects within a rectangle
defined by points (x1,y1) and (x2,y2). If no editmode parameter is supplied,
the current edit mode is used.  If the editmode parameter is used, 0 denotes
nodes, 2 denotes block labels, 2 denotes segments, 3 denotes arcs, and 4 
specifies that all entity types are to be selected.

\end{itemize}

\subsection{Object Labeling Commands}

\begin{itemize}
\item{\tt mi\_setnodeprop("propname",groupno)} Set the selected nodes to
have the nodal property {\tt mi\_"propname"} and group number {\tt
groupno}.

\item{\tt mi\_setblockprop("blockname", automesh, meshsize, "incircuit",
magdirection, group, turns)} Set the selected block labels to have the
properties:
\begin{itemize}
\item Block property {\tt "blockname"}.
\item {\tt automesh}: 0 = mesher defers to mesh size constraint defined in {\tt meshsize},
         1 = mesher automatically chooses the mesh density.
\item {\tt meshsize}: size constraint on the mesh in the block marked by this label.
\item Block is a member of the circuit named {\tt "incircuit"}
\item The magnetization is directed along an angle in measured in degrees denoted by the parameter
        {\tt magdirection}.  Alternatively, {\tt magdirection} can be a string containing a
		formula that prescribes the magnetization direction as a function of element position.
		In this formula {\tt theta} and {\tt R} denotes the angle in degrees of a line connecting the
		center each element with the origin and the length of this line, respectively;
		{\tt x} and {\tt y} denote the x- and y-position of the
		center of the each element.  For axisymmetric problems, {\tt r} and {\tt z} should
		be used in place of {\tt x} and {\tt y}.
\item A member of group number {\tt group}
\item The number of turns associated with this label is denoted by {\tt turns}.
\end{itemize}

\item{\tt mi\_setsegmentprop("propname", elementsize, automesh, hide,
group)} Set the select segments to have:
\begin{itemize}
\item Boundary property {\tt "propname"}
\item Local element size along segment no greater than {\tt
elementsize}
\item {\tt automesh}:  0 = mesher defers to the element constraint defined by {\tt elementsize},
        1 = mesher automatically chooses mesh size along the selected segments
\item {\tt hide}: 0 =  not hidden in post-processor, 1 == hidden in post processor
\item A member of group number {\tt group}
\end{itemize}

\item{\tt mi\_setarcsegmentprop(maxsegdeg, "propname", hide, group)} Set the
selected arc segments to:
\begin{itemize}
\item Meshed with elements that span at most {\tt maxsegdeg} degrees per
element
\item Boundary property {\tt "propname"}
\item {\tt hide}: 0 =  not hidden in post-processor, 1 == hidden in post processor
\item A member of group number {\tt group}
\end{itemize}

\item{\tt mi\_setgroup(n)} Set the group associated of the selected items to n

\end{itemize}

\subsection{Problem Commands}

\begin{itemize}
\item{\tt mi\_probdef(frequency,units,type,precision,(depth),(minangle),(acsolver)} changes the
problem definition. Set {\tt frequency} to the desired frequency in
Hertz.  The {\tt units} parameter specifies the units used for
measuring length in the problem domain.  Valid {\tt "units"}
entries are {\tt "inches"}, {\tt "millimeters"}, {\tt
"centimeters"}, {\tt "mils"}, {\tt "meters}, and {\tt
"micrometers"}. Set the parameter {\tt problemtype} to {\tt "planar"} for a 2-D
planar problem, or to {\tt "axi"} for an axisymmetric problem. The
{\tt precision} parameter dictates the precision required by the
solver.  For example, entering {\tt 1E-8} requires the RMS of the
residual to be less than $10^{-8}$.  A fifth parameter, representing the depth of
the problem in the into-the-page direction for 2-D planar problems, can also
also be specified. A sixth parameter represents the minimum angle constraint sent to the mesh generator.
A seventh parameter specifies the solver type to be used for AC problems.

\item{\tt mi\_analyze(flag)}
runs {\tt fkern} to solve the problem.  The {\tt flag} parameter
controls whether the {\tt fkern} window is visible or minimized.  For a
visible window, either specify no value for {\tt flag} or specify
{\tt 0}. For a minimized window, {\tt flag} should be set to {\tt
1}.

\item{\tt mi\_loadsolution()} loads and displays the solution corresponding to the
current geometry.

\item{\tt mi\_setgpuaccel(flag)} Sets whether {\tt fkern} should try
its optional CUDA-accelerated linear solve for this problem. Set {\tt
flag} to {\tt 1} to request GPU acceleration, or {\tt 0} (the default)
for the normal CPU solve. If {\tt fkern} was not built with CUDA
support, or if no usable GPU is found at run time, the solve
transparently falls back to the CPU solver. This setting is saved with
the problem file (like the AC solver choice), and can also be set via
the ``Use GPU Acceleration'' checkbox in the Problem Definition
dialog.

\item {\tt mi\_setfocus("documentname")} Switches the
magnetics input file upon which Lua commands are to act. If
more than one magnetics input file is being edited at a time,
this command can be used to switch between files so that the
multiple files can be operated upon programmatically via Lua. {\tt
documentname} should contain the name of the desired document as
it appears on the window's title bar.

\item{\tt mi\_saveas("filename")} saves the file with name {\tt "filename"}.
Note if you use a path you must use two backslashes {\em e.g.}
\verb+"c:\\temp\\myfemmfile.fem"+
\end{itemize}

\subsection{Mesh Commands}

\begin{itemize}
\item{\tt mi\_createmesh()} runs triangle to create a mesh. Note that this is not a
necessary precursor of performing an analysis, as {\tt
mi\_analyze()} will make sure the mesh is up to date before running
an analysis. The number of elements in the mesh is pushed back onto
the lua stack.

\item{\tt mi\_showmesh()} shows the mesh.

\item{\tt mi\_purgemesh()} clears the mesh out of both the screen and
memory.
\end{itemize}

\subsection{Editing Commands}

\begin{itemize}
\item{\tt mi\_copyrotate(bx, by, angle, copies, (editaction) )}
        \begin{itemize}
        \item{\tt bx, by} -- base point for rotation
        \item{\tt angle} -- angle by which the selected objects are incrementally
        shifted to make each copy.  {\tt angle} is measured in degrees.
        \item{\tt copies} -- number of copies to be produced from
        the selected objects.

        \end{itemize}

\item{\tt mi\_copytranslate(dx, dy, copies, (editaction))}
        \begin{itemize}
        \item{\tt dx,dy} -- distance by which the selected objects are incrementally shifted.
        \item{\tt copies} -- number of copies to be produced from the selected objects.
        \item{\tt editaction}  0 --nodes, 1 -- lines (segments), 2 --block labels, 3 -- arc
                segments, 4- group
        \end{itemize}

\item{\tt mi\_createradius(x, y, r)} turns a corner located at {\tt (x,y)} into a curve of radius {\tt r}.

\item{\tt mi\_moverotate(bx,by,shiftangle (editaction))}
        \begin{itemize}
        \item{\tt bx, by} -- base point for rotation
        \item{\tt shiftangle} -- angle in degrees by which the selected objects are rotated.
        \item{\tt editaction}  0 --nodes, 1 -- lines (segments), 2 --block labels, 3 -- arc
                segments, 4- group
        \end{itemize}

\item{\tt mi\_movetranslate(dx,dy,(editaction))}
        \begin{itemize}
        \item{\tt dx,dy} -- distance by which the selected objects are shifted.
        \item{\tt editaction}  0 --nodes, 1 -- lines (segments), 2 --block labels, 3 -- arc
                segments, 4- group
        \end{itemize}

\item{\tt mi\_scale(bx,by,scalefactor,(editaction))}
        \begin{itemize}
        \item{\tt bx, by} -- base point for scaling
        \item{\tt scalefactor} -- a multiplier that determines how
        much the selected objects are scaled
        \item{\tt editaction}  0 --nodes, 1 -- lines (segments), 2 --block labels, 3 -- arc
                segments, 4- group
        \end{itemize}

\item{\tt mi\_mirror(x1,y1,x2,y2,(editaction))}
mirror the selected objects about a line passing through the points
{\tt (x1,y1)} and {\tt (x2,y2)}. Valid {\tt editaction} entries are
0 for nodes, 1 for lines (segments), 2 for block labels, 3 for arc
segments, and 4 for groups.

\item{\tt mi\_seteditmode(editmode)}
Sets the current editmode to:
        \begin{itemize}
        \item{\tt "nodes"} - nodes
        \item{\tt "segments"} - line segments
        \item{\tt "arcsegments"} - arc segments
        \item{\tt "blocks"} - block labels
        \item{\tt "group"} - selected group
        \end{itemize}
This command will affect all subsequent uses of the other editing
commands, if they are used WITHOUT the {\tt editaction} parameter.

\item{\tt mi\_setredraw(flag)} Suspends or resumes the canvas redraw
while editing. Set {\tt flag} to {\tt 0} to suspend redraw before a
batch of edit operations ({\em e.g.} many {\tt mi\_copytranslate} or
{\tt mi\_copyrotate} calls on a densely-drawn model), and back to {\tt
1} (the default state) afterward to resume it and force a single
refresh showing everything that changed while it was off. Useful for
speeding up scripts that perform many repeated copy or move operations
on a model that already has a lot of geometry drawn.
\end{itemize}

\subsection{Zoom Commands}

\begin{itemize}
\item{\tt mi\_zoomnatural()} zooms to a ``natural'' view with sensible extents.
\item{\tt mi\_zoomout()} zooms out by a factor of 50\%.
\item{\tt mi\_zoomin()} zoom in by a factor of 200\%.
\item{\tt mi\_zoom(x1,y1,x2,y2)}
Set the display area to be from the bottom left corner specified by
{\tt (x1,y1}) to the top right corner specified by {\tt (x2,y2)}.
\end{itemize}

\subsection{View Commands}

\begin{itemize}
\item{\verb+mi_showgrid()+} Show the grid points.
\item{\verb+mi_hidegrid()+} Hide the grid points points.
\item{\verb+mi_grid_snap("flag")+}
Setting {\tt flag} to "on" turns on snap to grid, setting {\tt
flag} to {\tt "off"} turns off snap to grid.
\item{\verb+mi_setgrid(density,"type")+} Change the grid spacing.  The {\tt density}
parameter specifies the space between grid points, and the {\tt
type} parameter is set to {\tt "cart"} for cartesian coordinates or
{\tt "polar"} for polar coordinates.
\item{\tt mi\_refreshview()} Redraws the current view.
\item{\tt mi\_minimize()} minimizes the active magnetics input view.
\item{\tt mi\_maximize()} maximizes the active magnetics input view.
\item{\tt mi\_restore()} restores the active magnetics input view from a
 minimized or maximized state.
\item{\tt mi\_resize(width,height)} resizes the active magnetics input
 window client area to width $\times$ height.
\end{itemize}

\subsection{Object Properties}

\begin{itemize}
\item \texttt{mi\_getmaterial("materialname")} fetches the material specified by \texttt{materialname}
from the materials library.

\item \texttt{mi\_getmaterial("materialname", "foldername")} fetches the
material of that name from the library folder named \texttt{foldername}.
The shipped libraries contain entries in different folders that share a
name with a materially different material -- \texttt{Supermalloy} appears
in both Nickel Alloys and Metals Handbook DC Magnetization Curves with
relative permeabilities differing by a factor of half a million, and
\texttt{Ammonia} appears in heatlib.dat as both a saturated liquid and a
gas. Without a folder the first entry in file order wins and the other
cannot be reached from a script at all. Any level of the folder path may
be given. Asking for a folder that holds no such material is an error
rather than a fallback to the name-only match.

\item{\tt mi\_addmaterial("materialname", mu{\_}x, mu{\_}y, H{\_}c,
J, Cduct, Lam{\_}d, Phi{\_}hmax, lam{\_}fill, LamType, Phi{\_}hx, Phi{\_}hy,NStrands,WireD}) adds a
new material with called {\tt "materialname"} with the material
properties:
        \begin{itemize}
        \item{\tt mu{\_}x} Relative permeability in the x- or r-direction.
        \item{\tt mu{\_}y} Relative permeability in the y- or z-direction.
        \item{\tt H{\_}c} Permanent magnet coercivity in
        Amps/Meter.
        \item{\tt J} Real Applied source current density in Amps/mm$^2$.
        \item{\tt Cduct} Electrical conductivity of the material
        in~MS/m.
        \item{\tt Lam{\_}d} Lamination thickness in millimeters.
        \item{\tt Phi\_hmax} Hysteresis lag angle in degrees, used for nonlinear BH curves.
        \item{\tt Lam{\_}fill} Fraction of the volume occupied per lamination that
        is actually filled with iron (Note that this parameter defaults to 1 the
        {\tt femme} preprocessor dialog box because, by default, iron completely
        fills the volume)
        \item{\tt Lamtype} Set to
                \begin{itemize}
                \item 0 -- Not laminated or laminated in plane
                \item 1 -- laminated x or r
                \item 2 -- laminated y or z
                                \item 3 -- Magnet wire
                                \item 4 -- Plain stranded wire
                                \item 5 -- Litz wire
                                \item 6 -- Square wire
                \end{itemize}
        \item{\tt Phi\_hx} Hysteresis lag in degrees in the x-direction for linear problems.
        \item{\tt Phi\_hy} Hysteresis lag in degrees in the y-direction for linear problems.
                \item{\tt NStrands} Number of strands in the wire build.  Should be 1 for Magnet or Square wire.
                \item{\tt WireD} Diameter of each wire constituent strand in millimeters.
        \end{itemize}
Note that not all properties need be defined--properties that aren't defined are assigned default values.

\item{\tt mi\_addbhpoint("blockname",b,h)} Adds a B-H data point the
the material specified by the string {\tt "blockname"}.  The point to be added
has a flux density of {\tt b} in units of Teslas and a field
intensity of {\tt h} in units of Amps/Meter.

\item{\tt mi\_clearbhpoints("blockname")} Clears all B-H data points
associated with the material specified by {\tt "blockname"}.

\item{\tt mi\_addpointprop("pointpropname",a,j)}
adds a new point property of name {\tt "pointpropname"} with either
a specified potential {\tt a} in units Webers/Meter
or a point current {\tt j} in units of Amps. Set the
unused parameter pairs to 0.

\item{\tt mi\_addboundprop("propname", A0, A1, A2, Phi, Mu, Sig, c0, c1,
BdryFormat, ia, oa)} \\ adds a new boundary property with name {\tt
"propname"}
        \begin{itemize}
        \item For a ``Prescribed A'' type boundary condition, set the {\tt A0,
        A1, A2} and {\tt Phi} parameters as required. Set all other
        parameters to zero.

        \item For a ``Small Skin Depth'' type boundary condition, set the {\tt Mu}
        to the desired relative permeability and {\tt Sig} to the desired
        conductivity in MS/m.  Set {\tt BdryFormat} to 1 and all other
        parameters to zero.

        \item To obtain a ``Mixed'' type boundary condition, set {\tt C1} and
        {\tt C0} as required and {\tt BdryFormat} to 2.  Set all other
        parameters to zero.

        \item For a ``Strategic dual image'' boundary, set {\tt BdryFormat} to 3
        and set all other parameters to zero.

        \item For a ``Periodic'' boundary condition, set {\tt BdryFormat} to 4 and
        set all other parameters to zero.

        \item For an ``Anti-Perodic'' boundary condition, set {\tt BdryFormat} to
        5 set all other parameters to zero.
        
        \item  For a ``Periodic Air Gap'', set BdryFormat to 6. Parameters {\tt ia} and {\tt oa}specify the inner boundary angle and outer boundary angle, respectively.

        \item  For an ``Anti-periodic Air Gap'', set BdryFormat to 7.  The same  {\tt ia} and {\tt oa} parameters also apply here."

        \end{itemize}

\item{\tt mi\_addcircprop("circuitname", i, circuittype)} \\
adds a new circuit property with name {\tt "circuitname"} with a prescribed current, {\tt i}.
The {\tt circuittype} parameter is 0 for a parallel-connected circuit and 1 for a
series-connected circuit.
\item{\tt mi\_deletematerial("materialname")} deletes the material named {\tt
"materialname"}.
\item{\tt mi\_deleteboundprop("propname")} deletes the boundary property named
{\tt "propname"}.
\item{\tt mi\_deletecircuit("circuitname")} deletes the circuit named {\tt
circuitname}.
\item{\tt mi\_deletepointprop("pointpropname")} deletes the point property named
{\tt "pointpropname"}
\item{\verb+mi_modifymaterial("BlockName",propnum,value)+} This
function allows for modification of a material's properties without
redefining the entire material ({\em e.g.} so that current can be
modified from run to run).  The material to be modified is
specified by {\tt "BlockName"}.  The next parameter is the number
of the property to be set. The last number is the value to be
applied to the specified property.  The various properties that can
be modified are listed below:
\begin{center}
\begin{tabular}{lll} \hline
{\tt propnum}& Symbol & Description \\ \hline
 0 & {\tt BlockName} & Name of the material \\
 1 & $\mu_x$ & x (or r) direction relative permeability \\
 2 & $\mu_y$ & y (or z) direction relative permeability \\
 3 & $H_c$   & Coercivity, Amps/Meter \\
 4 & $J_r$   & Source current density, MA/m$^2$ \\
 5 & $\sigma$ & Electrical conductivity, MS/m \\
 6 & $d_{lam}$  & Lamination thickness, mm \\
 7 & $\phi_{hmax}$ & Hysteresis lag angle for nonlinear problems, degrees \\
 8 & LamFill & Iron fill fraction \\
 9 & LamType & 0 = None/In plane, 1 = parallel to x, 2=parallel to y \\
 10 & $\phi_{hx}$ & Hysteresis lag in x-direction for linear problems, degrees \\
 11 & $\phi_{hy}$ & Hysteresis lag in y-direction for linear problems, degrees \\
 \hline
 \end{tabular}
 \end{center}
\item{\verb+mi_modifyboundprop("BdryName",propnum,value)+}
This function allows for modification of a boundary property. The
BC to be modified is specified by {\tt "BdryName"}.  The next
parameter is the number of the property to be set. The last number
is the value to be applied to the specified property.  The various
properties that can be modified are listed below:
\begin{center}
\begin{tabular}{lll} \hline
{\tt propnum}& Symbol & Description \\ \hline
 0 & {\tt BdryName} & Name of boundary property \\
 1 & $A_0$ & Prescribed A parameter \\
 2 & $A_1$ & Prescribed A parameter \\
 3 & $A_2$ & Prescribed A parameter \\
 4 & $\phi$ & Prescribed A phase \\
 5 & $\mu$ & Small skin depth relative permeability \\
 6 & $\sigma$ & Small skin depth conductivity, MS/m \\
 7 & $c_0$ & Mixed BC parameter \\
 8 & $c_1$ & Mixed BC parameter \\
 9 & {\tt BdryFormat} & Type of boundary condition: \\
   &                 & 0 = Prescribed A \\
   &                 & 1 = Small skin depth \\
   &                 & 2 = Mixed \\
   &                 & 3 = Strategic Dual Image \\
   &                 & 4 = Periodic \\
   &                 & 5 = Antiperiodic \\ 
   &                 & 6 = Periodic Air Gap \\ 
   &                 & 7 = Antiperiodic Air Gap \\ 
10 & $ia$ &  Inner boundary angle for air gap element \\
11 & $oa$ & Outer boundary angle for air gap element \\ \hline
\end{tabular}
\end{center}
\item{\verb+mi_modifypointprop("PointName",propnum,value)+}
This function allows for modification of a point property. The
point property to be modified is specified by {\tt "PointName"}.
The next parameter is the number of the property to be set. The
last number is the value to be applied to the specified property.
The various properties that can be modified are listed below:
\begin{center}
\begin{tabular}{lll} \hline
{\tt propnum}& Symbol & Description \\ \hline
 0 & {\tt PointName} & Name of the point property \\
 1 & $A$ & Nodal potential, Weber/Meter \\
 2 & $J$ & Nodal current, Amps \\ \hline
\end{tabular}
\end{center}
\item{\verb+mi_modifycircprop("CircName",propnum,value)+}
This function allows for modification of a circuit property. The
circuit property to be modified is specified by {\tt "CircName"}.
The next parameter is the number of the property to be set. The
last number is the value to be applied to the specified property.
The various properties that can be modified are listed below:
\begin{center}
\begin{tabular}{lll} \hline
{\tt propnum}& Symbol & Description \\ \hline
 0 & {\tt CircName} & Name of the circuit property \\
 1 & $i$ & Total current \\
 2 & {\tt CircType} & 0 = Parallel, 1 = Series \\ \hline
 \end{tabular}
 \end{center}
\end{itemize}

\subsection{Miscellaneous}
\begin{itemize}
\item{\tt mi\_savebitmap("filename")} saves a bitmapped screenshot of the current
view to the file specified by {\tt "filename"}, subject to the {\tt
printf}-type formatting explained previously for the {\tt
savefemmfile} command.
\item{\tt mi\_savepng("filename")} saves a PNG screenshot of the current
view to the file specified by {\tt "filename"}, following the same file
name rules as {\tt mi\_savebitmap} above. Which GUI does the drawing
depends on the current {\tt setgui} setting: under {\tt setgui("classic")}
the traditional view renders itself and the result is encoded as PNG,
while under {\tt setgui("qt")} the file --- which must already be saved to
disk --- is handed to {\tt femmqt.exe}, which renders it offscreen with its
own antialiased plotting. An optional pixel size may be given as
{\tt mi\_savepng("filename",w,h)}; it applies only to the Qt renderer,
since the classic one can only capture its window at the size that window
actually is.
\item{\tt mi\_savemetafile("filename")} saves a metafile screenshot of the current
view to the file specified by {\tt "filename"}, subject to the {\tt
printf}-type formatting explained previously for the {\tt
savefemmfile} command.
\item{\tt mi\_refreshview()} Redraws the current view.
\item{\tt mi\_close()} Closes current magnetics preprocessor
document and destroys magnetics preprocessor window.
\item{\tt mi\_shownames(flag)} This function allow the user to display or hide the block label
names on screen.  To hide the block label names, {\tt flag} should be 0.  To display the
names, the parameter should be set to 1.
\item{\tt mi\_readdxf("filename")} This function imports a dxf file specified by {\tt "filename"}.
\item{\tt mi\_savedxf("filename")} This function saves geometry informationin a dxf file specified by {\tt "filename"}.
\item{\tt mi\_defineouterspace(Zo,Ro,Ri)} defines
an axisymmetric external region to be used in conjunction with the
Kelvin Transformation method of modeling unbounded problems.  The
{\tt Zo} parameter is the z-location of the origin of the outer region,
the {\tt Ro} parameter is the radius of the outer region, and the {\tt
Ri} parameter is the radius of the inner region ({\em i.e.} the region of
interest). In the exterior region, the permeability varies as a function of
distance from the origin of the external region.  These parameters
are necessary to define the permeability variation in the external
region.
\item{\tt mi\_attachouterspace()} marks all
selected block labels as members of the external region used for
modeling unbounded axisymmetric problems via the Kelvin
Transformation.
\item{\tt mi\_detachouterspace()} undefines all selected block labels
as members of the external region used for modeling unbounded axisymmetric
problems via the Kelvin Transformation.

\item{\tt mi\_attachdefault()} marks the
selected block label as the default block label.  This block label
is applied to any region that has not been explicitly labeled.

\item{\tt mi\_detachdefault()} undefines the default
attribute for the selected block labels.

\item{\tt mi\_makeABC(n,R,x,y,bc)} creates a series of circular shells that emulate the
impedance of an unbounded domain (i.e. an Inprovised Asymptotic Boundary
Condition).  The {\tt n} parameter contains the number of shells to be used
(should be between 1 and 10), {\tt R} is the radius of the solution domain, and
{\tt (x,y)} denotes the center of the solution domain.  The {\tt bc} parameter should
be specified as 0 for a Dirichlet outer edge or 1 for a Neumann outer edge.
If the function is called without all the parameters, the function makes up
reasonable values for the missing parameters. 

\item{\tt mi\_setprevious(filename,prevtype)} defines the previous solution to be used as the basis for an AC incremental
permeability or frozen permeability solution.  The {\tt prevtype} field is an integer that specifies whether the solution 
is to be incremental permeability ({\tt 1}) or frozen permeability ({\tt 2}). The filename should include the {\tt .ans}
extension, {\em e.g.} {\tt mi\_setprevious("mymodel.ans",1)}

\end{itemize}

\section{Magnetics Post Processor Command Set}

There are a number of Lua scripting commands designed to operate in
the postprocessor.  As with the preprocessor commands, these
commands can be used with either the underscore naming or with the
no-underscore naming convention.

\subsection{Data Extraction Commands}

\begin{itemize}
\item{\tt mo\_lineintegral(type)} Calculate the line integral for the defined contour
\begin{small}\begin{center}
\begin{tabular}{llllll}\hline
 {\tt type} & name & values 1 & values 2 & values 3 & values 4 \\  \hline
 0 & B.n & total B.n & avg B.n & - & -\\
 1 & H.t & total H.t & avg H.t & - & - \\
 2 & Contour length & surface area & - & -\\
 3 & Stress Tensor Force & DC r/x force & DC y/z force & $2\times$ r/x force & $2\times$ y/z force \\
 4 & Stress Tensor Torque& DC torque & $2\times$ torque & - & - \\
 5 & (B.n)\^{}2 & total (B.n)\^{}2 & avg (B.n)\^{}2 & - & - \\ \hline
\end{tabular}
\end{center}
\end{small}
Returns typically two (possibly complex) values as results. For force
and torque results, the $2\times$ results are only relevant for
problems where $\omega \neq 0$.  The $1\times$ results are only relevant
for incremental permeability AC problems.  The $1\times$ results represent
the force and torque interactions between the steady-state and the
incremental AC solution.

\item{\tt mo\_blockintegral(type)}
Calculate a block integral for the selected blocks
\begin{center}
\begin{tabular}{ll} \hline
 Type & Definition \\ \hline
 0 & $A \cdot J$ \\
 1 & A \\
 2 & Magnetic field energy \\
 3 & Hysteresis and/or lamination losses \\
 4 & Resistive losses \\
 5 & Block cross-section area \\
 6 & Total losses \\
 7 & Total current \\
 8 & Integral of $B_x$ (or $B_r$) over block \\
 9 & Integral of $B_y$ (or $B_z$) over block \\
 10 & Block volume \\
 11 & x (or r) part of steady-state Lorentz force \\
 12 & y (or z) part of steady-state Lorentz force \\
 13 & x (or r) part of $2\times$ Lorentz force \\
 14 & y (or z) part of $2\times$ Lorentz force \\
 15 & Steady-state Lorentz torque \\
 16 & $2 \times$ component of Lorentz torque \\
 17 & Magnetic field coenergy \\
 18 & x (or r) part of steady-state weighted stress tensor force \\
 19 & y (or z) part of steady-state weighted stress tensor force \\
 20 & x (or r) part of $2\times$ weighted stress tensor force \\
 21 & y (or z) part of $2\times$ weighted stress tensor force \\
 22 & Steady-state weighted stress tensor torque \\
 23 & $2 \times$ component of weighted stress tensor torque \\
 24 & $R^2$ ({\em i.e.} moment of inertia / density) \\ 
 25 & x (or r) part of $1\times$ weighted stress tensor force \\
 26 & y (or z) part of $1\times$ weighted stress tensor force \\
 27 & $1 \times$ component of weighted stress tensor torque \\
 28 & x (or r) part of $1\times$ Lorentz force \\
 29 & y (or z) part of $1\times$ Lorentz force \\
 30 & $1 \times$ component of Lorentz torque \\ \hline
 \end{tabular}
 \end{center}
This function returns one (possibly complex) value, {\em
e.g.}: {\tt volume = mo\_blockintegral(10)}

\item{\tt mo\_getpointvalues(X,Y)}
Get the values associated with the point at x,y RETURN values in
order
\begin{center}
\begin{tabular}{ll} \hline
Symbol & Definition \\ \hline
 A & vector potential A or flux $\phi$ \\
 B1 & flux density $B_x$ if planar, $B_r$ if axisymmetric \\
 B2 & flux density $B_y$ if planar, $B_z$ if axisymmetric \\
 Sig & electrical conductivity $\sigma$ \\
 E & stored energy density\\
 H1 & field intensity $H_x$ if planar, $H_r$ if axisymmetric \\
 H2 & field intensity $H_y$ if planar, $H_z$ if axisymmetric \\
 Je & eddy current density \\
 Js & source current density\\
 Mu1 & relative permeability $\mu_x$ if planar, $\mu_r$ if axisymmetric \\
 Mu2 & relative permeability $\mu_y$ if planar, $\mu_z$ if axisymmetric \\
 Pe & Power density dissipated through ohmic losses \\
 Ph & Power density dissipated by hysteresis \\ \hline
 \end{tabular}
\end{center}

Example: To catch all values at (0.01,0) use

{\tt A, B1, B2, Sig, E, H1, H2, Je, Js, Mu1, Mu2, Pe, Ph = mo\_getpointvalues(0.01,0)}

For magnetostatic problems, all imaginary quantities are zero.

\item \verb+mo_makeplot(PlotType,NumPoints,Filename,FileFormat)+
Allows Lua access to the X-Y plot routines.  If only {\tt PlotType} or only {\tt PlotType}
and {\tt NumPoints} are specified, the command is interpreted as a request to plot the
requested plot type to the screen.  If, in addition, the {\tt Filename} parameter is specified,
the plot is instead written to disk to the specified file name as an extended metafile.
If the {\tt FileFormat} parameter is also, the command is instead interpreted as a command to
write the data to disk to the specified file name, rather than display it to make a
graphical plot.
Valid entries for {\tt PlotType} are:
\begin{center}
\begin{tabular}{ll} \hline
{\tt PlotType} & Definition \\ \hline
0 & Potential \\
1 & $|B|$ \\
2 & $B \cdot n$ \\
3 & $B \cdot t$ \\
4 & $|H|$ \\
5 & $H \cdot n$ \\
6 & $H \cdot t$ \\
7 & $J_{eddy}$ \\
8 & $J_{source}+J_{eddy}$ \\
\hline
\end{tabular}
\end{center}
Valid file formats are
\begin{center}
\begin{tabular}{ll} \hline
{\tt FileFormat} & Definition \\ \hline
0 & Multi-column text with legend \\
1 & Multi-column text with no legend \\
2 & Mathematica-style formatting \\
\hline
\end{tabular}
\end{center}
For example, if one wanted to plot $B \cdot n$ to the screen with 200 points evaluated to
make the graph, the command would be:

\begin{tabular}{l} {\tt mo\_makeplot(2,200)} \end{tabular}

If this plot were to be written to disk as a metafile, the command would be:

\begin{tabular}{l} \verb+mo_makeplot(2,200,"c:\\temp\myfile.emf")+ \end{tabular}

To write data instead of a plot to disk, the command would
be of the form:

\begin{tabular}{l} \verb+mo_makeplot(2,200,"c:\\temp\myfile.txt",0)+ \end{tabular}

\item \verb+mo_getprobleminfo()+
Returns info on problem description.  Returns four values:
\begin{center}
\begin{tabular}{ll} \hline
Return value & Definition \\ \hline 
1 &  problem type  \\ 
2 &  frequency in Hz \\ 
3 &  depth assumed for planar problems in meters \\
4 &  length unit used to draw the problem in meters
\end{tabular}
\end{center}

\item{\verb+mo_getcircuitproperties("circuit")+}
Used primarily to obtain impedance information associated with
circuit properties.  Properties are returned for the circuit
property named {\tt "circuit"}. Three values are returned by the
function.  In order, these results are:
\begin{itemize}
        \item{\verb+current+} Current carried by the circuit
        \item{\verb+volts+}  Voltage drop across the circuit
        \item{\verb+flux_re+} Circuit's flux linkage
        \end{itemize}

\item{\verb+mo_getgapb("BdryName",angle)+}
Computes the radial and tangential flux density on the centerline of the
specified air gap element name (\verb+BdryName+) at the specified \verb+angle+.  The angle is specified in degrees."

\item{\verb+mo_getgapa("BdryName",angle)+}
Computes the magnetic vector potential on the centerline of the
specified air gap element name (\verb+BdryName+) at the specified \verb+angle+.  The angle is specified in degrees."

\item{\verb+mo_gapintegral("BdryName",inttype)+}
Computes an integral specifiedy by \verb+inttype+ over an air gap element specified
by \verb+BdryName+. Values for {\tt inttype} in are:
\begin{center}
\begin{tabular}{ll} \hline
0  & DC Torque\\
1  & DC Force\\
2  & Stored Energy\\
3  & 2X Torque\\
4  & 2X Force\\
5  & Interaction Torque\\
6  & Interaction Force\\
\hline
\end{tabular}
\end{center}
Torque and energy integrals return one result; force integrals return two results for the x- and y- direction force, respectively.

\item{\verb+mo_getgapharmonicsl("BdryName",n)+}
Returns the {\tt acc}, {\tt acs},{\tt brc},{\tt  brs},{\tt  btc}, and {\tt bts}.  These quantities represent the
components of vector potential, radial flux density, and tangential flux density on the centerline of the specified air gap element at the specified angle.  
For the $n^{th}$ harmonic, vector potential, radial flux density, and tangential flux density can be represented explicitly as functions of angle via:
\begin{eqnarray}
A    & = & acc \cos{n \theta} + acs \sin{n \theta} \nonumber  \\ 
B_r & = & brc \cos{n \theta}+ brs \sin{n \theta}   \nonumber \\
B_\theta & = & btc \cos{n \theta} + bts \sin{n \theta}  \nonumber
\end{eqnarray}
 The angle is  specified in degrees.  If the function is called with just the {\tt BdryName}, the function returns the number of harmonics available.

\end{itemize}

\subsection{Selection Commands}
\begin{itemize}
\item{\tt mo\_seteditmode(mode)} Sets the mode of the postprocessor to
point, contour, or area mode.  Valid entries for {\tt mode} are
{\tt "point"}, {\tt "contour"}, and {\tt "area"}.
\item{\tt mo\_selectblock(x,y)} Select the block that contains point (x,y).
\item{\tt mo\_groupselectblock(n)} Selects all of the blocks that are labeled by block
        labels that are members of group {\tt n}. If no number is specified ({\em i.e.} {\tt mo\_groupselectblock()} ),
                all blocks are selected.

\item{\tt mo\_addcontour(x,y)} Adds a contour point at (x,y). If this
is the first point then it starts a contour, if there are existing
points the contour runs from the previous point to this point. The
{\tt mo\_addcontour} command has the same functionality as a
right-button-click contour point addition when the program is
running in interactive mode.
\item{\tt mo\_bendcontour(angle,anglestep)} Replaces the straight line
formed by the last two points in the contour by an arc that spans {\tt angle}
degrees.  The arc is actually composed of many straight lines, each
of which is constrained to span no more than {\tt anglestep} degrees.
The {\tt angle} parameter can take on values from -180 to 180 degrees.
The {\tt anglestep} parameter must be greater than zero.  If there are less
than two points defined in the contour, this command is ignored.
\item{\tt mo\_selectpoint(x,y)} Adds a contour point at the closest
input point to (x,y).  If the selected point and a previous
selected points lie at the ends of an arcsegment, a contour is
added that traces along the arcsegment.  The {\tt mo\_selectpoint}
command has the same functionality as the left-button-click contour
point selection when the program is running in interactive mode.
\item{\tt mo\_clearcontour()} Clear a previously defined contour
\item{\tt mo\_clearblock()} Clear block selection
\end{itemize}

\subsection{Zoom Commands}
\begin{itemize}
\item{\verb+mo_zoomnatural()+} Zoom to the natural boundaries of
the geometry.
\item{\verb+mo_zoomin()+} Zoom in one level.
\item{\verb+mo_zoomout()+} Zoom out one level.
\item{\tt mo\_zoom(x1,y1,x2,y2)} Zoom to the window defined by lower left corner (x1,y1)
and upper right corner (x2,y2).

\end{itemize}

\subsection{View Commands}
\begin{itemize}
\item{\verb+mo_showmesh()+} Show the mesh.
\item{\verb+mo_hidemesh()+} Hide the mesh.
\item{\verb+mo_showpoints()+} Show the node points from the input geometry.
\item{\verb+mo_hidepoints()+} Hide the node points from the input geometry.
\item{\tt mo\_smooth("flag")} This function controls whether or not smoothing
is applied to the $B$ and $H$ fields, which are naturally
piece-wise constant over each element.  Setting {\tt flag} equal to
{\tt "on"} turns on smoothing, and setting {\tt flag} to {\tt
"off"} turns off smoothing.
\item{\verb+mo_showgrid()+} Show the grid points.
\item{\verb+mo_hidegrid()+} Hide the grid points points.
\item{\verb+mo_grid_snap("flag")+}
Setting {\tt flag} to "on" turns on snap to grid, setting {\tt
flag} to {\tt "off"} turns off snap to grid.
\item{\verb+mo_setgrid(density,"type")+} Change the grid spacing.  The {\tt density}
parameter specifies the space between grid points, and the {\tt
type} parameter is set to {\tt "cart"} for cartesian coordinates or
{\tt "polar"} for polar coordinates.
\item{\verb+mo_hidedensityplot()+} hides the flux density plot.
\item{\verb+mo_showdensityplot(legend,gscale,upper_B,lower_B,type)+}
Shows the flux density plot with options:
        \begin{itemize}
        \item {\tt legend} Set to {\tt 0} to hide the plot legend or {\tt 1} to show the plot
        legend.
        \item {\tt gscale} Set to {\tt 0} for a colour density plot or {\tt 1} for a grey scale density
        plot.
        \item{\verb+upper_B+} Sets the upper display limit for the density
        plot.
        \item{\verb+lower_B+} Sets the lower display limit for the density
        plot.
        \item{\tt type} Type of density plot to display. Valid
        entries are {\tt "bmag"}, {\tt "breal"},  {\tt "bimag"}, and{\tt "logb"} for
        magnitude, real component,  imaginary component, and log magnitude of flux density ($B$),
        respectively; {\tt "hmag"}, {\tt "hreal"}, and {\tt "himag"} for
        magnitude, real component, and imaginary component of field intensity ($H$);
		and {\tt "jmag"}, {\tt "jreal"}, and {\tt "jimag"} for
        magnitude, real component, and imaginary component of current density ($J$).
        \end{itemize}
        if {\tt legend} is set to {\tt -1} all parameters are ignored and default values are
        used {\em e.g.}: \\ \verb+mo_showdensityplot(-1)+
\item{\verb+mo_hidecontourplot()+} Hides the contour plot.
\item{\verb+mo_showcontourplot(numcontours,lower_A,upper_A,type)+}
shows the $A$ contour plot with options:
        \begin{itemize}
        \item{\tt numcontours} Number of $A$ equipotential lines
        to be plotted.
        \item{\verb+upper_A+} Upper limit for $A$ contours.
        \item{\verb+lower_A+} Lower limit for $A$ contours.
                \item{\verb+type+} Choice of {\tt "real"}, {\tt "imag"}, or {\tt "both"}
                        to show either the real, imaginary of both real and imaginary components of A.
        \end{itemize}
        If {\tt numcontours} is {\tt -1} all parameters are ignored and default
        values are used, {\em e.g.}: \\ \verb+mo_showcontourplot(-1)+

\item{\tt mo\_showvectorplot(type,scalefactor)}
controls the display of vectors denoting the field strength and
direction. The parameters taken are the \texttt{type} of plot,
which should be set to 0 for no vector plot,  1 for the real part of flux density B;
2 for the real part of field intensity H; 3 for the imaginary part of B;
4 for the imaginary part of H; 5 for both the real and imaginary parts of B;
and 6 for both the real and imaginary parts of H. The \texttt{scalefactor}
determines the relative length of the vectors. If the scale is set
to 1, the length of the vectors are chosen so that the highest flux
density corresponds to a vector that is the same length as the
current grid size setting.

\item{\tt mo\_minimize} minimizes the active magnetics output view.
\item{\tt mo\_maximize} maximizes the active magnetics output view.
\item{\tt mo\_restore} restores the active magnetics output view from a
 minimized or maximized state.
\item{\tt mo\_resize(width,height)} resizes the active magnetics output
 window client area to width $\times$ height.
\end{itemize}

\subsection{Miscellaneous}
\begin{itemize}

\item{\tt mo\_close()} Closes the current post-processor instance.
\item{\tt mo\_refreshview()} Redraws the current view.
\item{\tt mo\_reload()} Reloads the solution from disk.
\item{\tt mo\_savebitmap("filename")} saves a bitmapped screen shot of the current
view to the file specified by {\tt "filename"}. Note that if you
use a path you must use two backslashes ({\em e.g.}
\verb+"c:\\temp\\myfemmfile.fem"+). If the file name contains a space
({\em e.g.} file names like \verb+c:\program files\stuff+) you must
enclose the file name in (extra) quotes by using a
\verb+\"+ sequence. For example:\\
 \verb+mo_save_bitmap("\"c:\\temp\\screenshot.bmp\"")+
\item{\tt mo\_savepng("filename")} saves a PNG screen shot of the current
view to the file specified by {\tt "filename"}, following the same file
name rules as {\tt mo\_savebitmap} above. Which GUI does the drawing
depends on the current {\tt setgui} setting: under {\tt setgui("classic")}
the traditional post-processor view renders itself and the result is
encoded as PNG, while under {\tt setgui("qt")} the solution --- which must
already be saved to disk --- is handed to {\tt femmqt.exe}, which renders
it offscreen with its own antialiased density and contour plotting. An
optional pixel size may be given as {\tt mo\_savepng("filename",w,h)}; it
applies only to the Qt renderer, since the classic one can only capture
its window at the size that window actually is.

Under {\tt setgui("qt")} the post-processor's current view settings are
carried across to the Qt renderer, so that {\tt mo\_showdensityplot} and
friends affect the saved image as they do the on-screen one. What
crosses:

\begin{itemize}
\item the plot mode --- density or contour;
\item the density quantity ({\tt "bmag"}, {\tt "hreal"}, {\tt "logb"} and
      the rest), correctly interpreted for DC or AC, since the same
      index means different quantities in the two cases;
\item the density plot's lower and upper bounds;
\item the greyscale flag and the legend flag;
\item the number of contour lines;
\item the visible region. This matters for more than framing: the
      density plot's colour banding is scaled to what is {\em visible},
      so a full-model render cannot reproduce a zoomed-in view's
      colours.
\end{itemize}

What does {\em not} cross, and why:

\begin{itemize}
\item {\tt mo\_showvectorplot} --- the Qt viewer has no vector overlay
      at all, so a vector plot has no counterpart to render;
\item the contour mask and the real/imaginary contour selection
      ({\tt mo\_showcontourplot}'s {\tt "real"}/{\tt "imag"}/{\tt "both"}
      argument) --- the contour {\em count} and bounds do cross, the
      selection does not;
\item smoothing, mesh display and point display, which are the Qt
      viewer's own settings rather than part of what a saved image was
      asked for.
\end{itemize}

If you need any of those in a saved image, use {\tt setgui("classic")},
which captures exactly what the traditional post-processor is showing.
\item{\tt mo\_savemetafile("filename")} saves a metafile screenshot of the current
view to the file specified by {\tt "filename"}, subject to the {\tt
printf}-type formatting explained previously for the {\tt
savebitmap} command.
\item{\tt mo\_shownames(flag)} This function allow the user to display or hide the block label
names on screen.  To hide the block label names, {\tt flag} should be 0.  To display the
names, the parameter should be set to 1.

\item{\tt mo\_numnodes()} Returns the number of nodes in the in focus magnetics output mesh.
\item{\tt mo\_numelements()} Returns the number of elements in the in focus magnets output mesh.
\item{\tt mo\_getnode(n)} Returns the (x,y) or (r,z) position of the nth mesh node.
\item{\tt mo\_getelement(n)} MOGetElement[n] returns the following proprerties for the nth element:
    \begin{enumerate}
        \item Index of first element node
        \item Index of second element node
        \item Index of third element node
        \item x (or r) coordinate of the element centroid
        \item y (or z) coordinate of the element centroid
        \item element area using the length unit defined for the problem
        \item group number associated with the element
    \end{enumerate}

\end{itemize}

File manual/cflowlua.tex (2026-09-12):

% Modified by Claude (Anthropic), noreply@anthropic.com, 2026-07-21:
% documented ci_setgpuaccel (Problem Commands), added alongside the
% CUDA-accelerated linear solve ported to csolv (see csolv/spars_cuda.cu).
% Also documented ci_setredraw (Editing Commands), mirroring magnetics'
% mi_setredraw (see femm/CDRAWLUA.CPP).

\section{Current Flow Preprocessor Lua Command Set}

A number of different commands are available in the preprocessor.
Two naming conventions can be used: one which separates words in
the command names by underscores, and one that eliminates the
underscores.

\subsection{Object Add/Remove Commands}
\begin{itemize}
\item {\tt ci\_addnode(x,y)} Add a new node at x,y

\item {\tt ci\_addsegment(x1,y1,x2,y2)} Add a new line segment from node closest to
(x1,y1) to node closest to (x2,y2)

\item {\tt ci\_addblocklabel(x,y)} Add a new block label at (x,y)

\item {\tt ci\_addarc(x1,y1,x2,y2,angle,maxseg)} Add a new arc segment from the
nearest node to (x1,y1) to the nearest node to (x2,y2) with angle `angle'
divided into `maxseg' segments.

\item {\tt ci\_deleteselected} Delete all selected objects.

\item {\tt ci\_deleteselectednodes} Delete selected nodes.

\item {\tt ci\_deleteselectedlabels} Delete selected block labels.

\item {\tt ci\_deleteselectedsegments} Delete selected segments.

\item {\tt ci\_deleteselectedarcsegments} Delete selects arcs.
\end{itemize}

\subsection{Geometry Selection Commands}

\begin{itemize}
\item {\tt ci\_clearselected()} Clear all selected nodes, blocks, segments and arc
segments.

\item {\tt ci\_selectsegment(x,y)} Select the line segment closest to (x,y)

\item {\tt ci\_selectnode(x,y)} Select the node closest to (x,y).
Returns the coordinates of the selected node.

\item {\tt ci\_selectlabel(x,y)} Select the label closet to (x,y).
Returns the coordinates of the selected label.

\item {\tt ci\_selectarcsegment(x,y)} Select the arc segment closest to (x,y)

\item {\tt ci\_selectgroup(n)} Select the n$^{th}$ group of nodes, segments, arc
segments and block labels. This function will clear all previously selected
elements and leave the edit mode in 4 (group)

\item{\tt ci\_selectcircle(x,y,R,editmode)} selects objects within a circle of radius
R centered at (x,y).  If only x, y, and R parameters are given, the current
edit mode is used.  If the editmode parameter is used, 0 denotes nodes, 2
denotes block labels, 2 denotes segments, 3 denotes arcs, and 4 specifies
that all entity types are to be selected.

\item{\tt ci\_selectrectangle(x1,y1,x2,y2,editmode)} selects objects within a rectangle
defined by points (x1,y1) and (x2,y2). If no editmode parameter is supplied,
the current edit mode is used.  If the editmode parameter is used, 0 denotes
nodes, 2 denotes block labels, 2 denotes segments, 3 denotes arcs, and 4 
specifies that all entity types are to be selected.

\end{itemize}

\subsection{Object Labeling Commands}

\begin{itemize}
\item {\tt ci\_setnodeprop("propname",groupno, "inconductor")} Set the selected
nodes to have the nodal property \texttt{"propname"} and group
number \texttt{groupno}. The \texttt{"inconductor"} string
specifies which conductor the node belongs to. If the node doesn't
belong to a named conductor, this parameter can be set to
\texttt{"<None>"}.

\item {\tt ci\_setblockprop("blockname", automesh, meshsize, group)} Set the
selected block labels to have the properties:

Block property \texttt{"blockname"}.

\texttt{automesh}: 0 = mesher defers to mesh size constraint defined in
\texttt{meshsize}, 1 = mesher automatically chooses the mesh density.

\texttt{meshsize}: size constraint on the mesh in the block marked by this
label.

A member of group number \texttt{group}

\item {\tt ci\_setsegmentprop("propname", elementsize, automesh, hide, group,
"inconductor",)} Set the select segments to have:

Boundary property \texttt{"propname"}

Local element size along segment no greater than
\texttt{elementsize}

\texttt{automesh}: 0 = mesher defers to the element constraint defined by
\texttt{elementsize}, 1 = mesher automatically chooses mesh size along the
selected segments

\texttt{hide}: 0 = not hidden in post-processor, 1 == hidden in post
processor

A member of group number \texttt{group}

A member of the conductor specified by the string
\texttt{"inconductor".} If the segment is not part of a conductor,
this parameter can be specified as
\texttt{"<None>"}.

\item {\tt ci\_setarcsegmentprop(maxsegdeg, "propname", hide, group,
"inconductor")} Set the selected arc segments to:

Meshed with elements that span at most \texttt{maxsegdeg} degrees
per element

Boundary property \texttt{"propname"}

\texttt{hide}: 0 = not hidden in post-processor, 1 == hidden in post
processor

A member of group number \texttt{group}

A member of the conductor specified by the string
\texttt{"inconductor".} If the segment is not part of a conductor,
this parameter can be specified as
\texttt{"<None>"}.

\item{\tt ci\_setgroup(n)} Set the group associated of the selected items to n
\end{itemize}

\subsection{Problem Commands}

\begin{itemize}
\item {\tt ci\_probdef(units,type,frequency,precision,(depth),(minangle))} changes the problem
definition. The \texttt{units} parameter specifies the units used
for measuring length in the problem domain. Valid \texttt{"units"}
entries are
\texttt{"inches"}, \texttt{"millimeters"}, \texttt{"centimeters"},
\texttt{"mils"}, \texttt{"meters}, and \texttt{"micrometers"}. Set
\texttt{problemtype} to \texttt{"planar"} for a 2-D planar problem, or to
\texttt{"axi"} for an axisymmetric problem. The \texttt{frequency} parameter specifies the frequency
in Hz at which the analysis is to be performed. The \texttt{precision} parameter
dictates the precision required by the solver. For example, entering
\texttt{1.E-8} requires the RMS of the residual to be less than 10$^{ - 8}$.
A fourth parameter, representing the depth of the problem in the
into-the-page direction for 2-D planar problems, can also be specified
for planar problems. A sixth parameter represents the minimum angle constraint sent to the mesh generator.

\item {\tt ci\_analyze(flag)} runs \texttt{belasolv} to solve the problem. The
\texttt{flag} parameter controls whether the Belasolve window is visible or
minimized. For a visible window, either specify no value for
\texttt{flag} or specify 0. For a minimized window, \texttt{flag}
should be set to 1.

\item {\tt ci\_loadsolution()} loads and displays the solution corresponding to the
current geometry.

\item{\tt ci\_setgpuaccel(flag)} Sets whether {\tt csolv} should try
its optional CUDA-accelerated linear solve for this problem. Set {\tt
flag} to {\tt 1} to request GPU acceleration, or {\tt 0} (the default)
for the normal CPU solve. If {\tt csolv} was not built with CUDA
support, or if no usable GPU is found at run time, the solve
transparently falls back to the CPU solver. This setting is saved with
the problem file, mirroring magnetics' {\tt mi\_setgpuaccel}.

\item {\tt ci\_setfocus("documentname")} Switches the
electrostatics input file upon which Lua commands are to act. If
more than one electrostatics input file is being edited at a time,
this command can be used to switch between files so that the
multiple files can be operated upon programmatically via Lua. {\tt
documentname} should contain the name of the desired document as
it appears on the window's title bar.

\item {\tt ci\_saveas("filename")} saves the file with name
\texttt{"filename"}. Note if you use a path you must use two backslashes
{\em e.g.} \verb+c:\\temp\\myfemmfile.fee+

\end{itemize}

\subsection{Mesh Commands}

\begin{itemize}
\item \texttt{ci\_createmesh()} runs triangle to create a mesh. Note that this is not
a necessary precursor of performing an analysis, as
\texttt{ci\_analyze()} will make sure the mesh is up to date before
running an analysis. The number of elements in the mesh is pushed
back onto the lua stack.

\item \texttt{ci\_showmesh()} toggles the flag that shows or hides the mesh.

\item \texttt{ci\_purgemesh()} clears the mesh out of both the screen and memory.
\end{itemize}

\subsection{Editing Commands}
\begin{itemize}

\item \texttt{ci\_copyrotate(bx, by, angle, copies, (editaction) )}

\texttt{bx, by} -- base point for rotation

\texttt{angle} -- angle by which the selected objects are incrementally
shifted to make each copy. \texttt{angle} is measured in degrees.

\texttt{copies} -- number of copies to be produced from the selected
objects.

\texttt{editaction} 0 --nodes, 1 -- lines (segments), 2 --block labels, 3 --
arc segments, 4- group

\item \texttt{ci\_copytranslate(dx, dy, copies, (editaction))}

\texttt{dx,dy} -- distance by which the selected objects are incrementally
shifted.

\texttt{copies} -- number of copies to be produced from the selected
objects.

\texttt{editaction} 0 --nodes, 1 -- lines (segments), 2 --block labels, 3 --
arc segments, 4- group

\item{\tt ci\_setredraw(flag)} Suspends or resumes the canvas redraw
while editing. Set {\tt flag} to {\tt 0} to suspend redraw before a
batch of edit operations ({\em e.g.} many {\tt ci\_copytranslate} or
{\tt ci\_copyrotate} calls on a densely-drawn model), and back to {\tt
1} (the default state) afterward to resume it and force a single
refresh. Mirrors magnetics' {\tt mi\_setredraw}.

\item{\tt mi\_createradius(x, y, r)} turns a corner located at {\tt (x,y)} into a curve of radius {\tt r}.

\item \texttt{ci\_moverotate(bx,by,shiftangle (editaction))}

\texttt{bx, by} -- base point for rotation

\texttt{shiftangle} -- angle in degrees by which the selected objects are
rotated.

\texttt{editaction} 0 --nodes, 1 -- lines (segments), 2 --block labels, 3 --
arc segments, 4- group

\item \texttt{ci\_movetranslate(dx,dy,(editaction))}

\texttt{dx,dy} -- distance by which the selected objects are shifted.

\texttt{editaction} 0 --nodes, 1 -- lines (segments), 2 --block labels, 3 --
arc segments, 4- group

\item \texttt{ci\_scale(bx,by,scalefactor,(editaction))}

\texttt{bx, by} -- base point for scaling

\texttt{scalefactor} -- a multiplier that determines how much the selected
objects are scaled

\texttt{editaction} 0 --nodes, 1 -- lines (segments), 2 --block labels, 3 --
arc segments, 4- group

\item \texttt{ci\_mirror(x1,y1,x2,y2,(editaction))} mirror the selected objects about
a line passing through the points \texttt{(x1,y1)} and
\texttt{(x2,y2)}. Valid \texttt{editaction} entries are 0 for
nodes, 1 for lines (segments), 2 for block labels, 3 for arc
segments, and 4 for groups.

\item \texttt{ci\_seteditmode(editmode)} Sets the current editmode to:

\texttt{"nodes"} -- nodes

\texttt{"segments"} - line segments

\texttt{"arcsegments"} - arc segments

\texttt{"blocks"} - block labels

\texttt{"group"} - selected group

This command will affect all subsequent uses of the other editing
commands, if they are used WITHOUT the \texttt{editaction}
parameter.
\end{itemize}

\subsection{Zoom Commands}

\begin{itemize}
\item \texttt{ci\_zoomnatural()} zooms to a ``natural'' view with sensible extents.

\item \texttt{ci\_zoomout()} zooms out by a factor of 50{\%}.

\item \texttt{ci\_zoomin()} zoom in by a factor of 200{\%}.

\item \texttt{ci\_zoom(x1,y1,x2,y2)} Set the display area to be from the bottom left
corner specified by \texttt{(x1,y1}) to the top right corner
specified by \texttt{(x2,y2)}.
\end{itemize}

\subsection{View Commands}
\begin{itemize}
\item \texttt{ci\_showgrid()} Show the grid points.

\item \texttt{ci\_hidegrid()} Hide the grid points points.

\item \texttt{ci\_gridsnap("flag")} Setting flag to ''on'' turns on snap to grid,
setting flag to "off"turns off snap to grid.

\item \texttt{ci\_setgrid(density,"type")} Change the grid spacing. The density
parameter specifies the space between grid points, and the type
parameter is set to \texttt{"cart"} for Cartesian coordinates or
\texttt{"polar"} for polar coordinates.

\item \texttt{ci\_refreshview()} Redraws the current view.

\item{\tt ci\_minimize()} minimizes the active magnetics input view.

\item{\tt ci\_maximize()} maximizes the active magnetics input view.

\item{\tt ci\_restore()} restores the active magnetics input view from a
 minimized or maximized state.

\item{\tt ci\_resize(width,height)} resizes the active magnetics input
 window client area to width $\times$ height.

\end{itemize}

\subsection{Object Properties}

\begin{itemize}
\item \texttt{ci\_getmaterial("materialname")} fetches the material specified by \texttt{materialname}
from the materials library.

\item \texttt{ci\_getmaterial("materialname", "foldername")} fetches the
material of that name from the library folder named \texttt{foldername}.
The shipped libraries contain entries in different folders that share a
name with a materially different material -- \texttt{Supermalloy} appears
in both Nickel Alloys and Metals Handbook DC Magnetization Curves with
relative permeabilities differing by a factor of half a million, and
\texttt{Ammonia} appears in heatlib.dat as both a saturated liquid and a
gas. Without a folder the first entry in file order wins and the other
cannot be reached from a script at all. Any level of the folder path may
be given. Asking for a folder that holds no such material is an error
rather than a fallback to the name-only match.

\item \texttt{ci\_addmaterial("materialname", ox, oy, ex, ey, ltx, lty)} adds a new material with
called \texttt{"materialname"} with the material properties:

\texttt{ox} Electrical conductivity in the x- or r-direction in units of S/m.

\texttt{oy} Electrical conductivity in the y- or z-direction in units of S/m.

\texttt{ex} Relative permittivity in the x- or r-direction.

\texttt{ey} Relative permittivity in the y- or z-direction.

\texttt{ltx} Dielectric loss tangent in the x- or r-direction.

\texttt{lty} Dielectric loss tangent in the y- or z-direction.

\item \texttt{ci\_addpointprop("pointpropname",Vp,qp)} adds a new point property of
name \texttt{"pointpropname"} with either a specified potential
\texttt{Vp }a point current density \texttt{qp} in units of A/m.

\item \texttt{ci\_addboundprop("boundpropname", Vs, qs, c0, c1, BdryFormat)} adds a
new boundary property with name \texttt{"boundpropname"}

For a ``Fixed Voltage'' type boundary condition, set the
\texttt{Vs} parameter to the desired voltage and all other
parameters to zero.

To obtain a ``Mixed'' type boundary condition, set \texttt{C1} and
\texttt{C0} as required and \texttt{BdryFormat} to 1. Set all other
parameters to zero.

To obtain a prescribes surface current density, set \texttt{qs} to
the desired current density in A/m$^{2}$ and set \texttt{BdryFormat}
to 2.

For a ``Periodic'' boundary condition, set \texttt{BdryFormat} to 3
and set all other parameters to zero.

For an ``Anti-Perodic'' boundary condition, set \texttt{BdryFormat}
to 4 set all other parameters to zero.

\item \texttt{ci\_addconductorprop("conductorname", Vc, qc, conductortype)} adds a new
conductor property with name \texttt{"conductorname"} with either a
prescribed voltage or a prescribed total current. Set the unused
property to zero. The \texttt{conductortype} parameter is 0 for
prescribed current and 1 for prescribed voltage.

\item \texttt{ci\_deletematerial("materialname")} deletes the material named
\texttt{"materialname"}.

\item \texttt{ci\_deleteboundprop("boundpropname")} deletes the boundary property
named \texttt{"boundpropname"}.

\item \texttt{ci\_deleteconductor("conductorname")} deletes the conductor named
\texttt{conductorname}.

\item \texttt{ci\_deletepointprop("pointpropname")} deletes the point property named
\texttt{"pointpropname"}

\item \texttt{ci\_modifymaterial("BlockName",propnum,value)} This function allows for
modification of a material's properties without redefining the
entire material (e.g. so that current can be modified from run to
run). The material to be modified is specified by
\texttt{"BlockName"}. The next parameter is the number of the
property to be set. The last number is the value to be applied to
the specified property. The various properties that can be modified
are listed below:

\begin{tabular}{lll}
propnum & Symbol &  Description \\ \hline
 0 & \texttt{BlockName} & Name of the material \\
 1 & \texttt{ox} & x (or r) direction conductivity \\
 2 & \texttt{oy} & y (or z) direction conductivity \\
 3 & \texttt{ex} & x (or r) direction relative permittivity \\
 4 & \texttt{ey} & y (or z) direction relative permittivity \\
 5 & \texttt{ltx} & x (or r) direction dielectric loss tangent \\
 6 & \texttt{lty} & y (or z) direction dielectric loss tangent \\
\end{tabular}

\item \texttt{ci\_modifyboundprop("BdryName",propnum,value) }This function allows for
modification of a boundary property. The BC to be modified is specified by
\texttt{"BdryName"}. The next parameter is the number of the property to be
set. The last number is the value to be applied to the specified property.
The various properties that can be modified are listed below:

\begin{tabular}{lll}
 \texttt{propnum} & Symbol & Description \\ \hline
 0 & \texttt{BdryName} & Name of boundary property \\
 1 & \texttt{Vs} & Fixed Voltage \\
 2 & \texttt{qs} & Prescribed current density \\
 3 & \texttt{c0} & Mixed BC parameter \\
 4 & \texttt{c1} & Mixed BC parameter \\
 5 & \texttt{BdryFormat} & Type of boundary condition:\\
   &   &
   \begin{tabular}{lll}
   0 & = & Prescribed V \\
   1 & = & Mixed \\
   2 & = & Surface current density \\
   3 & = & Periodic \\
   4 & = & Antiperiodic
   \end{tabular}
\end{tabular}

\item \texttt{ci\_modifypointprop("PointName",propnum,value)} This function allows for
modification of a point property. The point property to be modified
is specified by \texttt{"PointName"}. The next parameter is the
number of the property to be set. The last number is the value to
be applied to the specified property. The various properties that
can be modified are listed below:

\begin{tabular}{lll}
\texttt{propnum} & Symbol & Description \\ \hline
 0 & \texttt{PointName} & Name of the point property \\
 1 & \texttt{Vp} & Prescribed nodal voltage \\
 2 & \texttt{qp} & Point current density in A/m
\end{tabular}

\item \texttt{ci\_modifyconductorprop("ConductorName",propnum,value)} This function
allows for modification of a conductor property. The conductor
property to be modified is specified by \texttt{"ConductorName"}.
The next parameter is the number of the property to be set. The
last number is the value to be applied to the specified property.
The various properties that can be modified are listed below:

\begin{tabular}{lll}
\texttt{propnum} & Symbol & Description \\ \hline
  0 & \texttt{ConductorName} & Name of the conductor property \\
  1 & \texttt{Vc} &  Conductor voltage \\
  2 & \texttt{qc} &  Total conductor current \\
  3 & \texttt{ConductorType} & 0 = Prescribed current, 1 = Prescribed voltage
\end{tabular}

\end{itemize}

\subsection{Miscellaneous}

\begin{itemize}
\item \texttt{ci\_savebitmap("filename")} saves a bitmapped screenshot of the current
view to the file specified by \texttt{"filename"}, subject to the
\texttt{printf}-type formatting explained previously for the
\texttt{ci\_saveas} command.

\item \texttt{ci\_savemetafile("filename")} saves a metafile screenshot of the current
view to the file specified by \texttt{"filename"}, subject to the
\texttt{printf}-type formatting explained previously for the
\texttt{ci\_saveas} command.

\item \texttt{ci\_refreshview()} Redraws the current view.

\item \texttt{ci\_close()} closes the preprocessor window and
destroys the current document.

\item \texttt{ci\_shownames(flag)} This function allow the user to display or hide the
block label names on screen. To hide the block label names,
\texttt{flag} should be 0. To display the names, the parameter
should be set to 1.

\item{\tt ci\_readdxf("filename")} This function imports a dxf file specified by {\tt "filename"}.

\item{\tt ci\_savedxf("filename")} This function saves geometry information in a dxf file specified by {\tt "filename"}.

\item{\tt ci\_defineouterspace(Zo,Ro,Ri)} defines
an axisymmetric external region to be used in conjunction with the
Kelvin Transformation method of modeling unbounded problems.  The
{\tt Zo} parameter is the z-location of the origin of the outer region,
the {\tt Ro} parameter is the radius of the outer region, and the {\tt
Ri} parameter is the radius of the inner region ({\em i.e.} the region of
interest). In the exterior region, the permeability varies as a function of
distance from the origin of the external region.  These parameters
are necessary to define the permeability variation in the external
region.

\item{\tt ci\_attachouterspace()} marks all
selected block labels as members of the external region used for
modeling unbounded axisymmetric problems via the Kelvin
Transformation.

\item{\tt ci\_detachouterspace()} undefines all selected block labels
as members of the external region used for modeling unbounded axisymmetric
problems via the Kelvin Transformation.

\item{\tt ci\_attachdefault()} marks the
selected block label as the default block label.  This block label
is applied to any region that has not been explicitly labeled.

\item{\tt ci\_detachdefault()} undefines the default
attribute for the selected block labels.

\item{\tt ci\_makeABC(n,R,x,y,bc)} creates a series of circular shells that emulate the
impedance of an unbounded domain (i.e. an Inprovised Asymptotic Boundary
Condition).  The {\tt n} parameter contains the number of shells to be used
(should be between 1 and 10), {\tt R} is the radius of the solution domain, and
{\tt (x,y)} denotes the center of the solution domain.  The {\tt bc} parameter should
be specified as 0 for a Dirichlet outer edge or 1 for a Neumann outer edge.
If the function is called without all the parameters, the function makes up
reasonable values for the missing parameters.

\end{itemize}

\section{Current Flow Post Processor Command Set}

There are a number of Lua scripting commands designed to operate in
the postprocessor. As with the preprocessor commands, these
commands can be used with either the underscore naming or with the
no-underscore naming convention.

\subsection{Data Extraction Commands}
\begin{itemize}

\item \texttt{co\_lineintegral(type)} Calculate the line integral for the defined contour

% inttype==0 => E.t 
% inttype==1 => J.n
% inttype==2 => Contour Length
% inttype==3 => Average Voltage
% inttype==4 => Stress Tensor Force
% inttype==5 => Stress Tensor Torque

\begin{tabular}{ll}
\texttt{type} & Integral \\ \hline
 0 & $E \cdot t$ \\
 1 & $J \cdot n$ \\
 2 & Contour length \\
 3 & Average voltage over contour \\
 4 & Force from stress tensor \\
 5 & Torque from stress tensor
\end{tabular}

This integral returns either 1 or 2 values, depending on the
integral type, $e.g.:$

\texttt{Fx, Fy = co\_lineintegral(4)}

\item \texttt{co\_blockintegral(type)} Calculate a block integral for the selected
blocks

\begin{tabular}{ll}
\texttt{type} & Integral \\ \hline
	 0  & Real Power \\
	 1  & Reactive Power \\
	 2  & Apparent Power \\
	 3  & Time-Average Stored Energy \\
	 4  & Block cross-section area \\
	 5  & Block volume \\
	 6  & x (or r) direction Weighted Stress Tensor force, DC component \\
	 7  & y (or z) direction Weighted Stress Tensor force, DC component \\
	 8  & x (or r) direction Weighted Stress Tensor force, 2x frequency component \\
	 9  & y (or z) direction Weighted Stress Tensor force, 2x frequency component \\
	 10 & Weighted Stress Tensor torque, DC component \\
	 11 & Weighted Stress Tensor torque, 2x frequency component
\end{tabular}

Returns a value that can be complex, as necessary.

\item \texttt{co\_getpointvalues(X,Y)} Get the values associated with the point at x,y
The return values, in order, are:

\begin{tabular}{ll}
\texttt{Symbol} &  Definition \\ \hline
\texttt{V} & Voltage \\
\texttt{Jx} & x- or r- direction component of current density \\
\texttt{Jy} & y- or z- direction component of current density \\
\texttt{Kx} & x- or r- direction component of AC conductivity \\
\texttt{Ky} & y- or z- direction component of AC conductivity \\
\texttt{Ex} & x- or r- direction component of electric field intensity \\
\texttt{Ey} & y- or z- direction component of electric field intensity \\
\texttt{ex} & x- or r- direction component of permittivity \\
\texttt{ey} & y- or z- direction component of permittivity \\
\texttt{Jdx} & x- or r- direction component of displacement current density \\
\texttt{Jdy} & y- or z- direction component of displacement current density \\
\texttt{ox} & x- or r- direction component of permittivity \\
\texttt{oy} & y- or z- direction component of permittivity \\
\texttt{Jcx} & x- or r- direction component of conduction current density \\
\texttt{Jcy} & y- or z- direction component of conduction current density \\
\end{tabular}

\item \texttt{co\_makeplot(PlotType,NumPoints,Filename,FileFormat) }Allows Lua access
to the X-Y plot routines. If only PlotType or only PlotType and NumPoints
are specified, the command is interpreted as a request to plot the requested
plot type to the screen. If, in addition, the Filename parameter is
specified, the plot is instead written to disk to the specified file name as
an extended metafile. If the FileFormat parameter is also, the command is
instead interpreted as a command to write the data to disk to the specified
file name, rather than display it to make a graphical plot. Valid entries
for PlotType are:

\begin{tabular}{ll}
\texttt{PlotType} &  Definition \\ \hline
 0 & \texttt{V (Voltage)} \\
 1 & \texttt{$\vert$J$\vert$ (Magnitude of current density)} \\
 2 & \texttt{J . n (Normal current density)} \\
 3 & \texttt{J . t (Tangential current density)} \\
 4 & \texttt{$\vert$E$\vert$ (Magnitude of field intensity)} \\
 5 & \texttt{E . n (Normal field intensity)} \\
 6 & \texttt{E . t (Tangential field intensity)} \\
 7 & \texttt{$\vert$Jc$\vert$ (Magnitude of conduction current density)} \\
 8 & \texttt{Jc . n (Normal conduction current density)} \\
 9 & \texttt{Jc . t (Tangential conduction current density)} \\
 10 & \texttt{$\vert$Jd$\vert$ (Magnitude of displacement current density)} \\
 11 & \texttt{Jd . n (Normal displacement current density)} \\
 12 & \texttt{Jd . t (Tangential displacement current density)} \\
\end{tabular}

\vspace*{8pt}
Valid file formats are:

\begin{tabular}{ll}
\texttt{FileFormat} &  Definition  \\ \hline
 0 & \texttt{Multi-column text with legend } \\
 1 & \texttt{Multi-column text with no legend } \\
 2 & \texttt{Mathematica-style formatting}
\end{tabular}

For example, if one wanted to plot $V $ to the screen with 200 points evaluated
to make the graph, the command would be: \newline
\texttt{co\_makeplot(0,200) } \newline
If this plot were to be written to disk as a metafile, the command
would be:\texttt{ } \newline
\texttt{co\_makeplot(0,200,"c:temp.emf")} \newline
To write data instead of a plot to disk, the command would be of
the form:\texttt{ } \newline
\texttt{co\_makeplot(0,200,"c:temp.txt",0)} \newline

\item \texttt{co\_getprobleminfo() } 
Returns info on problem description. Returns four values:

\begin{tabular}{ll} \hline
Return value & Definition \\ \hline 
1 &  problem type  \\ 
2 &  frequency in Hz \\ 
3 &  depth assumed for planar problems in meters.\\
4 &  length unit used to draw the problem, represented in meters
\end{tabular}

\item \texttt{co\_getconductorproperties("conductor")} Properties are returned for the
conductor property named "conductor". Two values are returned: The voltage
of the specified conductor, and the current on the specified
conductor.
\end{itemize}

\subsection{Selection Commands}

\begin{itemize}
\item \texttt{co\_seteditmode(mode) }Sets the mode of the postprocessor to point,
contour, or area mode. Valid entries for mode are\texttt{ "point",
"contour", }and\texttt{ "area". }

\item \texttt{co\_selectblock(x,y) }Select the block that contains point\texttt{
(x,y).}

\item \texttt{co\_groupselectblock(n) }Selects all of the blocks that are labeled by
block labels that are members of group n. If no number is specified
({\em i.e.} \texttt{co\_groupselectblock()}), all blocks are selected.

\item \texttt{co\_selectconductor("name")} Selects all nodes, segments, and arc
segments that are part of the conductor specified by the string
\texttt{("name")}. This command is used to select conductors for the
purposes of the ``weighted stress tensor'' force and torque
integrals, where the conductors are points or surfaces, rather than
regions ({\em i.e.} can't be selected with \texttt{co\_selectblock}).

\item \texttt{co\_addcontour(x,y) }Adds a contour point at\texttt{ (x,y). }If this is
the first point then it starts a contour, if there are existing
points the contour runs from the previous point to this point. The
\texttt{co\_addcontour }command has the same functionality as a
right-button-click contour point addition when the program is
running in interactive mode.\texttt{ }

\item \texttt{co\_bendcontour(angle,anglestep)} Replaces the straight line formed by
the last two points in the contour by an arc that spans angle
degrees. The arc is actually composed of many straight lines, each
of which is constrained to span no more than anglestep degrees. The
\texttt{angle} parameter can take on values from -180 to 180
degrees. The \texttt{anglestep} parameter must be greater than
zero. If there are less than two points defined in the contour,
this command is ignored.

\item \texttt{co\_selectpoint(x,y)} Adds a contour point at the closest input point to
\texttt{(x,y).} If the selected point and a previous selected points lie at
the ends of an arcsegment, a contour is added that traces along the
arcsegment. The \texttt{selectpoint} command has the same
functionality as the left-button-click contour point selection when
the program is running in interactive mode.

\item \texttt{co\_clearcontour()} Clear a previously defined contour

\item \texttt{co\_clearblock()} Clear block selection
\end{itemize}

\subsection{Zoom Commands}

\begin{itemize}
\item \texttt{co\_zoomnatural()} Zoom to the natural boundaries of the geometry.

\item \texttt{co\_zoomin()} Zoom in one level.

\item \texttt{co\_zoomout()} Zoom out one level.

\item \texttt{co\_zoom(x1,y1,x2,y2)} Zoom to the window defined by lower left corner
\texttt{(x1,y1)} and upper right corner\texttt{ (x2,y2).}
\end{itemize}

\subsection{View Commands}

\begin{itemize}
\item \texttt{co\_showmesh()} Show the mesh.

\item \texttt{co\_hidemesh()} Hide the mesh.

\item \texttt{co\_showpoints()} Show the node points from the input geometry.

\item \texttt{co\_hidepoints()} Hide the node points from the input geometry.

\item \texttt{co\_smooth("flag")} This function controls whether or not smoothing is
applied to the $D$ and $E$ fields which are naturally piece-wise
constant over each element. Setting flag equal to \texttt{"on"}
turns on smoothing, and setting flag to \texttt{"off"} turns off
smoothing.

\item \texttt{co\_showgrid()} Show the grid points.

\item \texttt{co\_hidegrid()} Hide the grid points points.

\texttt{co\_gridsnap("flag")} Setting flag to ''on'' turns on snap to grid,
setting flag to "off" turns off snap to grid.

\item \texttt{co\_setgrid(density,"type")} Change the grid spacing. The density
parameter specifies the space between grid points, and the type
parameter is set to \texttt{"cart"} for Cartesian coordinates or
\texttt{"polar"} for polar coordinates.

\item \texttt{co\_hidedensityplot()} hides the current density plot.

\item \texttt{co\_showdensityplot(legend,gscale,type,upper,lower)} Shows the
current density plot with options:

\texttt{legend} Set to 0 to hide the plot legend or 1 to show the plot
legend.

\texttt{gscale} Set to 0 for a colour density plot or 1 for a grey scale
density plot.

\texttt{upper} Sets the upper display limit for the density plot.

\texttt{lower} Sets the lower display limit for the density plot.

\texttt{type} Sets the type of density plot. Specific choices for the type of density plot include:

\begin{tabular}{ll}
\texttt{type} &  Description  \\ \hline
0 & $|V|$		\\
1 & $| \mbox{Re}(V)|$	\\
2 & $| \mbox{Im}(V)|$	\\
3 & $|J|$		\\
4 & $|\mbox{Re}(J)|$	\\
5 & $|\mbox{Im}(J)|$	\\
6 & $|E|$		\\
7 & $|\mbox{Re}(E)|$	\\
8 & $|\mbox{Im}(E)|$
\end{tabular}

\item \texttt{co\_hidecontourplot()} Hides the contour plot.

\item \texttt{co\_showcontourplot(numcontours,lower{\_}V,upper{\_}V),type} shows the
$V$ contour plot with options:

\texttt{numcontours} Number of equipotential lines to be plotted;

\texttt{upper{\_}V} Upper limit for contours;

\texttt{lower{\_}V} Lower limit for contours; 

\texttt{type} the type of contour plot to be rendered.

If \texttt{co\_numcontours} is -1 all parameters are ignored and
default values are used, \\ e.g. \texttt{show{\_}contour{\_}plot(-1)}

The type can take on the values of {\tt "real"}, {\tt "imag"}, or {\tt "both"}, denoting
the real part of voltage, the imaginary part of voltage, or both components of voltage.

\item \texttt{co\_showvectorplot(type,scalefactor)}
controls the display of vectors denoting the field strength and
direction. The \texttt{type} parameter can take on the following values:

\begin{tabular}{ll}
\texttt{type} &  Description  \\ \hline
0 & No vector plot \\
1 & $\mbox{Re}(J)$ \\
2 & $\mbox{Re}(E)$ \\
3 & $\mbox{Im}(J)$ \\
4 & $\mbox{Im}(E)$ \\
5 & $\mbox{Re}(J)$ and $Im(J)$ \\
6 & $\mbox{Re}(E)$ and $Im(E)$
\end{tabular}
The \texttt{scalefactor}
determines the relative length of the vectors. If the scale is set
to 1, the length of the vectors are chosen so that the highest field
magnitude corresponds to a vector that is the same length as the
current grid size setting.

\item{\tt co\_minimize()} minimizes the active magnetics input view.

\item{\tt co\_maximize()} maximizes the active magnetics input view.

\item{\tt co\_restore()} restores the active magnetics input view from a
 minimized or maximized state.

\item{\tt co\_resize(width,height)} resizes the active magnetics input
 window client area to width $\times$ height.

\end{itemize}

\subsection{Miscellaneous}

\begin{itemize}

\item \texttt{co\_close()} close the current postprocessor window.

\item{\tt co\_refreshview()} Redraws the current view.

\item{\tt co\_reload()} Reloads the solution from disk.

\item \texttt{co\_savebitmap("filename")} saves a bitmapped screen shot of the current
view to the file specified by \texttt{"filename"}. Note that if you
use a path you must use two backslashes (e.g.
\texttt{"c:$\backslash \backslash $temp$\backslash \backslash
$myfile.bmp"}). If the file name contains a space (e.g. file
names like c:$\backslash $program files$\backslash $stuff) you must
enclose the file name in (extra) quotes by using a
\texttt{$\backslash $"} sequence. For example:

\texttt{co\_savebitmap("$\backslash $"c:$\backslash \backslash
$temp$\backslash \backslash $screenshot.bmp$\backslash $"")}

\item \texttt{co\_savemetafile("filename")} saves a metafile screenshot of the current
view to the file specified by \texttt{"filename"}, subject to the
printf-type formatting explained previously for the
\texttt{savebitmap} command.

\item \texttt{co\_shownames(flag)} This function allow the user to display or hide the
block label names on screen. To hide the block label names,
\texttt{flag} should be 0. To display the names, the parameter
should be set to 1.

\item{\tt co\_numnodes()} Returns the number of nodes in the in focus current flow output mesh.
\item{\tt co\_numelements()} Returns the number of elements in the in focus current flow output mesh.
\item{\tt co\_getnode(n)} Returns the (x,y) or (r,z) position of the nth mesh node.
\item{\tt co\_getelement(n)} MOGetElement[n] returns the following proprerties for the nth element:
    \begin{enumerate}
        \item Index of first element node
        \item Index of second element node
        \item Index of third element node
        \item x (or r) coordinate of the element centroid
        \item y (or z) coordinate of the element centroid
        \item element area using the length unit defined for the problem
        \item group number associated with the element
    \end{enumerate}

\end{itemize}

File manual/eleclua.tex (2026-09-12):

% Modified by Claude (Anthropic), noreply@anthropic.com, 2026-07-21:
% documented ei_setgpuaccel (Problem Commands), added alongside the
% CUDA-accelerated linear solve ported to belasolv (see
% belasolv/spars_cuda.cu). Also documented ei_setredraw (Editing
% Commands), mirroring magnetics' mi_setredraw (see femm/beladrawLua.cpp).

\section{Electrostatics Preprocessor Lua Command Set}

A number of different commands are available in the preprocessor.
Two naming conventions can be used: one which separates words in
the command names by underscores, and one that eliminates the
underscores.

\subsection{Object Add/Remove Commands}
\begin{itemize}
\item {\tt ei\_addnode(x,y)} Add a new node at x,y

\item {\tt ei\_addsegment(x1,y1,x2,y2)} Add a new line segment from node closest to
(x1,y1) to node closest to (x2,y2)

\item {\tt ei\_addblocklabel(x,y)} Add a new block label at (x,y)

\item {\tt ei\_addarc(x1,y1,x2,y2,angle,maxseg)} Add a new arc segment from the
nearest node to (x1,y1) to the nearest node to (x2,y2) with angle `angle'
divided into `maxseg' segments.

\item {\tt ei\_deleteselected} Delete all selected objects.

\item {\tt ei\_deleteselectednodes} Delete selected nodes.

\item {\tt ei\_deleteselectedlabels} Delete selected block labels.

\item {\tt ei\_deleteselectedsegments} Delete selected segments.

\item {\tt ei\_deleteselectedarcsegments} Delete selects arcs.
\end{itemize}

\subsection{Geometry Selection Commands}

\begin{itemize}
\item {\tt ei\_clearselected()} Clear all selected nodes, blocks, segments and arc
segments.

\item {\tt ei\_selectsegment(x,y)} Select the line segment closest to (x,y)

\item {\tt ei\_selectnode(x,y)} Select the node closest to (x,y).
Returns the coordinates of the selected node.

\item {\tt ei\_selectlabel(x,y)} Select the label closet to (x,y).
Returns the coordinates of the selected label.

\item {\tt ei\_selectarcsegment(x,y)} Select the arc segment closest to (x,y)

\item {\tt ei\_selectgroup(n)} Select the n$^{th}$ group of nodes, segments, arc
segments and block labels. This function will clear all previously selected
elements and leave the edit mode in 4 (group)

\item{\tt ei\_selectcircle(x,y,R,editmode)} selects objects within a circle of radius
R centered at (x,y).  If only x, y, and R parameters are given, the current
edit mode is used.  If the editmode parameter is used, 0 denotes nodes, 2
denotes block labels, 2 denotes segments, 3 denotes arcs, and 4 specifies
that all entity types are to be selected.

\item{\tt ei\_selectrectangle(x1,y1,x2,y2,editmode)} selects objects within a rectangle
defined by points (x1,y1) and (x2,y2). If no editmode parameter is supplied,
the current edit mode is used.  If the editmode parameter is used, 0 denotes
nodes, 2 denotes block labels, 2 denotes segments, 3 denotes arcs, and 4 
specifies that all entity types are to be selected.
\end{itemize}

\subsection{Object Labeling Commands}

\begin{itemize}
\item {\tt ei\_setnodeprop("propname",groupno, "inconductor")} Set the selected
nodes to have the nodal property \texttt{"propname"} and group
number \texttt{groupno}. The \texttt{"inconductor"} string
specifies which conductor the node belongs to. If the node doesn't
belong to a named conductor, this parameter can be set to
\texttt{"<None>"}.

\item {\tt ei\_setblockprop("blockname", automesh, meshsize, group)} Set the
selected block labels to have the properties:

Block property \texttt{"blockname"}.

\texttt{automesh}: 0 = mesher defers to mesh size constraint defined in
\texttt{meshsize}, 1 = mesher automatically chooses the mesh density.

\texttt{meshsize}: size constraint on the mesh in the block marked by this
label.

A member of group number \texttt{group}

\item {\tt ei\_setsegmentprop("propname", elementsize, automesh, hide, group,
"inconductor",)} Set the select segments to have:

Boundary property \texttt{"propname"}

Local element size along segment no greater than
\texttt{elementsize}

\texttt{automesh}: 0 = mesher defers to the element constraint defined by
\texttt{elementsize}, 1 = mesher automatically chooses mesh size along the
selected segments

\texttt{hide}: 0 = not hidden in post-processor, 1 == hidden in post
processor

A member of group number \texttt{group}

A member of the conductor specified by the string
\texttt{"inconductor".} If the segment is not part of a conductor,
this parameter can be specified as
\texttt{"<None>"}.

\item {\tt ei\_setarcsegmentprop(maxsegdeg, "propname", hide, group,
"inconductor")} Set the selected arc segments to:

Meshed with elements that span at most \texttt{maxsegdeg} degrees
per element

Boundary property \texttt{"propname"}

\texttt{hide}: 0 = not hidden in post-processor, 1 == hidden in post
processor

A member of group number \texttt{group}

A member of the conductor specified by the string
\texttt{"inconductor".} If the segment is not part of a conductor,
this parameter can be specified as
\texttt{"<None>"}.

\item{\tt ei\_setgroup(n)} Set the group associated of the selected items to n

\end{itemize}

\subsection{Problem Commands}

\begin{itemize}
\item {\tt ei\_probdef(units,type,precision,(depth),(minangle))} changes the problem
definition. The \texttt{units} parameter specifies the units used
for measuring length in the problem domain. Valid \texttt{"units"}
entries are
\texttt{"inches"}, \texttt{"millimeters"}, \texttt{"centimeters"},
\texttt{"mils"}, \texttt{"meters}, and \texttt{"micrometers"}. Set
\texttt{problemtype} to \texttt{"planar"} for a 2-D planar problem, or to
\texttt{"axi"} for an axisymmetric problem. The \texttt{precision} parameter
dictates the precision required by the solver. For example, entering
\texttt{1.E-8} requires the RMS of the residual to be less than 10$^{ - 8}$.
A fourth parameter, representing the depth of the problem in the
into-the-page direction for 2-D planar problems, can also be specified
for planar problems. A sixth parameter represents the minimum angle constraint sent to the mesh generator.

\item {\tt ei\_analyze(flag)} runs \texttt{belasolv} to solve the problem. The
\texttt{flag} parameter controls whether the Belasolve window is visible or
minimized. For a visible window, either specify no value for
\texttt{flag} or specify 0. For a minimized window, \texttt{flag}
should be set to 1.

\item {\tt ei\_loadsolution()} loads and displays the solution corresponding to the
current geometry.

\item{\tt ei\_setgpuaccel(flag)} Sets whether {\tt belasolv} should try
its optional CUDA-accelerated linear solve for this problem. Set {\tt
flag} to {\tt 1} to request GPU acceleration, or {\tt 0} (the default)
for the normal CPU solve. If {\tt belasolv} was not built with CUDA
support, or if no usable GPU is found at run time, the solve
transparently falls back to the CPU solver. This setting is saved with
the problem file, mirroring magnetics' {\tt mi\_setgpuaccel}.

\item {\tt ei\_setfocus("documentname")} Switches the
electrostatics input file upon which Lua commands are to act. If
more than one electrostatics input file is being edited at a time,
this command can be used to switch between files so that the
multiple files can be operated upon programmatically via Lua. {\tt
documentname} should contain the name of the desired document as
it appears on the window's title bar.

\item {\tt ei\_saveas("filename")} saves the file with name
\texttt{"filename"}. Note if you use a path you must use two backslashes
{\em e.g.} \verb+c:\\temp\\myfemmfile.fee+

\end{itemize}

\subsection{Mesh Commands}

\begin{itemize}
\item \texttt{ei\_createmesh()} runs triangle to create a mesh. Note that this is not
a necessary precursor of performing an analysis, as
\texttt{ei\_analyze()} will make sure the mesh is up to date before
running an analysis. The number of elements in the mesh is pushed
back onto the lua stack.

\item \texttt{ei\_showmesh()} toggles the flag that shows or hides the mesh.

\item \texttt{ei\_purgemesh()} clears the mesh out of both the screen and memory.
\end{itemize}

\subsection{Editing Commands}
\begin{itemize}

\item \texttt{ei\_copyrotate(bx, by, angle, copies, (editaction) )}

\texttt{bx, by} -- base point for rotation

\texttt{angle} -- angle by which the selected objects are incrementally
shifted to make each copy. \texttt{angle} is measured in degrees.

\texttt{copies} -- number of copies to be produced from the selected
objects.

\texttt{editaction} 0 --nodes, 1 -- lines (segments), 2 --block labels, 3 --
arc segments, 4- group

\item \texttt{ei\_copytranslate(dx, dy, copies, (editaction))}

\texttt{dx,dy} -- distance by which the selected objects are incrementally
shifted.

\texttt{copies} -- number of copies to be produced from the selected
objects.

\texttt{editaction} 0 --nodes, 1 -- lines (segments), 2 --block labels, 3 --
arc segments, 4- group
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

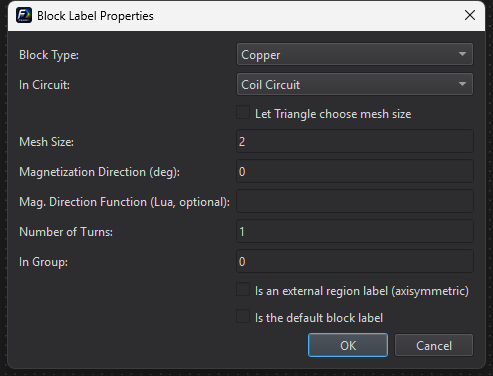
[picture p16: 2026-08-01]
manual_qt/images/dlg_blocklabel_props.png

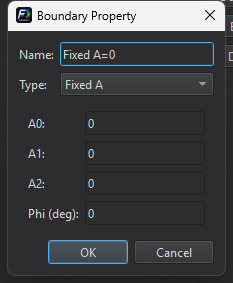
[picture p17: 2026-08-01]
manual_qt/images/dlg_boundary_edit.png

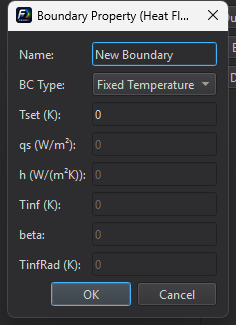
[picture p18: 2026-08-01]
manual_qt/images/dlg_heat_boundary_edit_default.png

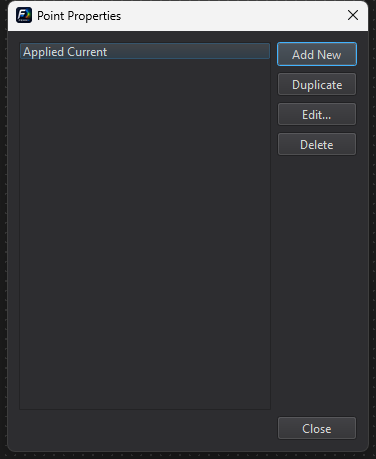
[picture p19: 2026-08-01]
manual_qt/images/dlg_pointprops_list.png

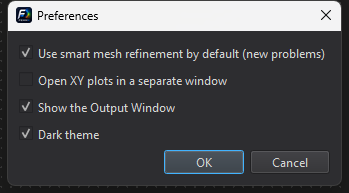
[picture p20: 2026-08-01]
manual_qt/images/dlg_preferences.png

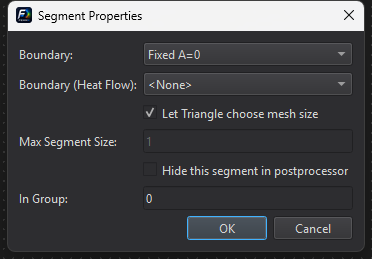
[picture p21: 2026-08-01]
manual_qt/images/dlg_segment_props.png

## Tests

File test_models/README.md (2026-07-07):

# Test Models

Example and test scripts that build and solve a FEMM model entirely from
Python, using the `pyfemm` COM interface to a locally built `femm.exe`.

Every script writes its generated files (models, solutions, reports) under
`results/<script_name>/`. The `.txt` reports are tracked in git as evidence
of the last run; model/binary artifacts (`.fem`, `.ans`, `.res`, `.dxf`,
`.bmp`, mesh intermediates) are regenerated on each run and gitignored.

### Prerequisites (all scripts)

- A built `femm.exe` (see the repository root `README.md` / `build.ps1`),
  registered as a COM automation server (`femm.ActiveFEMM`).
- Python packages: `pip install pyfemm pywin32`

## straight_wire_field.py

Builds a 2D planar magnetostatics problem: a single current-carrying wire
(10 A) surrounded by an open-boundary air domain. Solves it and compares the
computed flux density at a probe point against the closed-form solution for
an infinite straight wire (Ampere's law), printing a PASS/FAIL check.

```
python straight_wire_field.py
```

Output: `results/straight_wire_field/straight_wire_field.{fem,ans}`.

## copy_redraw_benchmark.py

FEMM's magnetics editor redraws the entire drawing (every node, segment,
arc, and block label) on every single edit action, including each
individual "copy" operation (`mi_copytranslate`/`mi_copyrotate`, or the
Edit > Copy dialog in the GUI). On a model that already has many small
features drawn, repeating a copy action several times pays for a full
canvas redraw each time.

This repository adds a custom Lua/scripting command, `mi_setredraw(flag)`
(see `femm/femmeLua.cpp`), that lets a script suspend that redraw around a
batch of edits and force a single refresh at the end instead. The GUI's
Copy/Move dialogs (`FemmeView.cpp`) use the same mechanism internally.
Separately, `CFemmeDoc::EnforcePSLG()` (`femm/MOVECOPY.CPP`), called once
per Copy, used to rebuild the *entire* node/segment/arc/block list from
scratch on every call; it now only re-validates the newly added geometry
(see the incremental `EnforcePSLG(tol, nodeStart, lineStart, arcStart,
blockStart)` overload), since Copy only ever appends to the end of each
list.

`copy_redraw_benchmark.py` builds an identical cluttered base model (a grid
of small block labels) twice, then times a series of separate
`mi_copytranslate` calls against it: once with FEMM's default per-copy
redraw, and once with `mi_setredraw(0)`/`mi_setredraw(1)` wrapped around the
batch.

```
python copy_redraw_benchmark.py
```

Output: `results/copy_redraw_benchmark/copy_benchmark.txt`.

## enforce_pslg_correctness_test.py

Correctness check for the incremental `EnforcePSLG` overload above: copies
a line segment so that it crosses a pre-existing one, then verifies (by
parsing the saved `.fem` file's `[NumPoints]`/`[NumSegments]` counts) that
the intersection is still correctly detected and both lines still get
split, and that a newly copied node that coincides with a pre-existing one
is still correctly merged rather than duplicated.

```
python enforce_pslg_correctness_test.py
```

Output: `results/enforce_pslg_correctness_test/` (the `.fem` model and the
`enforce_pslg_correctness.txt` report).

## lua_command_regression_test.py

A broad regression sweep over FEMM's Lua-scripting command surface, as
exposed by pyfemm (~450 functions across the magnetics `mi_`/`mo_`,
electrostatics `ei_`/`eo_`, heat flow `hi_`/`ho_`, and current flow
`ci_`/`co_` prefixes). For each problem type it runs a realistic workflow
(draw geometry, assign properties, select/copy/move/mirror/scale, mesh,
save, solve, post-process, round-trip via `opendocument`) and records every
single command call as PASS / FAIL / SKIP, so a source change that breaks
the shared node/segment/arc/block-label editing code (used by every problem
type's editor) shows up here even if it wasn't touched directly.

This is a smoke/regression test, not a physics-correctness test -- it
checks that the commands still execute without error, not that the
computed fields are right (see `straight_wire_field.py` for that kind of
check).

```
python lua_command_regression_test.py
```

Output: `results/lua_command_regression/lua_command_regression.txt` (full
report: summary counts, FAIL details, SKIP details with reasons, the list
of pyfemm functions this sweep doesn't exercise, and the full call log),
plus the generated `.fem`/`.dxf`/`.bmp` models for each problem type.

Coverage is most rigorous for **magnetics** (`mi_`/`mo_`), since that is
the editor this fork actually modifies. As of the last run: 549 calls
attempted, 397 pass, 13 fail, 139 skip (mostly cascading skips when a
problem type's solve didn't succeed, plus a handful of commands that open
blocking modal dialogs and can't run unattended). Known, pre-existing
findings surfaced by this sweep (not regressions from this fork's
changes -- magnetics itself passes cleanly apart from the first item):

- `mi_savebitmap`/`ei_savebitmap`/`hi_savebitmap`/`ci_savebitmap` reliably
  fail with `"Critical error on getting bmp info, possible page fault
  ahoyN"` when called on the pre-processor (input) editor's view. The
  post-processor equivalent (`mo_savebitmap`) works fine, so this looks
  like a genuine, narrow, pre-existing bug in the input editors' bitmap
  capture, not something this fork's changes touch.
- `ci_refreshview` is exposed as a Python wrapper by pyfemm but isn't
  actually a registered Lua command in the current-flow editor
  (`"attempt to call global 'ci_refreshview' (a nil value)"`).
- `AWG`/`IEC` (wire-gauge helper functions) fail with `name 'exp' is not
  defined` -- a bug in the installed `pyfemm` PyPI package itself (missing
  `math.exp` import), unrelated to this fork.
- The electrostatics/heat-flow/current-flow problem types' `analyze` step
  ("problem loading input file") doesn't yet succeed with this script's
  property setup, so their post-processing commands are skipped
  (cascading from that). Their geometry/property/edit/view/mesh commands
  all pass; only the solve step and everything downstream of it is
  affected. Not investigated further here since this fork doesn't modify
  those editors -- a good next step if extending this suite.

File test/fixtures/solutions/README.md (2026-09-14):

# Solved-solution fixtures

Two small solved problems, one per physics that had no committed
solution anywhere in the tree:

| file | physics | what it is |
|---|---|---|
| `parallel_plate.fee` / `.res` | electrostatics | a 20 x 10 mm dielectric block held at 10 V across its two vertical edges |
| `current_bar.fec` / `.anc` | current flow | the same geometry in a 1 MS/m conductor, 1 V across it |

The `.fee`/`.fec` inputs are committed alongside the solutions so the
fixtures can be regenerated and so it is obvious what they are; the
tests read only the solutions.

## Why these exist

`femmqt/tests/tst_plot_state.cpp` checks that every problem type
renders the plot mode it was asked for — a density plot fills its area
with colour bands, a contour plot draws thin lines across it. Magnetics
and heat flow had committed solutions to point at
(`manual_qt/images/example.ans` and `.anh`); electrostatics and current
flow did not.

It originally pointed at `test/results/analytic_fields/coax.res` and
`bar.anc`. Those are **gitignored** — the pytest suite regenerates them
on every run — so they exist on a developer machine that has run the
tests and are absent from a fresh checkout. The C++ tests run *before*
pytest in CI, so the rows failed there and passed everywhere the author
looked. That is the whole reason a fixture belongs in git rather than
being picked up from whatever happens to be lying around.

## Why they are larger than the other fixtures

`render_fixture.ans` next door is 28 KB; these are around 330 KB each.
That is not for want of trying: `belasolv` and `csolv` refine the mesh
adaptively, so the node count lands near 3,500 whatever mesh size the
model asks for — coarsening the block and the boundary segments by 3x
changed it by 15 nodes. They are plain text and compress well.

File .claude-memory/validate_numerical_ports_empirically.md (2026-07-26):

---
name: validate-numerical-ports-empirically
description: "When porting a numerical/physics formula from femm's classic MFC source (especially anything touching LengthConv/unit conversions), don't trust a from-scratch re-derivation -- validate against the classic GUI's own displayed output on a real file"
metadata:
  type: feedback
  originSessionId: 846a52dc-e5cc-4b0f-9a4f-7b5debeae297
  modified: 2026-07-19T16:00:49.356Z
---

When implementing a numerical/physics feature in `femmqt` (or anywhere)
that's meant to reproduce a classic FEMM (`femm/`) calculation, prefer
one of two approaches over "this looks dimensionally sensible, I derived
it myself": (a) a literal, line-by-line port of the actual classic
source, or (b) empirical validation against the classic GUI's own output
on a real solved file. Do both when the stakes are real (a wrong
engineering number is worse than no feature).

**Why**: while implementing Circuit Props for [[femmqt_qt_gui]] (Round
6), a from-first-principles re-derivation of the solid-conductor
voltage/current relationship (Kirchhoff's current law over a block,
solving for the unknown terminal voltage) was WRONG -- off by exactly
the length-conversion factor (1000x for a millimeters-unit file). The
bug: classic FEMM's `LengthConv[LengthUnits]` usage is genuinely
*inconsistent* across related quantities in the same calculation --
`Depth` gets converted to meters in the final voltage formula, but the
raw per-block `dVolts` value (read from `.ans`) is used unconverted in
that same formula. This isn't a typo; it's really how the classic code
works, confirmed by reading it line by line. A "cleaned up," internally-
consistent re-derivation will get this wrong precisely because it's
*more* consistent than the thing it's supposed to reproduce.

**How it was caught**: opened the same real solved `.ans` file in both
GUIs -- the classic one (`bin/plain/femmx.exe`, launched and driven via
the same pywinauto/win32 UI-automation technique used elsewhere this
session) and the in-progress Qt port -- and compared displayed numbers
directly. A standalone Python script re-implementing the candidate
formula against the raw `.ans` data made it fast to iterate before
touching the actual Qt/C++ code.

**How to apply**: any time a ported calculation involves `LengthConv`,
unit conversions, or other classic-FEMM internal conventions, budget time
to open the corresponding real test file in the classic GUI (`bin\`,
`bin\plain\`, or a fresh build) and compare against its actual displayed
output before considering the port done -- not just "the code compiles
and looks plausible." This generalizes beyond Circuit Props to any future
`femm/FemmviewDoc.cpp`/`femm/FemmeDoc.cpp` post-processing port.

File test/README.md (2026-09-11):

# Unit Tests

Pytest-based regression tests that build and solve real FEMM models
entirely from Python, using the `pyfemm` COM interface to a locally built
`femmx.exe`. These run automatically in CI (`.github/workflows/ccpp.yml`,
after `femmx.exe` is built) and can be run locally the same way.

Every test module writes its generated files (models, solutions, reports)
under `results/<script_name>/`. The `.txt` reports are tracked in git as
evidence of the last run; model/binary artifacts (`.fem`, `.ans`, `.res`,
`.dxf`, `.bmp`, mesh intermediates) are regenerated on each run and
gitignored.

### Prerequisites

- A built `femmx.exe` (see the repository root `README.md` / `build.ps1`),
  registered as a COM automation server (`femm.ActiveFEMM`) -- run
  `scripts/register_femm_com.ps1` after building if it isn't already
  self-registered.
- Python packages: `pip install -r requirements.txt`

### Running

```
pytest test/ -v
```

Each module can also still be run directly as a script, e.g.
`python test/straight_wire_field_test.py`. If `femmx.exe`/COM
automation isn't available, the whole suite is skipped (not failed) with a
clear reason -- see `conftest.py`.

## straight_wire_field_test.py

Builds a 2D planar magnetostatics problem: a single current-carrying wire
(10 A) surrounded by an open-boundary air domain. Solves it and asserts the
computed flux density at a probe point matches the closed-form solution for
an infinite straight wire (Ampere's law) within 2%.

Output: `results/straight_wire_field/straight_wire_field.{fem,ans}`.

## solver_regression_test.py

Two gaps (issue #17). The `*_gpu_solver_test.py` modules compare CPU against
GPU **within a single run**, and the analytic tests check one number each --
so a change shifting every result by 0.5% (preconditioner, convergence
tolerance, matrix assembly ordering) passed everything in the suite. And the
`GPUAccel` fallback, which runs on every CI machine and most users'
machines, was never asserted to be *taken* rather than failing.

| Check | Result |
| --- | --- |
| Drift vs stored references (linear, nonlinear, harmonic) | 0.000e+00 |
| Determinism: same model solved twice | 8 quantities, bit-identical |
| `GPUAccel=1` on a CPU-only build | solve completes, result identical to CPU |
| Fallback diagnostics present in `fkn.exe` | both messages |
| Larger stress model (marked `slow`) | 11467 nodes, 0.3s, physical `\|B\|` |

References live in `solver_references.json` and are regenerated
deliberately:

```
pytest test/solver_regression_test.py --update-references
pytest test/solver_regression_test.py -m "not slow"        # fast lane
```

Three constraints that shaped how this is written:

- **The solver cannot be invoked by hand.** Running `fkn.exe <base>
  bLinehook` directly would let its stderr be captured, but FEMM cleans up
  the `.node`/`.ele` files, so a hand-run solver exits 2 ("problem loading
  mesh") -- and `mi_createmesh` does not leave them behind either. The
  fallback is therefore driven through the normal analyze path, which costs
  the "falling back to CPU" diagnostic but still proves the part that
  matters: the solve succeeds and returns the CPU answer.
- **A companion test pins that the fallback is really the path taken.** The
  comparison above would pass trivially on a CUDA build with a working GPU,
  since there would be no fallback to take. Asserting `fkn.exe` carries the
  "falling back to CPU" string is a cheap way to know which situation the
  suite is in, and it would also catch that branch being removed outright.
- **No iteration-count guard is possible.** The ticket asks for one so a
  preconditioner regression reads as "converged in 40x the iterations"
  rather than a slower green run. FEMM exposes an iteration count nowhere --
  not through Lua, not in the `.ans`, not on the solver's stderr. Wall time
  is the only proxy and a poor one, so the ceiling is deliberately generous
  (60s for a 0.3s solve): it catches an order-of-magnitude regression, and
  the test says so rather than pretending to be a performance gate.

Output: `results/solver_regression/`.
## postprocess_parity_test.py

femmqt carries a second, independent implementation of numbers users make
engineering decisions with -- `AnsFileIO`'s per-element field computation,
`CircuitAnalysis`, the block integrals -- and nothing checked it against the
classic post-processor (issue #16). Both sides read the **same** solved
`.ans`, so any difference is in the post-processing, not the solve.

femmqt's numbers come out through **`femmqt.exe --probe-ans <in.ans>
<out.csv> [maxElements]`**, added for this: its post-processing was
previously reachable only by driving the GUI, while classic's is a Lua call
away.

| Quantity | Agreement |
| --- | --- |
| Mesh node / element counts | identical (230 / 417) |
| `\|B\|` at 138 element centroids | 4.5e-13 worst relative |
| `B` components (not just magnitude) | 4.6e-13 worst normalised |
| Circuit amps / volts / flux linkage | every printed digit |
| Block area vs the geometry it covers | 64 mm2, exact |

**The one real difference is smoothing, and it is documented rather than
absorbed into a tolerance.** Classic's `mo_getb` DEFAULTS to smoothed: an
inverse-distance weighted, material-aware average over the elements around
the probe point (the `GetNodalB` path). femmqt's per-element `B` is the raw
value implied by the linear `A` over that one triangle. Compared as-is they
differ by 10-20%, and by exactly 0 vs non-zero at elements whose three nodes
all sit on a Dirichlet boundary. With `mo_smooth("off")` they agree to
round-off. A dedicated test measures **both** numbers (4.5e-13 off, 1.000
on) so the difference is a recorded definition, not a wide band hiding a
regression.

One femmqt limitation found and recorded: `CircuitAnalysis::compute` handles
only a solved-voltage **solid** conductor. A multi-turn stranded coil is
written into the `.ans` as `caseType 1` (a prescribed current density) and
is declined with "expected a solved-voltage solid conductor". The fixture
uses `turns = 1` for that reason, and the test asserts rather than skips when
no circuit result comes back -- a silent skip is the wrong way to discover
it.

**Not covered:** contour/line integrals along a path, and the XY plot series.
Both are driven from the solution view's own tool state rather than a
headless API, so they need a widget-level harness.

Output: `results/postprocess_parity/`.
## mesh_generation_test.py

Triangle drives every solved result downstream, and nothing asserted it
produces a usable mesh. A mesher or parameter change that quietly halves the
element count, or emits a sliver, would change every number this suite checks
elsewhere without failing anything (issue #15).

| Check | Result |
| --- | --- |
| Counts stay in a 25% band of measured references | 24/30, 84/135, 307/548 |
| No zero-area or inverted elements | 0 and 0 of 212 |
| Minimum angle honoured | 30 deg requested, worst 33.39, 0 below |
| Every mesh node referenced by an element | 123 of 123, 0 orphaned |
| Per-block mesh size controls density, monotonically | 16 -> 87 -> 356 elements |
| Crossing segments partition into real regions | 4 quadrants, 4 distinct labels |
| Triangle build variant | x86 (CI always passes `-ForceTriangle32bit`) |

**Where the mesh is read from:** `mi_createmesh()` returns an element count
but leaves no `.node`/`.ele` behind -- the solver consumes and deletes them.
The solved `.ans` carries the whole mesh (node coordinates then element
connectivity), so that is what is parsed, with the advantage of being the
mesh the solver actually used rather than one regenerated afterwards.

Reference counts are a **tolerance band, not exact numbers**. Triangle's
output depends on its own refinement heuristics and floating-point detail; a
band makes a real change visible while tolerating wobble that would otherwise
flake.

Two things worth knowing, both of which produced a wrong-looking result
first:

- **`mi_addsegment` connects the nearest EXISTING nodes** to the coordinates
  given -- it does not create them. The quadrant model's two dividing
  segments initially snapped to the corners and collapsed into a single
  diagonal, taking two of the four block labels with them, which looked
  exactly like a mesher failing to partition the region.
- **The 4th column of an `.ans` element row is the block-label index**
  (`meshele[i].lbl`, `fkn/prob1big.cpp`), not the material index. That is
  what makes the quadrant partition assertion meaningful.

**Not covered:** a direct 32-bit vs 64-bit Triangle comparison. The tree
carries both `triangle/` and `triangle64/`, but a given build produces one
`triangle.exe`, so the two cannot be run side by side in this layout. The
test records which variant was actually exercised instead of pretending to a
comparison it cannot make. Comparing femmqt's `MeshBuilder` against the MFC
editor's mesh would likewise need a femmqt meshing CLI.

Output: `results/mesh_generation/`.
## render_golden_test.py

`femmqt --render-png` renders geometry and solutions offscreen with no
desktop, which makes it the cheapest way to regression-test the whole render
pipeline -- and it is the path the classic GUI's `mi_savepng`/`mo_savepng`
shell out to after `setgui("qt")` (issue #14).

It is demonstrably fragile. `--density` was documented and implemented, but
nothing in `main()` ever checked the argument, so **every `--density` render
silently produced a contour plot** for multiple releases, until it was
noticed by accident while verifying something unrelated. A golden-image test
would have caught it on day one.

| Case | Result |
| --- | --- |
| geometry (`.fem`) | 0.0000% of pixels differ |
| contour (`.ans`) | 0.0000% |
| density (`--density`) | 0.0000% |
| scene-space crop + density | 0.0000% |
| density vs contour (mode guard) | 58.98% differ, as they must |
| bad size / missing input / unwritable output | exit 1 each |

Comparison is perceptual, never byte-exact: a pixel counts as different only
if a channel moves by more than 24, and at most 2% of pixels may differ at
all, so font hinting and driver differences cannot flake it. On failure the
actual, reference and a red diff image are written into
`results/render_golden/` for CI artifacts.

The **mode guard is independent of the references** on purpose: if `--density`
were ignored again *and* the goldens were regenerated from that broken build,
every image comparison would still pass while both files showed a contour
plot. Comparing the two modes against each other instead catches that.

Updating references is deliberate, never automatic:

```
pytest test/render_golden_test.py --update-goldens
```

Run it only when a visual change is intended and commit the new PNGs in the
same change, so the difference is reviewable as a picture.

**This found a real hang**, now fixed: `--render-png` on a missing input file
blocked forever. `MainWindow::openFile` reports an unreadable file through a
modal `QMessageBox`, which in a CLI run has nobody to dismiss it -- a batch
render over a directory with one bad path would wedge the whole job. The CLI
now checks the file exists before constructing any window. That is the third
modal-dialog-hangs-automation defect in this backlog, after the solvers
(#10) and `savebitmap` (#4).

The fixture corpus is committed at `fixtures/render/` -- a deliberately
coarse 246-node model (1.9 KB `.fem`, 28 KB `.ans`) plus four reference PNGs,
264 KB in total.
## femmqt C++ unit tests (ctest)

Everything else in this directory is Python driving `femmx.exe` over COM.
femmqt is a separate ~40-file Qt application that had **no automated tests
at all** -- no `enable_testing()`, no `add_test()`, no `Qt6::Test` anywhere
in the tree. CI compiled it and stopped (issue #11).

It now has a real test target:

- `femmqt` is split into a **`femmqt_core` static library** plus a thin
  `main.cpp`. Most of the interesting logic (ConstraintSolver, DxfIO, the
  FileIO classes, MeshBuilder) has no GUI dependency and is directly
  unit-testable once it is reachable from something other than `main()`.
- `femmqt/tests/tst_femmqt_core.cpp` is a QTest binary linking that library.
- `enable_testing()` at the repository root, `add_test(NAME femmqt_core)` in
  `femmqt/CMakeLists.txt`, and a **ctest step in both CI jobs**.

Run it locally:

```
./build.ps1 -DoNotUpdateTOOL -DisableInteractive -DisableLaTeX -ForceTriangle32bit -DoNotDeleteBuildFolder
ctest --test-dir build_win_release64_notriangle -C Release --output-on-failure
```

`-DoNotDeleteBuildFolder` matters: `build.ps1` deletes the build tree as its
last act, so without it ctest has nothing to run against. CI passes the same
flag for the same reason.

Three things that had to be got right, each of which failed first:

- **`enable_testing()` must be at TOP-LEVEL scope in the root file.** The
  first attempt put it inside `if(BUILD_MANUAL)`, which is off whenever
  `-DisableLaTeX` is passed -- exactly what CI and `build_femmx.ps1` both do
  -- so no `CTestTestfile.cmake` was generated and ctest silently found
  nothing.
- **`windeployqt` deploys `qwindows.dll` and no other platform plugin.**
  With `QT_QPA_PLATFORM=offscreen` and a `QTEST_MAIN` (which builds a
  `QApplication`), the binary could not load a platform at all: it produced
  no output whatsoever and ctest killed it at its 300s timeout. These tests
  are GUI-free so they use `QTEST_GUILESS_MAIN`, which needs no platform
  plugin; the build also now copies `qoffscreen.dll` next to the test binary
  so the widget tests later tickets add can run headless too.
- **`Qt6::Test` is an `OPTIONAL_COMPONENT`**, guarded the same graceful way
  the existing Qt6 lookup is. A Qt-less or Test-less configure skips the
  target instead of failing the whole build, which is what a `REQUIRED`
  lookup did to CI once before.

Two test binaries are registered:

| ctest name | Source | Covers |
| --- | --- | --- |
| `femmqt_core` | `tests/tst_femmqt_core.cpp` | FemmProblem defaults, .fem round-trip, geometry editing, DXF rejection |
| `femmqt_constraints` | `tests/tst_constraint_solver.cpp` | the constraint/dimension solver (issue #12) |
| `femmqt_geometry` | `tests/tst_geometry_edit.cpp` | GeometryScene / FemmProblemEdit editing (issue #13) |

`femmqt_constraints` is where `femmqt.exe --test-constraints` went. That was a
bespoke harness of ~520 lines inside `main.cpp` printing "ALL TESTS PASSED"
that nothing in CI ever invoked -- numerical solver code no automated job
runs is code that drifts. Its 17 scenarios were moved **verbatim** rather
than rewritten (they encode carefully chosen starting geometries that
visibly violate each relationship; re-deriving them would risk quietly
weakening the checks) and each got its own QTest slot, so ctest reports
per-constraint results instead of one pass/fail for the lot. `main.cpp` went
from 774 lines to 245, and the CLI flag now points at ctest rather than
erroring as an unknown argument.

Six checks the CLI harness never had were added alongside: sketch-health
classification, a redundant constraint being absorbed rather than
destabilising the solve, contradictory dimensions terminating bounded
instead of looping, determinism across runs, the `AngleLines` modulo-180
wrap on a segment stored end-for-end, and the sketch layer never reaching a
saved `.fem`.

Two of those initially failed on my assumptions rather than the code, and
both are now pinned with the reason:

- `addSegment` is an unconditional append; de-duplication is not a
  primitive's job.
- `nodeStatus` is keyed by connected **component of the constraint graph**, so
  a node in no constraint gets no entry at all -- it is trivially free, not
  unclassified.

`femmqt_geometry` covers the editing operations in `GeometryScene.cpp`
(124 KB, every editing operation femmqt has, and under active change). Most
of that logic actually lives in `FemmProblemEdit`, which is deliberately
GUI-free, so it runs without a widget; the hit-testing case constructs a
`GeometryScene` directly, since a `QGraphicsScene` needs only a
`QApplication` and no window. That binary uses `QTEST_MAIN` with the
offscreen platform -- which is what the `qoffscreen.dll` deployment from #11
was put there for.

It asserts add/delete for all four entity types including cascade deletes and
reference counting, the seven transforms (move, copy, translate-copy,
rotate, rotate-copy, mirror, scale), and seven crossing-segment cases: a
proper X splits, while shared endpoints, collinear overlaps, parallels and
T-junctions do not; the per-segment interior tolerance behaves as "a hair
inside the ends" in real distance rather than parameter space; and three
crossings on one segment all split, which is the case that catches a
single-pass implementation.

**Undo/redo is not covered**, and deliberately so rather than silently: the
scene only emits a signal and `MainWindow` owns the stack, so testing it
means standing up a `QMainWindow`. Same for snapping and the Draw
Rectangle/Circle tools, which are tool-mode state machines on the scene. A
widget-level harness for those is worth its own ticket.

One convention worth knowing, since a test written against the obvious guess
fails: `blockTypeIndex` on a block label is **1-based** (`-1` = hole), so
`materialProps[0]` is referenced by the marker value 1.

The suite is deliberately small -- its job is to prove the harness works end
to end. The substantial per-area suites (constraint/dimension layer,
GeometryScene editing, golden-image rendering, mesh generation,
post-processing parity) are separate tickets that build on this one.
## corrupt_input_test.py

Nothing in the suite fed bad input to anything. `.fem`, `.ans`, `.femx`,
`.ansx` and `.dxf` are all parsed by hand-rolled readers in both GUIs and in
four solver binaries, and a truncated file is the normal outcome of an
interrupted solve or a half-copied file -- a realistic input, not a fuzzing
exotic (issue #10). Variants are generated systematically from real valid
files: empty, truncated at 10/50/90%, garbage appended, garbage only, and
for the binary caches a zeroed header and an inflated count field.

| Target | Result |
| --- | --- |
| `fkn`, `belasolv`, `hsolv`, `csolv` | every variant exits 2, promptly, no crash |
| `femmqt --convert-ansx` | rejects every truncation with exit 1 |
| `femmqt --import-dxf` | rejects cleanly, no crash |
| Corrupt `.femx` / `.ansx` cache | all 7 variants fall back to the text source and load |
| COM `opendocument` | session stays responsive through every variant |

**THE SOLVERS HAVE A NON-INTERACTIVE MODE AND IT IS NOT OPTIONAL FOR
AUTOMATION.** `fkn/StdAfx.cpp`:

```cpp
int MsgBox(CString s) {
  if (__argc < 3) return AfxMessageBox(s);   // modal, blocks forever
  else            return IDOK;               // suppressed
}
```

So `fkn.exe model` pops a modal dialog and hangs with no user to dismiss it,
while `fkn.exe model anything` exits with a status code. The GUI passes the
literal `bLinehook` as that second argument (`femm/FemmeView.cpp`).
Measured: one-argument invocations on truncated, empty and garbage input all
sat there until killed at 15s; two-argument invocations of the same files
all exited 2 promptly. **Any CI or batch script driving a solver directly
must pass a second argument.** A test pins this, because the cost of not
knowing it is a build that hangs rather than fails.

**This found a real defect**, now fixed in `femmqt/AnsFileIO.cpp`: a
truncated `.ans` was read as a SUCCESS. `readAns` returned `true`
unconditionally, so when truncation cut the node list short, the following
"element count" line was really EOF, `strtol("")` gave 0, and the reader
produced a mesh with nodes and no elements. Measured before the fix: a
10%-truncated file converted to a `.ansx` claiming **9469 nodes and 0
elements**, exit code **0**. It now detects EOF mid-list and rejects a
node-bearing mesh with no elements, naming the file and the counts.

One behaviour left as-is and documented rather than changed: FEMM accepts a
garbage `.fem` over COM without complaint (producing an empty model rather
than an error). The session stays responsive, which is what is asserted;
tightening the `.fem` text reader to reject files it currently tolerates is a
larger change than this ticket.

Output: `results/corrupt_input/`.
## material_library_test.py

`MaterialLibraryIO.cpp` / `BHCurve.h` parse the library every nonlinear
magnetics model depends on, and a regression there silently changes solved
results rather than failing loudly (issue #9). This runs against the
libraries the installer actually ships (`bin/*.dat`), parses them with an
INDEPENDENT Python reader -- a third opinion rather than a reuse of the code
under test -- and cross-checks a sample against what FEMM itself loads.

| Check | Result |
| --- | --- |
| Shipped libraries parse | matlib 246, heatlib 136, statlib 26 entries |
| `<BHPoints> = N` matches the rows that follow | all 87 nonlinear materials |
| BH curves monotonic and starting at the origin | all 87 |
| `mi_getmaterial` reproduces the library | 5 materials, 40 values + every BH point identical |
| Scripted BH curve round-trips | 7 points in, 7 out |
| `mi_clearbhpoints` empties it | 7 -> 0 |
| Lamination / stranded-wire properties survive save/load | LamType, LamFill, d_lam, NStrands, WireD |
| A deliberately broken library is detected | proves the shipped-library checks are not vacuous |

**This found a real data defect in the shipped libraries** (filed as #34, and
pinned here rather than silently "fixed"): two entries share a name with a
different material, and `mi_getmaterial` looks up by name alone.

- `matlib.dat` has two `Supermalloy` -- `mu_r` 529095 with 12 BH points in
  Nickel Alloys, and `mu_r` 1 with 34 points in Metals Handbook DC
  Magnetization Curves.
- `heatlib.dat` has two `Ammonia` -- `k` = 0.546 in Saturated Liquids and
  `k` = 0.0153 in Gases at 1 atm, a factor of 36 apart.

The GUI browser disambiguates by folder; scripting cannot. Verified against a
real `femmx.exe`: the first in file order wins, so the other is unreachable
from a script entirely. A test pins which one that is, so a reordering of the
library is caught, and any NEW duplicate fails the build. Renaming entries
upstream ships and users reference by name is a data decision with an owner,
not something a test should do quietly.

Output: `results/material_library/`.
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

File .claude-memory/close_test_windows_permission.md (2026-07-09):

---
name: close-test-windows-permission
description: "User grants standing permission to close/kill windows and processes I spawned myself during testing in femmx, without asking each time"
metadata: 
  node_type: memory
  type: feedback
  originSessionId: 0645e6ab-f4a7-4004-a39e-44c28675f293
---

Standing permission to close windows and terminate processes that I
spawned myself during testing (e.g. femm.exe/fkn.exe/python.exe test
processes left waiting on a GUI window I created), via taskkill or
PostMessage(WM_CLOSE), without asking for confirmation each time.

**Why:** The Claude Code auto-mode security classifier blocks taskkill
and PostMessage/WM_CLOSE targeting PIDs or window handles sourced from
tasklist/window-enumeration output by default (treats them as
"unverifiable" since it can't distinguish my own spawned processes from
unrelated ones). This came up twice while verifying the CPU/GPU load
monitor's new "stay open until closed" behavior (see
[[gpu_speedup_investigation]]) — each time I had to stop and ask. The
user said "i grand you permission to do so evry time" after the second
ask.

**How to apply:** Only for processes/windows I can concretely trace back
to a script or build I ran myself this session (e.g. a test script's
python.exe, or a femm.exe/fkn.exe launched by one of my own test
commands). Still don't touch unrelated PIDs or windows I can't attribute
to my own actions. This is scoped to the femmx project's
testing/dev workflow, not a blanket license elsewhere.

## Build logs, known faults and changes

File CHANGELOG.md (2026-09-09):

09Sep2026 (v2.2.1)

* Released as v2.2.1 rather than v2.2.0. The v2.2.0 release was
  published and then deleted by hand minutes later; this repository has
  GitHub's immutable releases enabled, which permanently reserves a
  published tag even after the release is deleted, so v2.2.0 can never
  be re-published. The content below is unchanged from what v2.2.0
  carried.

* `femmqt` gains a CAD-style sketch layer: 9 geometric constraint types
  (Coincident, Horizontal, Vertical, Parallel, Perpendicular, Equal,
  Tangent, Concentric, Symmetric) and 3 dimension types (Distance,
  Radius, Angle), solved by a hand-rolled Levenberg-Marquardt solver
  (`ConstraintSolver.h/.cpp`, `DenseMatrix.h`) with per-component
  DOF/sketch-health classification and color coding. Constraints render
  as small clickable on-canvas glyphs, individually selectable and
  deletable or manageable through a new Constraint List dialog. The
  sketch layer is session-only and is never persisted to `.fem`/`.femx`.
  A new Tools menu exposes the drawing tools that previously existed
  only as toolbar buttons.

* The Smart Dimension tool was reworked to Fusion 360's
  select -> preview -> place -> type model, replacing the old
  click-then-immediately-prompt flow. Two selected nodes live-resolve to
  Horizontal, Vertical or Aligned distance from cursor position, each
  backed by its own solver residual (`HorizontalDistance`/
  `VerticalDistance` use |dx|/|dy|) so the constraint matches what is
  displayed rather than relabeling one formula; a second line sharing a
  vertex upgrades the pending dimension to an Angle. Fixed along the
  way: dimension number-labels never set their hit-test Kind/Index, so
  clicking a label read as "clicked node 0" (an unset QVariant defaults
  to 0, aliasing `FemmItemKind::Node`); the preview ghost sat topmost in
  `itemAt()` and could swallow a placement click; and
  `buildDimensionPath()` rendered Horizontal/Vertical dimension lines
  parallel to the segment they measure, since translating both endpoints
  by one offset vector keeps them parallel by construction -- only
  Aligned should do that.

* Angle dimensions now work between two lines that never touch. The
  line -> line angle previously fired only when both segments shared an
  endpoint node, because `DimensionType::Angle` is defined as vertex
  node plus two ray-endpoint nodes and disjoint lines have nowhere to
  put the vertex -- so angling a corner worked and angling anything else
  silently did nothing. Adds `DimensionType::AngleLines`, referencing
  the two segments directly and dimensioning against their virtual
  intersection, with a residual that wraps modulo 180 rather than 360
  (a line has no direction, so a segment stored end-for-end is the same
  line). The Angle Dimension toolbar button now arms Smart Dimension.

* `femmqt` can insert a node where two segments cross, which classic
  FEMM does in `FancyEnforcePSLG` but `femmqt` never has. Without it,
  two crossing lines stay logically disconnected: the mesher sees no
  shared vertex at the crossing, so the regions they appear to bound
  are not actually bounded. Only proper crossings split -- shared
  endpoints and parallel/collinear pairs are skipped -- and the interior
  tolerance is scaled per segment so it means "a hair inside the ends"
  in real distance rather than in parameter space. Wired into the Add
  Segment tool and Draw Rectangle.

* Density plot smoothing is now material-aware and inverse-distance
  weighted, matching `femm/FemmviewDoc.cpp`'s own `GetNodalB`. The old
  "Smoothing" option averaged every element touching a node equally,
  regardless of material, which blurs a real physical discontinuity in
  B into noise -- visible as serration concentrated exactly along
  material boundaries (a core edge, the halo around each winding) where
  classic's edges stayed smooth.

* Click-drag panning in both the editor and the Solution Viewer, via
  MIDDLE or RIGHT button. Middle is the CAD convention (Fusion 360,
  SolidWorks, FreeCAD, KiCad); right is a fallback for mice and
  trackpads without one. Left is deliberately untouched -- it belongs to
  the drawing tools, selection, Shift+rubber-band and the zoom-window
  rubber band, which is also why `QGraphicsView`'s built-in
  `ScrollHandDrag` is not used. New header-only `ViewPanning.h` rather
  than duplicating the handler across two views.

* The Solution Viewer can pan beyond the edge of the model.
  `SolutionGraphicsScene` never set a scene rect, so Qt computed one
  from `itemsBoundingRect()` -- the solved mesh's own extents -- and
  both pan paths clamp to it, leaving the scrollbars with zero range at
  fit zoom. The rect is now set from the loaded mesh, inflated by three
  times its larger dimension per side.

* New Lua commands `setgui("classic"|"qt")`, `getgui()`,
  `mi_savepng(file[,w,h])` and `mo_savepng(file[,w,h])`. Lua only ever
  runs inside the classic MFC app, so `setgui` selects which GUI renders
  for commands producing GUI-derived output rather than switching
  processes. The classic path draws into a memory DC and encodes with
  GDI+ (PNG output classic could not produce before, and no new
  dependency); the Qt path hands off to `femmqt.exe --render-png`. The
  setting is session-scoped and seeded from `femm.cfg`'s
  `<PreferredGUI>`, but `setgui()` does not write that key back.

* `femmqt.exe --render-png <in> <out> [w h [x0 y0 x1 y1]] [--density]`
  can crop to a region and select the density plot. The crop matters
  because density-plot color banding is scaled to what is visible (see
  `MeshSolutionItem::paintDensity`), so a full-model render cannot
  reproduce or regression-test how a zoomed-in view actually looks.

* Single-key tool shortcuts in `femmqt`, bound as `setShortcut` so the
  bare key works whenever the canvas has focus: N node, L line,
  C circle, R rectangle, A arc (joining the existing D for Smart
  Dimension). These had been listed as queued without ever being
  implemented.

* The manual gains a Revision History chapter -- the FEMM 4.2 baseline
  plus every FEMMX release from 1.0.0 -- and a "Commands Added Since
  FEMM 4.2" section listing exactly the Lua commands this fork adds, so
  a script written for stock FEMM can be told apart from one that needs
  FEMMX. The list was taken from the actual `lua_register` calls, which
  is why it credits `setgpuaccel`/`setredraw` to the magnetics and
  electrostatics documents only: despite all four solvers having the
  CUDA port, the `hi_`/`ci_` variants are not registered. The FEMMX logo
  now appears on the title page.

* The installer gained a "Run FEMMX" tick box on its finish page
  (`MUI_FINISHPAGE_RUN`), pointing at the classic GUI like the primary
  Start Menu shortcut. Launching directly is safe only because this
  installer declares `RequestExecutionLevel user`, so it never elevates
  and the app cannot inherit administrator rights.

* `examples/parallel_sweep.py` documents and demonstrates running
  concurrent FEMMX instances for parameter sweeps -- already supported,
  but nothing in the repo said so. Two `Dispatch('femm.ActiveFEMM')`
  calls give two separate `femmx.exe` processes (the automation server
  is registered per-process), there is no single-instance mutex, and
  parallel results are bit-identical to sequential. Instances collide
  only if two workers share a document basename, which silently
  overwrites another worker's mesh and solution and completes with no
  error -- the whole reason the example exists. Backed by new
  regression tests covering process separation, parallel-vs-sequential
  equality, and solver determinism.

04Aug2026 (v2.1.2)

* `femmqt`'s Solution Viewer Density Plot and Point Properties dialog
  computed `|H|` (magnetic field intensity) wrong by 5-6 orders of
  magnitude for nonlinear (BH-curve) materials -- `MeshSolutionElement::
  muX/muY` are a linear-material-only placeholder (mu_r=1), so H was
  computed as `B/(1*mu0)` regardless of the material's real, B-dependent
  permeability. Found via a direct comparison against the classic GUI on
  a real nanocrystalline-core toroidal choke model: classic reported
  mu_r ~8.2 million at the tested point (`mo_getpointvalues`) where
  femmqt's old formula implicitly used mu_r=1. Fixed by porting classic
  FEMM's `CMaterialProp::GetSlopes`/`GetH` (natural cubic-Hermite-spline
  BH-curve interpolation) for the real-valued (DC/magnetostatic),
  unlaminated case (`femmqt/BHCurve.h`, new file) and wiring it through
  every H-computation site via a shared `computeElementH()` helper.
  Required extending the `.ansx` binary cache format (version 5 -> 6) to
  persist each element's resolved BH-curve material index and the
  solved slope data, so the fix also applies on the fast cached-load
  path, not just a fresh `.ans` import -- verified live: `|H|` at a
  fixed test point went from an incorrect 23317.5 A/m to the correct
  0.00284 A/m, matching classic's mu_r ~8.2 million ground truth to
  within numerical precision. AC/harmonic, laminated, and
  permanent-magnet nonlinear materials remain on the old placeholder
  formula, a documented, explicitly scoped gap (see `BHCurve.h`'s own
  comment), not silently approximated.

02Aug2026 (v2.1.1)

* Fixed a `femmqt` crash selecting `|J|`, Re(J), Im(J), or `log10(|B|)`
  in the Solution Viewer's Density Plot Options dialog. An earlier
  change extending `DensityQuantity` from 6 to 10 values never updated
  `MeshSolutionItem`'s fixed-size per-quantity precompute array or its
  fill loop to match, so those 4 quantities read past the end of the
  array and crashed. Found via a real user crash report and a Windows
  crash dump; fixed by sizing/filling that array off a single named
  constant instead of a second hand-synced number, and pointing the
  dialog's own already-correct count at the same constant so the two
  can't drift apart again.

01Aug2026 (v2.1.0)

* `femmqt`'s Solution Viewer Density Plot had two rendering bugs on
  models with an asymptotic open boundary (`mi_makeABC`'s Kelvin-
  transform "u1".."u9" shells) or a nonlinear (BH-curve) material near
  a current source, both found on a real 3-phase toroidal common-mode
  choke model: (1) its auto-range search included the ABC shell's own
  legitimately-huge-but-nonphysical flux density and a handful of tiny,
  spuriously-high-value elements at sharp geometry corners, badly
  skewing the color range -- fixed by porting `femm/FemmviewDoc.cpp`'s
  own `isExt[]` exclusion and size-weighted (`sqrt(rsqr)*v^2`) candidate
  weighting for the range search, matching classic FEMM's `GetBounds()`
  exactly. (2) The geometry-outline overlay drawn on top of the density
  plot never reset the painter's brush before stroking segment/arc
  paths, so it inherited the last-drawn density band's solid fill color
  and flood-filled it across whatever area the crisscrossing outline
  lines happened to enclose, hiding the real per-element gradient
  underneath -- fixed with an explicit `NoBrush`. Root-caused via a bulk
  cross-check of every mesh element's flux density against classic
  FEMM's own `mo_getb` (confirmed matching to numerical noise) and a
  from-scratch reimplementation of femmqt's own coloring algorithm on
  its own data (produced the correct gradient, proving the bug was in
  the paint step, not the physics) -- verified live afterward against
  classic FEMM's rendering of the same file at a matched color range.
* `femmqt` gained a suite of geometry-editor and Solution Viewer
  parity/bug-fix improvements against the classic GUI, found via an
  icon-by-icon and dialog-by-dialog audit against `femm.rc` and the
  classic source: Draw Rectangle and Draw Circle drag-based drawing
  tools; Select by Circle; a real Rotate mode for Move/Copy (About
  Point X/Y, angle, number of copies); Polar coordinate mode with a
  matching Enter Point (Tab) dialog; Zoom Window and Zoom > Keyboard;
  the Solution Viewer's missing left Navigate toolbar, Grid submenu,
  Show Block Names, and Contour Plot Options dialog; full parity for
  the Density Plot Options dialog (all 10 quantities, correctly gated
  by AC vs. DC); Area tool selection highlighting (selected regions now
  actually highlight, and Integrate sums across the whole multi-region
  selection using the full 17-item Block Integral quantity list);
  Circuit Props' divide-by-zero on a zero-amp circuit; a Line Integral
  fix; corrected Problem Info fields; Point Properties gained mu_x/
  mu_y/B.H. Real bugs fixed along the way: Create Radius left the
  original edges undeleted-but-orphaned instead of trimming them to the
  new fillet, arc rendering direction was never compensated for the
  editor's y-flip (a rendering-only bug -- solves were always correct),
  perfectly horizontal/vertical geometry segments were silently culled
  from the Solution Viewer's overlay (a degenerate zero-area bounding
  box), and Show Grid/grid-size/Cartesian-Polar changes plus the
  Solution Viewer's hover tooltip stopped repainting correctly once
  background caching was added for an earlier drag-trail fix.
  Grid now defaults off and auto-sizes from the model's bounding box on
  first open, and the Load Monitor's chart now follows Dark Theme
  live. `femmqt` briefly gained, and then had fully reverted, thermal
  (heat-flow) problem support during this cycle -- it remains
  magnetics-only, matching the classic GUI's own scope.

19Jul2026 (v2.0.0)

* Added `femmqt`: a new Qt6-based GUI, alongside the existing MFC one,
  built out to full feature parity for magnetics (electrostatics, heat
  flow, and current flow remain MFC-only for now). CAD-style geometry
  editing (add/move/copy/scale/mirror, undo, grid snap, group
  selection, Create Radius, Create Open Boundary/ABC, DXF import/
  export); full property editing (Problem Properties, Material/
  Boundary/Circuit/PointProp libraries, an external Materials Library,
  per-entity dialogs including direct node-coordinate editing, BH-curve
  editing); solve invocation via the same `triangle.exe` -> `fkn.exe`
  pipeline the classic GUI uses; a Solution Viewer with Density and
  Contour plots (with an optional toggle for field-direction arrows
  along the contour lines), Point/Contour/Area tools, Plot X-Y,
  Circuit Props, mesh/point overlays, and an Output Window; a light/
  dark theme with its own muted color palette for drawing and
  plotting; a CPU/GPU/RAM Load Monitor, Preferences, Recent Files, and
  hover/cursor readouts throughout. Verified against real solved models
  (textbook field comparisons, mesh/element-count matches, and
  round-tripping files through both GUIs).
* Added `.ansx`/`.femx`: binary caches for solved `.ans` files and `.fem`
  geometry files, regenerated automatically whenever their source is
  newer, so reopening a large solved model is a bulk read with no
  per-line text parsing. Added to the classic MFC GUI too, so both GUIs
  share the same fast-reopen caching and files stay interchangeable.
* Added a two-way "Switch to Qt GUI"/"Switch to Classic GUI" command in
  each app that hands the currently-open file to the other executable
  (a `<PreferredGUI>` marker plus a relaunch), including a distinct,
  always-visible button for it in femmqt's main window, not just a menu
  item. `femm.ActiveFEMM`'s COM automation still points at `femmx.exe`
  only -- `femmqt.exe` has no COM automation support yet. The classic
  GUI keeps the default Start Menu shortcut; femmqt is still in active
  development.
* Extended the optional CUDA-accelerated linear solve (see v1.0.0) to
  the other three solvers: `hsolv` (heat flow), `belasolv`
  (electrostatics), and `csolv` (current flow), each with its own
  `*_setgpuaccel`/`*_setredraw` Lua commands and `[GPUAccel]` file
  persistence, mirroring `mi_setgpuaccel` exactly. `csolv` needed its
  own CUDA kernel since its complex-symmetric system's convergence
  criterion differs from the other solvers'.
* Assorted fixes: the classic GUI's post-processor had a "Switch to Qt
  GUI" menu item that was never wired into the MFC message map; the
  Load Monitor's current-flow/electrostatics labels were swapped;
  `manual.pdf` wasn't packaged into the installer; femmqt's "Zoom
  Natural" could badly mis-frame real-world models.
* New problems default to millimeters (previously inches) and to CUDA
  acceleration on when built alongside CUDA-enabled solvers (previously
  always off by default), in both GUIs.
* Installer: detects an existing FEMMX install on launch and offers to
  uninstall it first, instead of silently installing alongside it.
* femmqt Plot X-Y gained an actual line chart (with CSV/PNG export)
  instead of a bare text table, plus a quantity selector (|A|/|B|)
  showing one plot at a time.
* Fixed a stale drag-trail artifact in femmqt's geometry editor: rapid
  node/block-label dragging could leave visibly-brighter ghost patches
  behind from repeated antialiased grid-dot repainting; now fixed via
  background caching.

17Jul2026 (v1.2.0)

* Extended the Dark Theme toggle to the entire application, not just the
  magnetics editor. New `femm/DarkMode.h`/`femm/DarkMode.cpp`: an
  app-wide subsystem covering the main frame, every MDI child, and every
  dialog's native controls (via `DWMWA_USE_IMMERSIVE_DARK_MODE` for
  title bars, undocumented uxtheme.dll ordinals for native control
  theming, and a `WH_CBT`/`HCBT_CREATEWND` hook + window subclassing to
  catch every dialog control regardless of creation order -- no shared
  dialog base class exists across the app to hook centrally). Each of
  the 6 problem-type views that previously had no canvas dark-theme
  support at all (electrostatics, heat flow, current flow -- pre- and
  post-processor each) gained its own `ApplyTheme()`/
  `OnViewDarkTheme()` pair mirroring the existing
  `CFemmeView`/`CFemmviewView` pattern, plus a "Dark Theme" View menu
  entry.
* Fixed redraw corruption when panning or zooming while a large mesh's
  grid or density plot is being drawn: a single pan/zoom keystroke could
  leave the view stuck with only a small fraction of the plot rendered,
  indefinitely, even after input went quiet. `Pump()` (all 8 view
  classes) lets a slow `OnDraw` bail out of a now-stale redraw once
  newer navigation input is queued, but the message that triggered the
  cancellation (very often a trailing `WM_KEYUP` right behind the
  `WM_KEYDOWN` that started the redraw, or `WM_MOUSEWHEEL`, which no
  view handles at all) does nothing when it's finally dispatched -- so
  no replacement redraw ever arrived to finish the job. Every `OnDraw`
  now unconditionally requests one more repaint whenever it was cut
  short, regardless of which message caused the cancellation, which
  guarantees eventual completion once input actually settles.
* Widened the CPU/GPU/RAM load monitor chart's rolling window from 60s
  to 1000s (`kMaxSamples` 240 -> 4000, still one sample per 250ms) for
  longer solves.
* Updated the LaTeX manual's title page: version bumped from the stale
  pre-fork "4.2" to FEMMX's own version, added an explicit "fork of FEMM
  4.2 (femm.info)" line and this repository's URL, and relabeled the
  existing David Meeker credit as the original FEMM author's rather than
  this fork's. CI now builds `FEMMX_v<version>_manual.pdf` and uploads
  it as an artifact alongside the installer, kept fully decoupled from
  the main build so a LaTeX toolchain hiccup can't fail the
  build/tests/installer.

17Jul2026 (v1.1.1)

* Fixed .ans load taking minutes on large solved models (e.g. a
  transformer model with an 8.7M-node/element mesh: 384.5s -> 10.4s to
  open, 37x). Three compounding issues:
  - build.ps1 referenced a $DoNotUseNinja switch that was never actually
    declared as a parameter, so the branch that set "--config Release"
    for cmake's build step could never run. No -G was ever passed
    either, so cmake always fell back to its own default (a multi-config
    Visual Studio generator), and building that with no --config
    defaults to Debug. Every build produced by this script -- dev
    builds, the packaged installer, and CI -- has therefore always been
    an unoptimized Debug build of every target, despite the
    build_win_release* folder names. $selectConfig is now set
    unconditionally.
  - CFemmviewDoc::OnOpenDocument (femm/FemmviewDoc.cpp, and the
    belaview/cview/hview equivalents) parsed each mesh node/element line
    with sscanf, far slower than manual parsing for a file with millions
    of such lines. Replaced with strtod/strtol walking a pointer along
    the line.
  - The "multiply defined block labels" correctness check called
    InTriangle() once per block label to find which mesh element
    contains that label's point. InTriangle() searches outward from
    wherever the previous call left off -- fast for spatially coherent
    queries, but block labels here are scattered all over the model, so
    each call degraded towards an O(elements) scan, making the whole
    check O(labels x elements); this one loop alone accounted for 93% of
    the load time above. Elements are now binned into a uniform grid
    once, and each query searches outward cell-by-cell from its own
    position instead -- same "will eventually find it" guarantee, O(1)
    average instead of O(elements) per query.

17Jul2026 (v1.1.0)

* Batched the pre-/post-processor mesh-line drawing (femm/FemmeView.cpp,
  femm/FemmviewView.cpp, femm/beladrawView.cpp, femm/belaviewView.cpp,
  femm/cdrawView.cpp, femm/cviewView.cpp, femm/hdrawView.cpp,
  femm/hviewView.cpp): one MoveTo()+LineTo() GDI call pair per mesh edge
  (plus a GetClientRect() per edge for off-screen clamping) made large-mesh
  visualization slow -- hundreds of thousands of individual GDI/Win32 calls
  per repaint. Edges are now accumulated into a capped buffer and flushed
  via PolyPolyline(), mirroring the density-plot PolyPolygon batching
  already in place.
* Fixed pan/zoom input feeling delayed while a large mesh redraws: the
  pre-processor geometry/mesh views had no message-pumping during OnDraw at
  all, so a slow redraw fully blocked input until it finished; the
  post-processor result views had a Pump() helper meant to keep the UI
  responsive, but it dispatched the pending pan/zoom keystroke mid-draw
  while the current redraw kept rendering with now-stale cached
  coordinates, and also risked a reentrant OnDraw call by dispatching
  WM_PAINT itself. Pump() (added to the 4 pre-processor views, fixed in the
  4 post-processor views) now detects pending navigation input before
  dispatching anything and reports it back as a cancellation signal, no
  longer dispatches WM_PAINT, and every OnDraw drawing stage checks that
  signal and bails out immediately so a stale frame ends fast and the newer
  input is processed right away.
* Added build_all.bat, a zero-argument wrapper that runs build_plain.bat
  and build_cuda.bat back to back for a local CPU-only + CUDA build in one
  step.
* Versioned the application: the main window title (IDR_MAINFRAME) now
  reads "FEMMX v1.1.0", VERSIONINFO's FILEVERSION/PRODUCTVERSION (femm.rc)
  are updated to match (previously stale leftovers from the pre-fork femm
  4.2 baseline), and the installer (script.nsi) now builds as
  FEMMX_v1.1.0_installer.exe and records DisplayVersion in the uninstall
  registry key. Also rebranded IDD_ABOUTBOX, which still read "About femm"
  / "femm 4.2" after the FEMMX rename, to "About FEMMX" / "FEMMX v1.1.0".

10Jul2026 (v1.0.0)

* Rehosted this repository as a fork, FEMMX, at
  https://github.com/SpgV0/femmx, cloned from
  https://github.com/cenit/FEMM commit 7d9e8ed. See NOTICE.md for the
  license-required modification record.
* Added test/, with Python scripts that build and solve FEMM
  models via the pyfemm COM interface: straight_wire_field.py (a
  current-carrying-wire magnetostatics problem validated against the
  closed-form Ampere's-law solution), copy_redraw_benchmark.py,
  enforce_pslg_correctness_test.py, and lua_command_regression_test.py
  (see next items). Each script writes its generated files under its own
  test/results/<script_name>/ subfolder.
* Added mi_setredraw(flag) Lua/scripting command
  (femm/femmeLua.cpp, femm/FemmeDoc.h) to suspend the magnetics editor's
  canvas redraw during batch edits, e.g. repeated mi_copytranslate/
  mi_copyrotate calls. Fixed DrawPSLG() (femm/FemmeView.cpp), which
  didn't honor the existing NoDraw suppression flag unlike OnDraw(), and
  wired the Edit > Copy/Move dialogs to use the same suspend/resume
  pattern.
* Fixed CFemmeDoc::EnforcePSLG() (femm/MOVECOPY.CPP): called once per
  Copy operation, it used to rebuild the entire node/segment/arc/block
  list from scratch via intersection-checking Add* calls, making it
  O(n^2) in total feature count -- the dominant Copy cost on large
  drawings. RotateCopy/TranslateCopy only ever append new geometry to
  the end of each list, so a new EnforcePSLG(tol, nodeStart, lineStart,
  arcStart, blockStart) overload now only re-validates the newly added
  tail (still checked against the full existing drawing, so correctness
  is unchanged -- see test/enforce_pslg_correctness_test.py).
  Combined with the mi_setredraw fix above, measured 9.4x speedup over
  30 repeated copy actions against a 1,600-block-label model; see
  test/results/copy_redraw_benchmark/copy_benchmark.txt.
* Added test/lua_command_regression_test.py, a regression sweep
  over FEMM's ~450-function Lua command surface (magnetics, electro-
  statics, heat flow, and current flow, both pre- and post-processor
  prefixes), tracking every command call as PASS/FAIL/SKIP so a change
  to the shared editing code used by every problem type's editor shows
  up here. Surfaced a few pre-existing, unrelated issues along the way
  (a savebitmap bug in all four pre-processor editors, a pyfemm-exposed
  ci_refreshview that isn't actually a registered Lua command, a bug in
  pyfemm's own AWG/IEC helpers) -- see test/README.md and
  test/results/lua_command_regression/lua_command_regression.txt
  for details. Magnetics (the editor this fork modifies) passes cleanly
  apart from the savebitmap issue above.
* Experimental, isolated in its own commit for easy revert: added a
  "Dark Theme" toggle to the magnetics editor's View menu
  (ID_VIEW_DARKTHEME; femm/femm.rc, femm/resource.h, femm/FemmeView.h,
  femm/FemmeView.cpp). Swaps the canvas colors (background, grid, node,
  line, block, mesh, selection, name) between the light defaults and a
  dark palette, and best-effort switches the main window's title bar via
  DwmSetWindowAttribute/DWMWA_USE_IMMERSIVE_DARK_MODE (Windows 10
  1809+/11; a no-op elsewhere). Scope: only the magnetics editor's
  canvas and title bar are re-themed -- menus, toolbars, and dialogs
  still use the OS's native (light) common-control rendering, since
  re-theming those would require owner-drawing every control.
* Converted the regression scripts under test/ (renamed from
  test_models, then unittests) into pytest-based unit tests with
  skip-logic for machines missing prerequisites, and added a GitHub
  Actions CI workflow (.github/workflows/ccpp.yml) that builds FEMM
  and the NSIS installer and runs the full suite on windows-latest.
* Added an optional CUDA-accelerated linear solve for fkn.exe's
  magnetostatic/DC solver (fkn/spars_cuda.cu/.h): a CSR-based,
  GPU-resident Jacobi-preconditioned conjugate gradient implementation
  using cuSPARSE/cuBLAS, mirroring CBigLinProb::PCGSolve step for step.
  Off by default; opt in per-problem via the "Use GPU Acceleration"
  checkbox in the Problem Definition dialog (femm/probdlg.cpp) or the
  mi_setgpuaccel(flag) Lua command (femm/femmeLua.cpp), persisted in the
  .fem file's [GPUAccel] field. Falls back to the CPU solver at run
  time if no usable GPU is found, or shows a dialog with setup
  instructions if fkn.exe was built without CUDA support at all.
  Building it requires -DENABLE_CUDA_SOLVER=ON and the CUDA Toolkit
  (see fkn/CMakeLists.txt); a normal build.ps1 build is unaffected.
  Validated correct (0.0000% relative difference from the CPU solver)
  and faster (1.3x on a ~70k-node problem, 3.5x on a ~700k-node
  problem) on real hardware; see test/gpu_solver_test.py.
* Added a CPU/GPU load monitor window (fkn/LoadMonitorDlg.h/.cpp),
  shown alongside the existing solver progress dialog whenever fkn.exe
  is solving. Plots a rolling 60-second strip chart of CPU utilization
  (via GetSystemTimes) and, when an NVIDIA GPU and driver are present,
  GPU utilization (via NVML, loaded dynamically so this doesn't require
  the CUDA Toolkit to build). Includes a "Save as PNG..." button
  (GDI+). Builds unconditionally, independent of ENABLE_CUDA_SOLVER.
  The window now also stays open after the solve finishes (for
  interactive/non-scripted runs only -- scripted mi_analyze() calls,
  which femmx.exe always waits on synchronously, are detected and exit
  promptly as before) so the final chart and "Save as PNG" remain
  usable until the user closes it.
* Extended the CUDA-accelerated linear solve to fkn.exe's harmonic
  (AC/eddy-current) solver (fkn/spars_cuda.cu's CudaPBCGSolve,
  fkn/cspars.cpp's PBCGSolveGPU): the same Jacobi-preconditioner swap as
  the DC solver above, but for CBigComplexLinProb's complex-symmetric
  system (cuSPARSE/cuBLAS complex-valued CSR SpMV and dot products).
  Uses the same GPUAccel opt-in (checkbox/mi_setgpuaccel/.fem field) as
  the DC case -- one setting now covers both solvers. Profiling showed
  the linear solve is ~85% of total solve time (assembly and meshing are
  comparatively negligible), so this was the highest-value remaining
  optimization target; see test/ac_gpu_solver_test.py. Validated correct
  (0.0000% relative difference from the CPU solver) and faster (2.2-2.4x
  on a ~40k-node eddy-current problem) on real hardware.
* Documented mi_setgpuaccel and mi_setredraw -- the two Lua commands
  added since the femm-4.2-22Oct2023 pre-fork baseline -- in the
  manual's Lua Scripting chapter (manual/magnlua.tex, Problem Commands
  and Editing Commands sections respectively).
* Rebranded the fork from femm_plus to FEMMX: the main GUI/COM-server
  executable is now femmx.exe (femm/CMakeLists.txt), with the window
  title, VERSIONINFO strings, installer (script.nsi), CI workflow, and
  the Mathematica/Octave interface scripts (mathfemm/mathfemm.m,
  octavefemm/mfiles/openfemm.m) updated to match. The femm.ActiveFEMM
  COM ProgID, the solver executables (fkn.exe/csolv.exe/hsolv.exe/
  belasolv.exe), and the femm/ source directory and file names are all
  unchanged by this rename -- see scripts/register_femm_com.ps1 for how
  the ProgID's LocalServer32 registry entry now points at femmx.exe.
  Also removed the now-superseded spgryparis/femm_mods hosting
  reference from this file and NOTICE.md, keeping only the original
  https://github.com/cenit/FEMM upstream reference and the current
  https://github.com/SpgV0/femmx hosting.
* Added build_plain.bat and build_cuda.bat, zero-argument wrappers
  around build.ps1 (via the new build_femmx.ps1) for a local CPU-only
  or CUDA-enabled dev build. build_cuda.bat auto-detects the CUDA
  Toolkit root (preferring 12.x over 13.x, which dropped compute
  capability sm_60) and an nvcc-compatible MSVC toolset (-ccbin),
  falling back to VS2022's if a newer Visual Studio is installed. Each
  outputs to bin/plain/ or bin/cuda/ so the two builds don't clobber
  each other. Fixed two bugs found while building this: build.ps1's
  folder cleanup never matched build_win_release64_notriangle (the
  directory -ForceTriangle32bit actually creates), so a cached
  ENABLE_CUDA_SOLVER=ON could silently leak into the next CPU-only
  build; and -ccbin alone doesn't override the INCLUDE environment
  variable VsDevCmd.bat sets for the newest installed Visual Studio, so
  nvcc kept resolving MSVC STL headers new enough to require CUDA 13.2+
  even with an older -ccbin (fkn/CMakeLists.txt now adds an explicit
  -I for -ccbin's own toolset headers, which take precedence).
* Restructured the installer (script.nsi) to match the original FEMM
  4.2 installer's C:\femm42 layout: executables now install to
  $INSTDIR\bin (previously flat in $INSTDIR), and the Mathematica/
  Octave/Scilab interfaces are packaged too, at $INSTDIR\mathfemm,
  \mfiles, and \scifemm -- matching what mathfemm.m and octavefemm's
  openfemm.m already hardcoded. Defaults to a fixed C:\FEMMX install
  directory (was $APPDATA\FEMMX) to match. The installer now also
  bundles the CUDA runtime DLLs for a CUDA build (previously left out,
  so an installed CUDA build silently fell back to CPU), and
  self-registers the femm.ActiveFEMM COM class on install/uninstall
  (see scripts/register_femm_com.ps1's docstring for why femmx.exe's
  own COM self-registration doesn't currently work under this CMake
  build) -- so pyfemm/Octave/Mathematica/Scilab automation works
  immediately after a normal install, no separate manual step needed.
  Fixed a CMake ordering bug found while building this: the installer-
  build step was running before the install(TARGETS...) steps that
  copy executables into bin/, so it packaged stale leftovers rather
  than the current build -- moved into its own subdirectory
  (installer/CMakeLists.txt), added last, since sibling subdirectories
  preserve add_subdirectory() call order but a directory's own
  install() rules do not run after its subdirectories' regardless of
  source order.
* scifemm/CMakeLists.txt now actually builds scilink.dll (was building
  an unused static library, even though scilink.cpp already declared
  proper dllexports for the three functions scifemm.sci loads via
  link(..., "scilink.dll", ...)) -- the Scilab interface is now
  functional. Added Octave wrappers (octavefemm/mfiles/) for three
  Lua commands that had none: mi_setredraw.m, mi_setgpuaccel.m,
  get_solve_stats.m.
* register_femm_com.ps1 now snapshots whatever COM registration
  existed before it runs (to $env:TEMP, first call of a session only,
  so switching builds mid-session doesn't lose the true original); new
  scripts/unregister_femm_com.ps1 restores it afterwards, or removes
  the registration entirely if there wasn't one. Wired into
  .github/workflows/ccpp.yml as an always-run cleanup step, so running
  the regression suite no longer leaves a permanent side effect on the
  machine's registry.
* Fixed the CPU/GPU load monitor not updating during an interactive
  (GUI "Analyze" click, not scripted) solve: MarkSolveStart()/
  MarkSolveEnd() were only ever called from each analyze entry point's
  Lua-scripted branch, since the interactive path fires off the solver
  process and returns immediately with no wait loop to call
  MarkSolveEnd() from. MarkSolveStart() now optionally takes the
  child process handle, and CLoadMonitorDlg's existing sample timer
  polls a duplicate of it to detect completion and end the solve
  itself (femm/LoadMonitorDlg.h/.cpp, femm/FemmeView.cpp,
  femm/hdrawView.cpp, femm/cdrawView.cpp, femm/beladrawView.cpp).
* Reworded the GPU-accelerated-solve failure dialog (fkn/spars.cpp,
  fkn/cspars.cpp): it said "no usable GPU was found" even when the GPU
  ran fine but the Jacobi preconditioner (needed for GPU parallelism,
  weaker than the CPU solver's SSOR on some matrices, e.g. finely-
  stranded litz windings) simply didn't converge -- now names
  non-convergence as a distinct third cause, and fkn/spars_cuda.cu logs
  which of the three actually happened.
* Added the same dark theme toggle the magnetics editor has to the
  results/post-processor window (CFemmviewView, the .ans window):
  "Dark Theme" on its View menu (IDR_FEMMVIEWTYPE), with dark
  equivalents for the plot-specific colors (region/text/flux-line/
  vector) the editor doesn't have (femm/FemmviewView.h/.cpp,
  femm/femm.rc).
* Batched the density plot's GDI drawing (femm/FemmviewView.cpp):
  PlotFluxDensity issued one Polygon() call per rendered sub-triangle,
  easily millions for a fine mesh, since the per-element field math is
  cheap and GDI call count -- not computation -- is what actually
  dominates a large density-plot repaint. The existing per-legend-band
  (0-19) cached pens/brushes are now view members instead of
  function-local statics, and OnDraw accumulates each band's
  sub-triangle vertices and flushes them with a single PolyPolygon()
  call per band (at most 20 GDI calls per repaint) instead of drawing
  each sub-triangle immediately.

22Oct2023

* Updated radiation boundary condition in thermal problems so that convective
  terms are also used, i.e. a combined radiation/convection/flux boundary can
  be modeled if desired. Convection bc also updated so that convection/flux
  can be modeled if desired.
* Updated some low-level aspects how femm and the solvers are initialized to
  support programmatically hiding the main window while using pyfemm in Wine.
* Patched triangle source code from:
  https://github.com/microsoft/vcpkg/tree/master/ports/triangle
  added for VS2022 compatibility.  The VS2022 version of the solution points
  to the triangle64 directory which contains the patched code.  However, the
  distribution executables were compiled with VS2008 using the source in the
  (unpatched) triangle directory for Wine compatibility.

25Jul2022

* Fixed a bug where imaginary part of a conductor voltage in a current flow
  problems was ignored.

01Apr2022

* Fixed bug where rotation of magnetic material is incorrect if the material
  is defined more than once.

01Mar2022

* Changed installer for better silent operation

23Jan2022:

* Fixed magnetic material property definitions for some SVG wire sizes

26Jun2021:

*  mi_setcomment and related ei_, hi_, and ci_ functions added to set the
   comment text in the problem definition.

26Jun2021:

* Fixed energy integral for airgap boundary conditions.  It didn't work
  correctly for time-harmonic problems (thanks Nicola Bianchi)
* Fixed broken magnetic materials library entries for legacy NdFeB 40, 
  M47 silicon steel.
* Changed lua implementation of mi_probdef and friends so that an out-of-range
  Precision is clipped to the allowable range rather than throwing a cryptic
  error message.
* Fixed SciFEMM to work with Scilab 6.1.0. SciFEMM bug with mi_getmaterial,
  ci_getmaterial, ei_getmaterial, and hi_getmaterial fixed.
* Added retries to various "fopen" instances that could occasionally fail
  in long batch runs.
* Changed formatting string for B-H points dialog to %.15g instead of %f so
  that precision of B-H curve points is not truncated.
* Updated to compile with Visual Studio 2019.  Improves solution speed on
  most problems.
* Fixed OnDraw functions so that the operating system does not think that the
  program is non-responsive during the drawing of density plots for solutions
  with lots of elements.
* Added log(|B|) density plot for magnetics problems.
* Fixed vector plot problem in 22Jul2020 build inadvertently introduced by
  log(|B|) density plot
* Changed all calls to Triangle to use the -j flag to "jettison vertices that
  are not part of the final triangulation from the output .node file". This
  gets rid of the spurious "singlarity flag tripped" and "can't solve the
  problem" messages that popped up due to orphaned nodes in the solution 
  domain.

21Apr2019: 

* Start from previous solution for magnetics problems. To use this, specify a 
  file name in "Previous Solution" edit box in the Problem Definition dialog.
  Specify the "Prev Type" to be "None".  This works if the mesh has not changed
  from the last solution.  Good rotating problems with the "sliding band"
  boundary connecting the rotor and stator.  These problems often involve
  consideration of a sequence of problems with slightly different rotor angles
  and currents.  The "sliding band" approach lets the rotor move without
  modifying the mesh.
* Updated materials library for heat flow problems (thanks to Daniel Gheorghe)
* Updated hard magnetic materials in magnetics materials library (thanks to 
  Mike Devine). Includes new definitions for Sintered NdFeB, Bonded NdFeB,
  Sintered SmCo, and Alnico. See explanatory webpages on femm.info for sources
  and rationale.
* Fixed precision in exported DXF so that no precision is lost in DXF exports.
* Changed the algorithm that identifies limits for plotting flux density so 
  that exterior regions (both Kelvin Transformation and IABC) are not 
  considered. These exterior regions can have high flux densities that mask
  the flux density variations in the interior region of interest.
  
06Oct2018: (Test Build)

* Fixed the cause of an occasional error that happens running many runs in
  Mathematica.  Fkn.exe occasionally could not open a *.ans file to write over 
  older results.  The fix adds a retry if the file can't be opened.
* Fixed a bug with the computation of the "sliding band" incremental torque
  integral. The "previous solution" used to calculate the integral was not
  obtained correctly.
* For incremental runs, mesh temporary files never got deleted, leaving extra,
  spurious files hanging around. Code has been added to get rid of these
  files when they're not needed any more.  

25Feb2018:

* Added an "air gap boundary condition" that allows the rotor to be continuously
  moved without the mesh changing with rotor position. A number of new scripting
  functions have been added to calculate forces, torques, and field values of
  associated with an analytical solution in the air gap between the rotor and
  stator. Detailed examples to follow.
* Added file-by-file smartmesh attribute along with scripting commands for each
  input file type (mi_smartmesh, ei_smartmesh, hi_smartmesh, ci_smartmesh)
  to turn smartmesh on or off for a particular file.  The global smartmesh
  scripting function still works to turn smartmesh on or off across all problem
  types for a particular session.
* Moved to console version of Triangle 1.6 made from directly compiling Triangle
  source rather than wrapping it with a dialog.

03Dec2017: (Test Build)

* Fixed one more focus-stealing hole that took away focus during Lua
  script execution. As noted at https://tinyurl.com/y9uggja3 the OnInitDialog
  functions of triangle.exe, fkn.exe, belasolv.exe, csolv.exe, and hsolve.exe
  must return FALSE instead of TRUE, or else focus might be stolen.
  
24Nov2017: (Test Build)

* Changed to Triangle 1.6 instead of Triangle 1.3.  Version 1.6 is more
  robust and usually does not hang / crash if there are small angles
  in the input geometry.
* In cases where Triangle previously hung (displaying an error message)
  when an error occurred, the program now terminates and indicates that
  an error has occurred.  This is especially useful for Matlab/Octave
  scripts, which now get passed the error indication rather than having
  the script hang on the meshing error. 
* Fixed a number of additional instances of focus-stealing during script
  execution.  This makes it possible to do other things while FEMM is
  running a long (Matlab/Octave or Mathematica) script.
* Added a new optional parameter to openfemm in Matlab/Octave/Mathematica
  and Scilab scripting.  openfemm(1) starts FEMM fully minimized.  
* Calls to the analysis (mi_analyze, etc.) assume the state of the main 
  window.  For example, if a scripting run is started minimized with 
  openfemm(1), subsequent mi_analyze() calls will also be run
  minimized automatically.
* Fixed SciFEMM interface so that it works with Scilab 6.0.0

24Sep2017: (Test Build)

* Fixed mi_attachdefault, ei_attachdefault, hi_attachdefault, and
  ci_attachdefault functions, which didn't work correctly.

23Jun2016: (Test Build)

* Fixed sign error with off-diagonal term in permeability tensor for
  incremental permeability problems.

14Jun2016: (Test Build)

* Added a "frozen permeability" problem type that can be used to split up 
  field contributions between various excitation sources for nonlinear DC
  problems.  Also extends the "incremental permeability" formulation to DC
  problems.  The DC incremental results can be used as part of a general 
  time-transient solver, essentially providing the derivatives of flux
  linkage with respect to incremental changes in current and with 
  respect to small changes in position / orientation of moving parts.
* Dropped support for versions of Mathematica before version 5.0.  Versions
  prior to 5.0 do not include .NET/Link for interprocess communications,

12Jan2016:

* Fixed bug added in 01Nov2015 that messed up the reported permeability and
  field intensity for nonlinear time harmonic problems.

01Nov2015:

* Adds "incremental permeability" AC solver. An example application for
  this functionality is the analysis of the frequency-dependent impedance
  of speaker drivers about the DC operating point established by the 
  speaker's permanent magnet.
  - DC operating point specified as the "Previous Solution" in the problem
    definition or via the mi_setprevious(filename) command in Lua.
* Adds 10% and 15% Copper Clad Aluminum magnet wire material types. The
  material definition is intended to provide accurate estimates of proximity
  and skin effect losses across a wide range of frequencies with a bulk
  wire model (i.e. not every turn has to be individually modeled).
* Changes to some of the issues pointed out over the last couple years, e.g.
  - Change to InTriangle test to fix the issues that could occur if a 
    specified point is exactly on the line between two elements
  - Lua command to programmatically turn off "smart mesh" with the 
    smartmesh(state) Lua command.  State is 0 for no "smart mesh" and 1
	for "smart mesh".  Function has the same name in the Matlab interface
	and is named SmartMesh in the Mathematica implementation
  - Fixed bug where "mo_zoom", "eo_zoom", etc. didn't work right
  - Fixed an issue where the right energy / flux linkage was not reported
    for wound coils in AC magnetic problems if the frequency is very 
	small (e.g. <1μHz)
* For increased compatibility with Mathematica 10, the Mathematica interface
  has been changed to use .NET/Link when it is available (instead of
  MathLink).  .NET/Link invokes FEMM as an out-of-proc ActiveX server 
  (the same way that FEMM communicates with Matlab).

15Nov2013:

* Changed the way that errors are trapped in Matlab/Octave and Scilab
  implementations so that errors that would normally display as message
  boxes in a normal GUI session instead get returned as errors to
  Matlab/Octave or Scilab.  Errors can then be trapped, e.g. by using a
  try/catch block.

07Nov2013:

* Fixed instances of GetWindowLong and SetWindowLong which caused the x64
  build to crash when running on Linux via Wine.
* Fixes to eo_blockintegral and co_blockintegral functions. Previously wouldn't 
  allow integration (e.g. for Weighted Stress Tensor force) if the only selected 
  area was a conductor surface.

25Aug2013:

* Changed IABCs to support either a Dirichlet or Neumann outer edge.  This
  is useful for electrostatic problems.

04Aug2013:

* Added mi_selectcircle, mi_selectrectangle and friends to programmatically
  select regions.
* Changed .dxf import so that objects assigned layers are imported as
  grouped being in the same group.
* Added new "Improvised Asymptotic Boundary Condition" button and mi_makeABC
  and friends Lua functions as an alternate way of solving unbounded
  problems.

11Apr2012:

* Can turn off "smart meshing" via a Preferences selection on the "General Attributes"
  tab by unchecking "use smart meshing"
* Fixed a newly introduced bug where an erroneous resistive loss is computed for AC
  problems in regions where conductivity = 0
* Fixed mi_readdxf problem described as Bug 18 in the bug tracker.

01Oct2011:

* Fixed error in reported flux linkage. Flux linkage for stranded regions 
  carrying zero current is not reported correctly for AC problems.
* The Lua "format" command did not work properly with complex number--it 
  stripped off the imaginary part of the number.  This is now fixed.
* The units reported for some heat flow block integral results were erroneous. 
  This has now been rectified.
* 64-bit version of FEMM 4.2 is now available.
* FEMM has been modified to allow multiple instance of FEMM to run at the 
  same time via ActiveX.  For example, This allows multiple instance of FEMM
  to be controlled by one instance of Matlab or Octave.
* FEMM 42 09Nov2010 asks for Mathematica integration when using the silent 
  install method. The installer script has been modified so that the silent
  install assumes that Mathematica is not available, letting the installation
  complete without requiring operator intervention.
* Default material.  A feature has been added which allows one block label to
  be designated as the default block label. Any unlabeled blocks are then
  assumed to be tagged by the default block label.
* In the current flow problem type, line plots of quantities normal and
  tangential to a user-define contour were messed up because the normal
  and tangential directions were computed incorrectly.  This is now fixed.
* The "default" mesh size has been changed.  In previous builds, using the
  default mesh size nearly always resulted in a mesh that was too coarse to
  give accurate results. The default mesh size has been changed so that
  specifying the default mesh size is adequate for most applications.
  Note: can use the <F3> and <F4> keys to uniformly refine and coarsen the
  mesh for the entire model with one keystroke.
* Added automatic refinement of the mesh near corners.  This refinement 
  improves convergence of results like force, stored energy, etc.
* Changed the way that the maximum flux density is computed for flux density
  plotting purposes.  With the automatic refinement of corners, small elements
  with high flux densities can appear in corners. The modified algorithm
  discounts these small corner elements when picking a maximum for the purposes
  of picking plot contours.
* Changed the key that is used to break out of Lua scripts to ESC from BREAK.
  Many keyboards don't have a BREAK key anymore, so it made sense to make this
  change.
* Changed the selection rectangle to a dotted line so that it would 
  render faster.
* Modified the DXF import to understand closed POLYLINE entities.  Previously,
  only open POLYLINE entities were supported.
* Fixed problem with functionality that creates rounded corners (i.e.
  the functionality invoked by mi_createradius) where the program would not
  allow a radius to be created if the intersection was between a line
  segment and an arc segment if the line segment laid along a ling that
  passed through the center of the circle associated with the arc segment.
* Default install directory changed to c:\femm42 to avoid directory
  permissions problems in Windows 7.
  
09Nov2010:

* Added a set of Scilab functions for interfacing with FEMM. These
  functions were tested using Scilab 5.2.2. The descriptions of these
  functions are identical to those described in the OctaveFEMM
  documentation. Example Scilab scripts are in the femm42/examples directory
  and have a .sce file extension and can be run by typing:
  exec('examplename.sce',-1)
  at the Scilab commandline. If you did not install FEMM to the default
  c:\Program Files\femm42 directory, you'll need to change the first line
  of the *.sce files that loads the FEMM library so that it points to the
  correct library location.

11Oct2010:

* Fixed bug in values of |H| reported in the Output Window for time harmonic
  magnetic problems.
* Fixed bug where in some plots, units of H given as A/m^2 instead of A/m
* Fixed error in mo_showvectorplot Matlab/Octave function.  Also fixed
  similar errors in co_showvectorplot, ho_showvectorplot, eo_showvectorplot
* Fixed messed-up definitions of the Lua functions ei_defineouterspace,
  ei_attachouterspace, and ei_detachouterspace
* Installer now prompts for whether or not Mathetmatica support is to be
  included. If Mathematica support is selected, a version of FEMM is
  installed that assumes the availability of ML32I2.DLL, a DLL installed by
  Mathematica. Otherwise, a version of FEMM is installed that doesn't need
  the Mathlink DLL.
* Re-wrote the GetIntersection routine that finds intersections between two
  line segments.  In some uncommon circumstances, the routine could create 
  extra points when the geometry was moved or rotated.
* Added extra Lua functions mi_getmaterial, ei_getmaterial, hi_getmaterial,
  and ci_getmaterial to fetch material definitions from the materials
  library on disk.  Analogous functions were also added to the Matlab/Octave
  and Mathematica interfaces.

02Nov2009:

* Added the Lua commands mi_setgroup, ei_setgroup, hi_setgroup, ci_setgroup
  that assign all selected items to the group number specified by the
  argument to the function.
* Fixed a bug that caused an incorrect permeability to be reported for
  nonlinear materials at points where the flux density is less than 10nT.
* Fixed bugs with ci_addconductor and ci_modifyconductor Lua functions.
* Fixed bug with CIAddMaterial function in MathFEMM

15Jul2009: Several minor changes have been made versus the 01Apr2009 release:

* Added the following Lua commands that allow direct access to finite
  element mesh information:
  mo_numnodes, mo_numelements, mo_getnode, mo_getelement,
  eo_numnodes, eo_numelements, eo_getnode, eo_getelement,
  ho_numnodes, ho_numelements, ho_getnode, ho_getelement,
  co_numnodes, co_numelements, co_getnode, co_getelement.
  There are Matlab/Octave and Mathematica analogs of these commands, too.
* Made a few more performance tweaks to the Mathematica interface.
* Fixed bug in computation of heat flux passing through a constant
  temperature-type "conductor property"
* Included a new selection of soft magnetic materials in the magnetic 
  materials library. The BH curves for these materials were obtained by
  digitizing the curves picutured in Figure 17, "Direct current 
  magnetization curves for various magnetic materials", Metals Handbook,
  8th ed, Vol. 1, p. 792.  These curves represent a wide variety of
  materials, and the curves are defined to very high flux levels at
  which all materials are fully saturated.

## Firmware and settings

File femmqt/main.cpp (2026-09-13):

#include <QApplication>
#include <QFile>
#include <QFileInfo>
#include <QTextStream>

#include "AnsFileIO.h"
#include "SolutionFileIO.h"
#include "ProblemKind.h"
#include "AnsxFileIO.h"
#include "AppPreferences.h"
#include "AppTheme.h"
#include "ConstraintSolver.h"
#include "CircuitAnalysis.h"
#include "DxfIO.h"
#include "FemmProblem.h"
#include "FemmFileIO.h"
#include "FemmProblemEdit.h"
#include "FileRouting.h"
#include "MainWindow.h"
#include "Notify.h"
#include "PlotStateArgs.h"
#include "MeshSolution.h"
#include "SolutionView.h"

#include <cmath>
#include <complex>
#include <cstdio>

namespace {
// Offline/batch .ansx generation, independent of opening any window --
// `femmqt.exe --convert-ansx foo.ans` regenerates foo.ansx unconditionally
// (skips the freshness check AnsxFileIO::isUpToDate uses elsewhere) and
// exits, per this phase's plan. Uses QCoreApplication-only APIs (file I/O,
// no widgets), so it's safe to run before QApplication would normally be
// needed -- though the executable is still WIN32-subsystem, so stdio
// output is only visible when launched from a console that keeps it
// attached.
// Added by Claude (Anthropic), noreply@anthropic.com, 2026-09-10:
// `femmqt.exe --import-dxf <in.dxf> <out.fem> [tolerance]` parses a DXF
// through femmqt's own DxfIO and writes the resulting geometry as a .fem.
// There are two independent DXF implementations in this tree -- classic
// FEMM's MOVECOPY.CPP ReadDXF and femmqt's port of it -- and nothing could
// compare them, because the classic one is reachable from Lua
// (mi_readdxf) while this one was only reachable by driving the GUI
// (issue #8). Mirrors --convert-ansx: stderr for messages, exit code for
// success. Omitting the tolerance uses the same suggested value classic
// FEMM's import dialog auto-fills.
int importDxfCli(const QString& dxfPath, const QString& femPath,
                 const QString& toleranceArg)
{
  FemmProblem problem;
  double suggestedTolerance = 0.0;
  QString error;
  if (!DxfIO::parseDxf(dxfPath, problem, suggestedTolerance, error)) {
    fprintf(stderr, "%s\n", qPrintable(error));
    return 1;
  }

  double tolerance = suggestedTolerance;
  if (!toleranceArg.isEmpty()) {
    bool ok = false;
    const double parsed = toleranceArg.toDouble(&ok);
    if (!ok || parsed < 0.0) {
      fprintf(stderr, "invalid tolerance: %s\n", qPrintable(toleranceArg));
      return 1;
    }
    tolerance = parsed;
  }
  if (tolerance > 0.0)
    DxfIO::mergeCoincidentNodes(problem, tolerance);

  if (!FemmFileIO::writeFem(femPath, problem, error)) {
    fprintf(stderr, "%s\n", qPrintable(error));
    return 1;
  }
  fprintf(stderr, "Wrote %s (%d nodes, %d segments, %d arcs, tolerance %g)\n",
          qPrintable(femPath), (int)problem.nodes.size(),
          (int)problem.segments.size(), (int)problem.arcSegments.size(),
          tolerance);
  return 0;
}
// Added by Claude (Anthropic), noreply@anthropic.com, 2026-09-11:
// `femmqt.exe --probe-ans <in.ans> <out.csv> [maxElements]` dumps what
// femmqt's own post-processing computes from a solution -- per-element
// flux density and centroid, the block areas, and each circuit's current,
// voltage drop and flux linkage -- as CSV on stdout-equivalent.
//
// femmqt has a second, independent implementation of numbers users make
// engineering decisions with (AnsFileIO's field computation,
// CircuitAnalysis, the block integrals), and nothing could compare them
// against the classic post-processor, because classic's are reachable
// from Lua while femmqt's were only reachable by driving the GUI
// (issue #16). Mirrors --convert-ansx and --import-dxf: stderr for
// messages, exit code for success, and a machine-readable artifact for a
// test to diff.
int probeAnsCli(const QString& ansPath, const QString& csvPath,
                int maxElements)
{
  FemmProblem problem;
  MeshSolution solution;
  QString error;
  if (!AnsFileIO::readAns(ansPath, problem, solution, error)) {
    fprintf(stderr, "%s\n", qPrintable(error));
    return 1;
  }

  QFile out(csvPath);
  if (!out.open(QIODevice::WriteOnly | QIODevice::Text)) {
    fprintf(stderr, "--probe-ans: could not write %s\n", qPrintable(csvPath));
    return 1;
  }
  QTextStream ts(&out);
  ts.setRealNumberNotation(QTextStream::ScientificNotation);
  ts.setRealNumberPrecision(12);

  ts << "kind,index,a,b,c,d\n";
  ts << "mesh,0," << solution.nodes.size() << "," << solution.elements.size()
     << "," << solution.bMagMin << "," << solution.bMagMax << "\n";

  // Per-element centroid and flux density. Sampled rather than dumped in
  // full: a real mesh has tens of thousands of elements and the test only
  // needs enough points to catch a systematic difference.
  const int total = solution.elements.size();
  const int stride = (maxElements > 0 && total > maxElements)
      ? (total + maxElements - 1) / maxElements
      : 1;
  for (int i = 0; i < total; i += stride) {
    const MeshSolutionElement& e = solution.elements[i];
    const double bx = std::hypot(e.B1re, e.B1im);
    const double by = std::hypot(e.B2re, e.B2im);
    ts << "element," << i << "," << e.ctrX << "," << e.ctrY << ","
       << bx << "," << by << "\n";
  }

  // Circuit properties, femmqt's own CircuitAnalysis.
  QVector<CircuitAnalysis::BlockCircuitInfo> blockInfo;
  QString circErr;
  if (!CircuitAnalysis::readBlockCircuitInfo(ansPath, blockInfo, circErr)) {
    // Reported rather than silently skipped: a test that finds no circuit
    // rows needs to know whether that is "this model has none" or "the
    // read failed".
    fprintf(stderr, "--probe-ans: no circuit info (%s)\n",
            qPrintable(circErr));
  } else {
    for (int c = 0; c < problem.circuitProps.size(); c++) {
      CircuitAnalysis::Result r =
          CircuitAnalysis::compute(problem, solution, blockInfo, c + 1);
      if (!r.ok)
        continue;
      ts << "circuit," << c << "," << r.amps.real() << ","
         << r.voltsDrop.real() << "," << r.fluxLinkage.real() << ",0\n";
    }
  }

  out.close();
  fprintf(stderr, "Wrote %s (%d nodes, %d elements, every %d-th sampled)\n",
          qPrintable(csvPath), (int)solution.nodes.size(), total, stride);
  return 0;
}

int convertAnsxCli(const QString& ansPath)
{
  // Modified by Claude (Anthropic), noreply@anthropic.com, 2026-09-13
  // (issue #83): .ansx is the MAGNETICS mesh cache, exactly as .femx is
  // the magnetics model cache (see FILE_FORMATS.md for why that scoping
  // is deliberate). Handed a .res/.anh/.anc this would read it with the
  // magnetics parser, which finds none of its own node columns, and then
  // write a cache of the wrong mesh -- silently, since every step
  // "succeeds".
  FemmProblemKind solutionKind = FemmProblemKind::Magnetics;
  if (SolutionFileIO::kindForSolutionPath(ansPath, solutionKind)
      && solutionKind != FemmProblemKind::Magnetics) {
    fprintf(stderr,
        "--convert-ansx: .ansx caches magnetics solutions only; \"%s\" is a %s "
        "solution. Nothing to convert.\n",
        qPrintable(QFileInfo(ansPath).fileName()),
        qPrintable(ProblemKind::displayName(solutionKind)));
    return 1;
  }

  FemmProblem problem;
  MeshSolution solution;
  QString error;
  if (!AnsFileIO::readAns(ansPath, problem, solution, error)) {
    fprintf(stderr, "%s\n", qPrintable(error));
    return 1;
  }
  QFileInfo fi(ansPath);
  QString ansxPath = fi.absolutePath() + "/" + fi.completeBaseName() + ".ansx";
  if (!AnsxFileIO::writeAnsx(ansxPath, ansPath, (int)problem.problemType, (int)problem.lengthUnits,
          problem.frequency, solution, error)) {
    fprintf(stderr, "%s\n", qPrintable(error));
    return 1;
  }
  fprintf(stderr, "Wrote %s (%d nodes, %d elements)\n", qPrintable(ansxPath), (int)solution.nodes.size(), (int)solution.elements.size());
  return 0;
}

// Modified by Claude (Anthropic), noreply@anthropic.com, 2026-09-11:
// the ~520 lines of constraint/dimension test scenarios that used to live
// here moved to femmqt/tests/tst_constraint_solver.cpp, where ctest runs
// them on every build (issue #12). They were a bespoke harness printing
// "ALL TESTS PASSED" that nothing in CI ever invoked -- numerical solver
// code no automated job runs is code that drifts. The flag is kept as a
// pointer rather than deleted outright, so anyone with it in a script or a
// note gets told where the tests went instead of an unknown-argument error.
int testConstraintsCli()
{
  fprintf(stderr,
      "The constraint/dimension tests moved into femmqt's QTest binary and\n"
      "now run automatically. To run them:\n"
      "\n"
      "  ./build.ps1 -DoNotUpdateTOOL -DisableInteractive -DisableLaTeX\n"
      "             -ForceTriangle32bit -DoNotDeleteBuildFolder\n"
      "  ctest --test-dir build_win_release64_notriangle -C Release\n"
      "\n"
      "Source: femmqt/tests/tst_constraint_solver.cpp\n");
  return 0;
}
} // namespace

int main(int argc, char* argv[])
{
  QApplication app(argc, argv);
  // Gives QSettings (MainWindow's recent-files list) a stable registry
  // location -- without this it defaults to an unset/empty organization,
  // which still works but isn't a location a user (or an uninstaller)
  // could find on purpose.
  QCoreApplication::setOrganizationName("FEMMX");
  QCoreApplication::setApplicationName("femmqt");

  // Must happen before any window is constructed -- IconTheme::
  // themedToolIcon() and GeometryScene/SolutionWindow's background brush
  // both bake in whatever AppTheme::isDark()/qApp->palette() is current
  // at construction time.
  AppTheme::setDark(AppPreferences::load().darkTheme);

  const QStringList args = app.arguments();

  // Issue #85: decide ONCE, before any window exists, whether there is
  // anybody to answer a dialog. Every option below is a batch entry
  // point, usually with no desktop at all, and a modal QMessageBox on
  // one of them is not an error report -- it is a hang that only a
  // timeout can distinguish from a slow model. See Notify.h.
  //
  // Keyed on "argv[1] starts with --" rather than on each flag
  // individually, so an option added later is headless by default
  // instead of by being remembered.
  if (args.size() >= 2 && args.at(1).startsWith(QLatin1String("--")))
    Notify::setHeadless(true);

  if (args.size() >= 3 && args.at(1) == "--convert-ansx")
    return convertAnsxCli(args.at(2));

  if (args.size() >= 4 && args.at(1) == "--import-dxf")
    return importDxfCli(args.at(2), args.at(3),
                        args.size() >= 5 ? args.at(4) : QString());

  if (args.size() >= 4 && args.at(1) == "--probe-ans")
    return probeAnsCli(args.at(2), args.at(3),
                       args.size() >= 5 ? args.at(4).toInt() : 200);

  // `femmqt.exe --render-png <in> <out> [w h]` renders a .fem/.ans
  // offscreen to a PNG. This is what the classic GUI's Lua
  // mi_savepng/mo_savepng shell out to after a script calls
  // setgui("qt") -- Lua only ever runs in the MFC app, so "render with
  // the new GUI" has to mean handing the file to this executable. See
  // femm/ScriptGui.h for the whole arrangement.
  if (args.size() >= 4 && args.at(1) == "--render-png") {
    const QString in = args.at(2);
    const QString out = args.at(3);
    // The positional arguments are recognised by SHAPE, not by count.
    // Issue #86 appends named options after them, so `--render-png in
    // out 600 450 --quantity bmag --bounds 0 2` has ten arguments and
    // the old count-based rule would have read "--quantity" and "bmag"
    // as crop coordinates -- toDouble()ing both to 0 and rendering an
    // empty region with nothing said.
    auto positionalNumber = [&args](int index, double& out) {
      if (index >= args.size() || args.at(index).startsWith(QLatin1String("--")))
        return false;
      bool ok = false;
      const double v = args.at(index).toDouble(&ok);
      if (ok)
        out = v;
      return ok;
    };

    double wd = 1024, hd = 768;
    const bool haveSize = positionalNumber(4, wd) && positionalNumber(5, hd);
    const int w = haveSize ? (int)wd : 1024;
    const int h = haveSize ? (int)hd : 768;
    if (w <= 0 || h <= 0) {
      fprintf(stderr, "--render-png: bad size %dx%d\n", w, h);
      return 1;
    }

    // Issue #14: check the input exists BEFORE constructing a window.
    // MainWindow::openFile / SolutionWindow::openAnsFile report a missing
    // or unreadable file through a modal QMessageBox, which in a CLI run
    // has nobody to dismiss it: measured, `--render-png missing.fem out.png`
    // sat there until killed rather than failing. A batch render over a
    // directory with one bad path would hang the whole job.
    if (!QFileInfo::exists(in)) {
      fprintf(stderr, "--render-png: no such file: %s\n", qPrintable(in));
      return 1;
    }

    const bool isSolution = FileRouting::isSolutionFile(in);

    // Issue #85: refuse an extension neither window understands, here,
    // rather than letting it fall through to the geometry editor. That
    // path used to pop a modal "not a FEMM model file" warning and hang;
    // with Notify it no longer hangs, but it would still leave an empty
    // scene to render and exit 0 -- a valid PNG of nothing, which is in
    // some ways worse than the hang, because nothing reports it. Name
    // the extension: the usual cause is a typo, or a solver that wrote
    // its output somewhere other than where the caller looked.
    FemmProblemKind modelKind = FemmProblemKind::Magnetics;
    if (!isSolution && !ProblemKind::kindForPath(in, modelKind)) {
      const QString suffix = QFileInfo(in).suffix();
      fprintf(stderr,
          "--render-png: %s: unrecognised extension \"%s\". Models are .fem, "
          ".fee, .feh, .fec; solutions are .ans, .res, .anh, .anc.\n",
          qPrintable(in),
          qPrintable(suffix.isEmpty() ? QStringLiteral("(none)") : suffix));
      return 1;
    }

    // Optional scene-space crop: --render-png in out w h x0 y0 x1 y1.
    // Renders a zoomed-in region without a GUI, which matters because the
    // density plot's color banding is scaled to whatever is VISIBLE (see
    // MeshSolutionItem::paintDensity) -- so a full-model render cannot
    // reproduce, or regress-test, how a zoomed-in view actually looks.
    // Issue #86: the plot state the classic post-processor was showing
    // when the script called mo_savepng. Parsed before anything is
    // constructed so a bad option fails immediately -- and a bad option
    // IS a failure: silently rendering defaults after being told what
    // to draw is the bug being fixed, not a fallback.
    PlotState plot;
    QString plotError;
    if (!PlotStateArgs::parse(args.mid(2), plot, plotError)) {
      fprintf(stderr, "--render-png: %s\n", qPrintable(plotError));
      return 1;
    }
    if (!plot.isEmpty() && !isSolution) {
      fprintf(stderr, "--render-png: plot options apply to a solution; \"%s\" "
                      "is a model\n", qPrintable(in));
      return 1;
    }

    QRectF source;
    double x0 = 0, y0 = 0, x1 = 0, y1 = 0;
    if (haveSize && positionalNumber(6, x0) && positionalNumber(7, y0)
        && positionalNumber(8, x1) && positionalNumber(9, y1)) {
      source = QRectF(QPointF(x0, y0), QPointF(x1, y1)).normalized();
    }

    QImage image;
    // The windows are constructed but never shown: renderToImage draws
    // the scene directly, which is why this works without a desktop.
    if (isSolution) {
      SolutionWindow window;
      window.resize(w, h);
      // #83: openSolutionFile routes .ans/.ansx down the unchanged
      // magnetics path and .res/.anh/.anc through the shared reader, so
      // --render-png works for every solver's output.
      if (!window.openSolutionFile(in)) {
        // Notify has already said what went wrong on stderr; the exit
        // code is what a batch caller actually branches on.
        return 1;
      }
      // Issue #86: the post-processor's view state, forwarded by
      // mo_savepng. Applied AFTER the load, because everything it
      // touches lives on the item the load creates -- and the return
      // value is checked, because a state that silently failed to
      // apply produces exactly the defect this fixes: a valid PNG of
      // the wrong plot.
      QString plotApplyError;
      if (!plot.isEmpty() && !window.applyPlotState(plot, &plotApplyError)) {
        fprintf(stderr, "--render-png: %s\n", qPrintable(plotApplyError));
        return 1;
      }
      // Modified by Claude (Anthropic), noreply@anthropic.com: found while
      // trying to visually verify an unrelated density-plot fix -- this
      // call was never here. selectDensityPlot() existed and --density
      // was documented in the commit that added it, but nothing in main()
      // actually checked args for it, so EVERY --density render since
      // that commit silently stayed in the viewer's default Contour mode
      // instead. Every "density" screenshot taken via this CLI path
      // before this fix was actually a contour plot.
      // The plot mode used to be applied here as well as in
      // applyPlotState. Two paths setting the same thing is how one of
      // them stops being exercised without anything noticing -- the
      // mode now crosses exactly once, through the state.
      image = window.renderToImage(QSize(w, h), source);
    } else {
      MainWindow window;
      window.resize(w, h);
      if (!window.openFile(in))
        return 1;
      image = window.renderToImage(QSize(w, h), source);
    }

    if (image.isNull()) {
      fprintf(stderr, "--render-png: nothing to render from %s\n",
          qPrintable(in));
      return 1;
    }
    if (!image.save(out, "PNG")) {
      fprintf(stderr, "--render-png: couldn't write %s\n", qPrintable(out));
      return 1;
    }
    return 0;
  }

  if (args.size() >= 2 && args.at(1) == "--test-constraints")
    return testConstraintsCli();

  // A file path on the command line opens immediately -- used by the
  // femm.cfg-driven GUI switch (step 7) to hand off the currently-open
  // file to the other GUI, mirroring femm.cpp's ProcessShellCommand
  // single-file-open convention. Routed by extension: a solved .ans/.ansx
  // (handed off from the classic GUI's post-processor, CFemmviewView::
  // OnSwitchToQtGui) opens the Solution Viewer, not the geometry editor --
  // otherwise the geometry editor would try to load a possibly-huge
  // solved mesh as if it were raw, editable geometry.
  //
  // Modified by Claude (Anthropic), noreply@anthropic.com, 2026-09-13
  // (issue #88): this said openAnsFile, the MAGNETICS-only path, while
  // isSolutionFile() has matched all four solution formats since #83.
  // It went unnoticed only because the classic GUI had no "Switch to Qt
  // GUI" item outside magnetics, so nothing could hand a .anh across --
  // which is exactly what #88 adds. openSolutionFile routes .ans/.ansx
  // down the unchanged magnetics path and the other three through the
  // shared reader.
  const bool isSolutionFile = args.size() > 1
      && FileRouting::isSolutionFile(args.at(1));

  if (isSolutionFile) {
    auto* solutionWindow = new SolutionWindow();
    solutionWindow->show();
    solutionWindow->openSolutionFile(args.at(1));
  } else {
    auto* window = new MainWindow();
    window->show();
    if (args.size() > 1)
      window->openFile(args.at(1));
  }

  return app.exec();
}

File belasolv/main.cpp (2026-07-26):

#include <stdafx.h>
#include <stdio.h>
#include <math.h>
#include <string.h>
#include <afxtempl.h>
#include "belasolv.h"
#include "belasolvDlg.h"
#include "spars.h"
#include "mesh.h"
#include "FemmeDocCore.h"

void old_main(void* inptr)
{
  CbelasolvDlg* TheView;
  CFemmeDocCore Doc;
  char PathName[256];
  CFileDialog* fname_dia;
  char outstr[1024];
  int i;

  TheView = (CbelasolvDlg*)inptr;

  // get the name of the file to be processed,
  // either from argv or from the user
  if (__argc < 2) {

    fname_dia = new CFileDialog(
        TRUE,
        "fem | * ",
        NULL,
        OFN_HIDEREADONLY | OFN_OVERWRITEPROMPT,
        "belaview datafile (*.fee) | *.fee; *.FEE | All Files (*.*) | *.*||",
        NULL);

    if (fname_dia->DoModal() == IDCANCEL) {
      delete[] fname_dia;
      MsgBox("No file name!");
      exit(0);
    }

    CString fname = fname_dia->GetPathName();
    fname = fname.Left(fname.GetLength() - 4);
    strcpy(PathName, fname);
    delete[] fname_dia;
  } else
    strcpy(PathName, __argv[1]);

  Doc.PathName = PathName;
  Doc.TheView = TheView;

  // load problem geometry
  if (Doc.OnOpenDocument() != TRUE) {
    MsgBox("problem loading .fee file");
    exit(7);
  }

  // load mesh
  if (Doc.LoadMesh() != TRUE) {
    MsgBox("problem loading mesh");
    exit(2);
  }

  // label the dialog to report which problem is being solved
  char PaneText[256];
  char* ProbName;
  ProbName = PathName;
  for (i = 0; i < (int)strlen(PathName); i++)
    if (PathName[i] == '\\')
      ProbName = PathName + i;
  if (strlen(PathName) > 0) {
    ProbName++;
    sprintf(PaneText, "%s - belasolve", ProbName);
  }

  while (!IsWindow(TheView->m_hWnd))
    Sleep(1);
  TheView->SetWindowText(PaneText);

  // renumber using Cuthill-McKee
  TheView->SetDlgItemText(IDC_STATUSWINDOW, "renumbering nodes");
  if (Doc.Cuthill() != TRUE) {
    MsgBox("problem renumbering nodes");
    exit(3);
  }

  // display details about the problem to be solved
  TheView->SetDlgItemText(IDC_STATUSWINDOW, "solving...");
  sprintf(outstr, "Problem Statistics:\n%i nodes\n%i elements\nPrecision: %3.2e\n",
      Doc.NumNodes, Doc.NumEls, Doc.Precision);
  TheView->SetDlgItemText(IDC_PROBSTATS, outstr);

  // initialize the problem, allocating the space required to solve it.

  CBigLinProb L;
  L.TheView = TheView;
  L.Precision = Doc.Precision;
  L.GPUAccel = Doc.GPUAccel;

  if (L.Create(Doc.NumNodes + Doc.NumCircProps, Doc.BandWidth) == FALSE) {
    MsgBox("couldn't allocate enough space for matrices");
    Doc.CleanUp();
    L.~CBigLinProb();
    exit(4);
  }

  // Create element matrices and solve the problem;
  if (Doc.AnalyzeProblem(L) == FALSE) {
    MsgBox("Couldn't solve the problem");
    Doc.CleanUp();
    L.~CBigLinProb();
    exit(5);
  }

  TheView->SetDlgItemText(IDC_STATUSWINDOW, "Problem solved");

  // now that we have results, write 'em to dist
  if (Doc.WriteResults(L) == FALSE) {
    MsgBox("couldn't write results to disk");
    Doc.CleanUp();
    L.~CBigLinProb();
    exit(6);
  }
  TheView->SetDlgItemText(IDC_STATUSWINDOW, "results written to disk");

  // make sure that everything is freed up to avoid memory leaks
  Doc.CleanUp();
  L.~CBigLinProb();
  exit(0);
}

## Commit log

2026-07-07 Add demo_models with a scripted FEMM example, and a modification notice
    - demo_models/straight_wire_field.py builds, solves, and validates a
    simple current-carrying-wire magnetostatics problem entirely from
    Python via the pyfemm COM interface, checking the result against
    the analytical (Ampere's law) solution.
    - NOTICE.md records the repository-level modification history required
    by AFPL section 2(c)(i) for this rehosted fork.
2026-07-07 Fix O(n^2) EnforcePSLG rebuild in Copy, and rename demo_models to test_models
    CFemmeDoc::EnforcePSLG(), called once per Copy operation, rebuilt the
    entire node/segment/arc/block list from scratch on every call by
    tearing everything down and re-inserting it through intersection-
    checking Add* functions -- O(n^2) in total feature count, since
    RotateCopy/TranslateCopy only ever append new geometry to the end of
    each list and the pre-existing prefix never needed re-validating
    against itself.
    - femm/MOVECOPY.CPP, femm/FemmeDoc.h: add an incremental
    EnforcePSLG(tol, nodeStart, lineStart, arcStart, blockStart) overload
    that only tears down and re-validates the newly appended tail of each
    lis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
2026-07-07 Add experimental Dark Theme toggle to the magnetics editor (revertible)
    Adds a "Dark Theme" item to the View menu (ID_VIEW_DARKTHEME) that
    swaps CFemmeView's canvas colors (background, grid, node, line, block,
    mesh, selection, name) between the light defaults and a dark palette,
    and best-effort switches the main window's title bar via
    DwmSetWindowAttribute/DWMWA_USE_IMMERSIVE_DARK_MODE (Windows 10
    1809+/11; harmless no-op elsewhere).
    Verified end-to-end against the built femm.exe (WM_COMMAND to
    ID_VIEW_DARKTHEME, screenshotted before/after): canvas and title bar
    switch correctly in both directions.
    Scope, intentionally limited: only the magnetics editor's canvas and
    title bar are re-themed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
2026-07-07 Add Lua command regression sweep; reorganize test_models outputs
    - test_models/lua_command_regression_test.py: drives a realistic
    workflow through FEMM's ~450-function Lua command surface (all four
    problem types: magnetics, electrostatics, heat flow, current flow;
    both pre- and post-processor prefixes), tracking every call as
    PASS/FAIL/SKIP. Guards against loadsolution's blocking "file not
    found" MessageBox by checking the solution file landed on disk
    before calling it, instead of hanging. 549 calls, 397 pass, 13 fail,
    139 skip on this build -- magnetics (the editor this fork modifies)
    passes cleanly apart from a pre-existing savebitmap bug also present
    in the other three i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
2026-07-08 Convert regression scripts to a pytest suite runnable in CI; rename test_models to unittests
    - unittests/conftest.py: skips the whole suite cleanly (not an error) if
    femm.exe/COM automation isn't available, via a registry check for the
    femm.ActiveFEMM ProgID.
    - straight_wire_field_test.py, enforce_pslg_correctness_test.py,
    copy_redraw_benchmark_test.py, lua_command_regression_test.py: converted
    from standalone print/SystemExit scripts to real pytest test functions
    with assertions. The Lua command sweep runs once per session (module
    fixture) and is asserted against per problem-type group; magnetics is a
    hard, zero-tolerance gate (it's the editor this fork modifies), while a
    do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
2026-07-08 Add optional CUDA-accelerated linear solve for the magnetostatic solver
    Investigated GPU acceleration feasibility first (see the project's Claude
    memory / gpu_speedup_investigation): FEMM's PCG solver stores its matrix
    as a linked list, and SSOR's forward/back substitution is an inherently
    sequential dependency chain, so a real GPU port meant a Jacobi-
    preconditioned PCG kernel instead. A standalone cupy/cuSPARSE benchmark
    showed the crossover point against CPU-SSOR sits around 15-20K unknowns,
    with a growing win beyond that (24.6x at 300K), so this is opt-in, not a
    default -- most FEMM problems are far smaller than the crossover.
    - fkn/spars_cuda.cu (new): CBigLinProb::PCGSolveGPU() conver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
    [main.cpp]
2026-07-08 Add CPU/GPU load monitor window; finish femm_mods->femm_plus rename
    Adds fkn/LoadMonitorDlg.h/.cpp, a modeless dialog shown alongside the
    solver progress window while fkn.exe is solving. Plots a rolling
    60-second CPU utilization strip chart (GetSystemTimes) and, when an
    NVIDIA GPU/driver is present, GPU utilization (NVML, loaded
    dynamically so this builds unconditionally without the CUDA Toolkit).
    Includes a "Save as PNG..." button. Verified the window renders
    correctly alongside the fkern progress dialog during a real solve.
    Also completes the unittests/->test/ rename (the prior rename commit
    added test/ but never removed the old unittests/ tree from git), and
    updates NOTICE.md/README.md a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
2026-07-09 Build the NSIS installer automatically into bin/ during install
    Wires script.nsi into the root CMakeLists.txt via install(CODE ...),
    so `cmake --build . --target install` (what build.ps1 always runs)
    now also produces bin/FEMMX_installer.exe whenever makensis is found
    (via find_program, with NSIS's standard install-location HINTS as a
    fallback in case PATH hasn't been refreshed yet) -- no separate manual
    step needed. Gracefully skipped (message, not an error) if makensis
    isn't found, matching the existing optional-LaTeX-manual pattern; a
    partial build (any SKIP_* option set) makes makensis itself fail with
    a clear "file not found" error, reported as a warning rather than
    failing the whole in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
2026-07-09 Split load monitor stats log into short lines instead of one long line
    Each solve's summary was a single wide line (timestamp, label, duration,
    CPU/GPU/RAM max/avg all concatenated), which got clipped at the dialog's
    fixed width. Break it into one short line per stat, with a blank
    separator between solve entries, so nothing is cut off regardless of the
    dialog's size.
2026-07-09 Load monitor chart: only update while solving, freeze after, add autoscaled time axis
    Previously the chart was a continuous 60s rolling window sampled
    regardless of solve state. Now:
    - MarkSolveStart() clears the chart's history/markers so each solve
    starts from a blank graph.
    - OnTimer only samples (and thus only advances/redraws the chart)
    while a solve is in progress; once it ends, sampling stops and the
    chart freezes on its final frame until the next solve starts.
    - Added a time (x) axis, autoscaled to whatever's actually been
    sampled so far and stretched to fill the width, instead of always
    spanning the full 60s window -- otherwise a short solve would be
    squeezed into an unr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
2026-07-09 Cache density-plot GDI pens/brushes instead of recreating per sub-triangle
    PlotFluxDensity (in each of FemmviewView/hviewView/cviewView/
    belaviewView.cpp -- identical copy-pasted code across all four
    problem types) redraws the whole mesh's density/heatmap plot on every
    repaint (zoom, pan, etc.), and was calling CreateSolidBrush/CreatePen
    fresh for every sub-triangle of every element, even though only ~20
    distinct legend-band colors ever exist. For a large mesh (600K+
    elements) that's well over a million needless GDI object
    creates/destroys per redraw.
    Investigated GPU-accelerating this instead (per user request), but the
    actual per-element math is cheap -- the GDI object churn dominates, an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
2026-07-09 Fix win-cuda CI job: pass -allow-unsupported-compiler to nvcc
    The new win-cuda job failed on its first run: nvcc hard-errors (fatal
    error C1189 in crt/host_config.h) because the windows-latest runner has
    Visual Studio 18 (2026) installed, newer than CUDA 12.6's officially
    supported MSVC window (2017-2022). This is a routine CI-environment
    mismatch (the runner image's VS version moves independently of any CUDA
    version pin), not a real incompatibility -- spars_cuda.cu doesn't use
    anything toolset-version-specific, and a genuinely broken combination
    would still fail to compile rather than silently miscompile. Verified
    locally that adding this flag doesn't affect the existing (already
    MSVC-compa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
2026-07-09 Fix win-cuda CI job: pin runner to windows-2022, not windows-latest
    The -allow-unsupported-compiler fix got past nvcc's MSVC version-string
    gate, but hit a deeper problem: nvcc's own cudafe++ preprocessor crashed
    outright (ACCESS_VIOLATION) trying to parse the host compiler's headers.
    Root cause: windows-latest started shipping Visual Studio 2026 (as
    "Visual Studio 18") as of 2026-06-08, far newer than CUDA 12.6 (or any
    current CUDA release) has been built/tested against -- confirmed via
    actions/runner-images issue #14017. This isn't something a compiler
    flag can paper over.
    windows-2022 remains a supported GitHub-hosted runner label (maintained
    for several more years per GitHub's own guida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
2026-07-09 Auto-register femm.ActiveFEMM on install; make test COM registration reversible
    script.nsi now writes the same HKCU femm.ActiveFEMM COM entries
    register_femm_com.ps1 writes by hand, and removes them on uninstall --
    so pyfemm/Octave/Mathematica/Scilab automation works right after a
    normal install, with no separate manual registration step.
    register_femm_com.ps1 now snapshots whatever LocalServer32 was
    registered before it runs (first call only, so switching builds
    mid-session doesn't lose the true original) to
    $env:TEMP\femmx_com_registration_snapshot.json. New
    scripts/unregister_femm_com.ps1 reads that snapshot and restores the
    prior registration, or removes it entirely if there wasn't one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
2026-07-09 Fix load monitor not updating during interactive (non-scripted) solves
    MarkSolveStart()/MarkSolveEnd() were only called inside each analyze
    entry point's `if (bLinehook != FALSE)` branch -- the Lua/COM-scripted
    solve path. A normal GUI "Analyze" click leaves bLinehook == FALSE the
    whole time, so the monitor was never told a solve started, and its
    timer-driven sampling (gated on m_bSolveInProgress) never ran: the
    window showed but the chart never advanced.
    The interactive path has no synchronous wait loop to call
    MarkSolveEnd() from (it fires off the solver process and returns
    immediately, letting it run as its own visible window) -- so
    MarkSolveStart() now optionally takes the child process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
2026-07-09 Add dark theme to the results (.ans) window; batch density-plot GDI calls
    CFemmviewView gets the same dark theme toggle CFemmeView (the editor)
    already had -- ApplyTheme/OnViewDarkTheme/OnUpdateViewDarkTheme, a new
    "Dark Theme" item on IDR_FEMMVIEWTYPE's View menu, plus dark
    equivalents for the plot-specific colors the editor doesn't have
    (region/text/flux-line/vector colors).
    Investigated further optimization of density-plot rendering (per-
    element math is cheap -- a few sqrt/compare calls -- so the real cost
    for a large mesh is GDI call count: PlotFluxDensity previously issued
    one Polygon() call per rendered sub-triangle, easily millions for a
    fine mesh). Promoted the existing per-legend-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
2026-07-25 Add CUDA-accelerated linear solve to all four solvers (fkn, hsolv, belasolv, csolv)
    fkn (magnetics) already supported opt-in GPU-accelerated PCG/PBCG solve via
    mi_setgpuaccel; this ports the same CUDA solve path to hsolv (heat flow),
    belasolv (electrostatics), and csolv (current flow), each exposed through
    their own *_setgpuaccel/*_setredraw Lua commands (and the matching
    octavefemm/scifemm/mathfemm scripting bindings and manual entries). csolv
    needed its own CUDA kernel since its convergence criterion differs from
    the other three. Adds regression tests and CI coverage for all four
    solvers' GPU paths.
    [MAIN.CPP]
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2026-07-25 Add femmqt: a new Qt6-based magnetics GUI
    A second, modern GUI alongside the existing MFC one, built around
    QGraphicsScene/QGraphicsView for CAD-style geometry editing and a
    custom-painted Solution Viewer for plotting results. Reads/writes the
    same .fem/.ans formats as the classic GUI (plus its own .femx/.ansx
    binary caches) so files and solvers stay fully interchangeable between
    the two. Magnetics only for this phase.
    Highlights:
    - Geometry editor: add/edit/move/copy/scale/mirror nodes, segments,
    arcs and block labels; grid snap; zoom/pan; undo; DXF import/export;
    Create Radius and Create Open Boundary (ABC) construction tools.
    - Full property editing: Problem Properties, Materials/Bou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
    [main.cpp]
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2026-07-26 femmqt: add thermal (heat-flow) problem support, sharing geometry with magnetics
    Per direct request: solve both magnetics and thermal problems on the same
    femmqt geometry, sharing the materials library/properties/boundary-type
    workflow, with an easy magnetics-finished -> also-do-thermal flow. Scoped
    entirely to femmqt/ -- the classic MFC GUI and all solver executables are
    unmodified (hsolv.exe already had its CUDA solve port from a prior
    session, ready to drive exactly like fkn.exe).
    - FemmProblem gains parallel thermal property lists/structs
    (FemmThermalMaterialProp/BoundaryProp/PointProp/ConductorProp) and a
    second index on every node/segment/arc/block-label
    (thermalPointPropIndex/t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
    [main.cpp]
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2026-07-27 femmqt: revert thermal support, extensive dialog/menu parity pass vs classic GUI
    Two bundled changes sitting in the working tree, committed together per
    direct request to push everything on new_features:
    Thermal revert (per direct request: "remove all the functionality
    regarding thermal problems in qt and revert back to magnetics"):
    - Removes HeatFileIO, AnhFileIO, ThermalBoundaryPropDialog,
    ThermalPointPropDialog and every thermal field/index added across the
    prior two commits (FemmProblem's Kx/Ky/Kt/qv/tkData, thermalPointPropIndex/
    thermalBoundaryMarker/thermalBlockTypeIndex, MainWindow's Physics Mode
    toggle and second thermal file path/save flow, MeshBuilder/SolveRunner's
    Femm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
    [main.cpp]
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2026-08-08 femmqt: add CAD-style dimensions and geometric constraint solver
    Adds an in-session-only (never persisted to .fem/.femx) sketch layer:
    9 constraint types (Coincident, Horizontal, Vertical, Parallel,
    Perpendicular, Equal, Tangent, Concentric, Symmetric) and 3 dimension
    types (Distance, Radius, Angle), solved via a hand-rolled
    Levenberg-Marquardt solver (ConstraintSolver.h/.cpp, DenseMatrix.h) with
    per-component DOF/sketch-health classification and color coding.
    Dimension rendering matches Fusion 360's style: gapped/overshot
    extension lines, arrowheads, and a true curved arc (not a straight-line
    wedge) for angle dimensions. Constraints show as small clickable
    on-canvas glyphs (reusing the Con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
    [main.cpp]
2026-08-08 femmqt: rework Smart Dimension tool to Fusion 360's select-move-place-type model
    Replace the click-then-immediately-prompt Smart Dimension interaction
    with a live select -> cursor-resolved preview -> placement click ->
    type-value flow, per the Fusion 360 Sketch Dimension Tool reference:
    - Two selected nodes now live-resolve to Horizontal, Vertical, or
    Aligned distance based on cursor position during free mouse movement,
    each backed by its own solver residual (DimensionType::
    HorizontalDistance/VerticalDistance use |dx|/|dy|, distinct from the
    existing Euclidean Distance residual) so the constraint actually
    matches what's displayed instead of only relabeling one formula.
    - Selectin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
    [main.cpp]
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2026-08-13 femmqt: angle dimensions between lines that never touch
    Per direct user report: "The angle tool does not always work well. Make
    it work is similar way as in fusion 360."
    The "not always" was specific. Smart Dimension's line -> line angle only
    fired when the two segments shared an endpoint node; two lines that did
    not touch fell through and were swallowed as an ordinary placement click,
    so angling a corner worked and angling anything else silently did
    nothing. The separate Angle Dimension tool was worse: it responded ONLY
    to clicks on nodes, needed three of them in a fixed order (vertex first,
    then each ray end) with no feedback about which stage you were in, and
    popped a modal dialog on the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
    [main.cpp]
2026-08-14 femmqt: insert a node where two segments cross
    Per direct user request, and previously reported as not working because
    it had never been implemented -- classic FEMM does this in
    FancyEnforcePSLG, and femmqt has never done it (DxfIO.h documents the
    same gap for imports). Without it two crossing lines stay logically
    disconnected: the mesher sees no shared vertex at the crossing, so the
    regions they appear to bound are not actually bounded.
    FemmProblemEdit::splitIntersectingSegments() finds crossing pairs,
    inserts a node at the intersection and cuts both segments in two,
    re-scanning after each split because splitting changes the list and one
    segment crossing several others must be cut once per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
    [main.cpp]
2026-08-14 femmqt: material-aware, distance-weighted density smoothing
    Per direct user report ("the density view, compared to the old gui,
    when zooming in, renders a bit rough") plus a side-by-side screenshot
    that reframed the diagnosis: the serration concentrated exactly along
    material boundaries -- the core edge, the halo around each winding --
    where classic's edges stayed smooth. Not a band-count problem (both
    GUIs use comparable band counts); a smoothing-quality problem.
    Root cause: the density plot's "Smoothing" option averaged EVERY
    element touching a node into one shared value, equally weighted,
    regardless of material. femm/FemmviewDoc.cpp's own smoothing
    (GetNodalB) does neither -- it is inver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
    [main.cpp]
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2026-09-10 DXF import/export tests for both implementations, plus a CLI (#8)
    DXF is how real geometry gets into FEMM from CAD, and there are two
    independent implementations here -- classic's MOVECOPY.CPP ReadDXF/
    WriteDXF and femmqt's DxfIO, a direct port of it -- with no test between
    them. The Lua sweep writes a .dxf but never reads one back.
    Cross-implementation comparison needed femmqt's parser reachable without
    driving the GUI, so this adds `femmqt.exe --import-dxf <in.dxf> <out.fem>
    [tolerance]`, mirroring the existing --convert-ansx: stderr for messages,
    exit code for success, and the same suggested merge tolerance classic's
    import dialog auto-fills when the argument is omitted.
    21 assertions o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
    [arc.dxf, circle.dxf, garbage.dxf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]
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2026-09-11 Golden-image tests for --render-png, and fix a hang on missing input (#14)
    --render-png renders offscreen with no desktop, which makes it the
    cheapest way to regression-test the whole render pipeline, and it is what
    mi_savepng/mo_savepng shell out to after setgui("qt"). It is also
    demonstrably fragile: --density was documented and implemented but
    nothing in main() ever checked the argument, so EVERY --density render
    silently produced a contour plot for multiple releases.
    Four renders of a committed model are compared against committed
    references -- geometry, contour, density, and a scene-space crop, the
    last because density banding is scaled to what is VISIBLE so a full-model
    render cannot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
    [main.cpp]
2026-09-11 femmqt: post-processing parity with the classic post-processor (#16)
    femmqt carries a second, independent implementation of numbers users make
    engineering decisions with, and nothing compared it against classic's.
    Both sides read the SAME solved .ans here, so any difference is in the
    post-processing rather than the solve.
    Adds `femmqt.exe --probe-ans <in.ans> <out.csv> [maxElements]`, mirroring
    --convert-ansx and --import-dxf: femmqt's post-processing was reachable
    only by driving the GUI, while classic's is a Lua call away, so there was
    no way to put the two side by side.
    mesh counts identical, 230 nodes / 417 elements
    |B| at 138 centroids 4.5e-13 worst relative diffe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
    [main.cpp]
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2026-09-11 This fork's scripting additions and the GUI switch (#19)
    Everything FEMMX adds to the Lua surface -- *_setredraw, *_setgpuaccel,
    setgui/getgui, mi_savepng/mo_savepng, get_solve_stats -- is by
    construction something no upstream test could have covered, and almost
    none of it was covered here either. copy_redraw_benchmark_test.py
    measured how FAST setredraw is; nothing asserted it was CORRECT.
    test/fork_scripting_test.py covers that surface: a batch of edits built
    with redraw suppressed must produce a byte-identical model to the same
    edits with it on (all four physics), the resulting document must render
    identically, both spellings of every added command must run and reach
    the right function,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
    [main.cpp]
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2026-09-13 femmqt: batch paths fail instead of hanging on a modal dialog
    femmqt is one executable wearing two hats. Started normally it is a
    desktop application and a modal QMessageBox is exactly right. Started
    with --render-png, --convert-ansx, --import-dxf, --probe-ans or
    --test-constraints it is a batch tool, usually with no desktop at all,
    and the same QMessageBox is a hang: the event loop sits on a dialog
    nobody can dismiss. Measured before this change -- --render-png on an
    extension femmqt did not recognise blocked until killed.
    That shape is worse than an ordinary bug. It is not a crash, so no exit
    code reports it; not slow, so only a clock separates it from a large
    model; and under CI it costs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
    [main.cpp]
2026-09-13 femmqt: the post-processor's plot state crosses to the Qt renderer
    Lua runs only in the classic MFC app, so setgui("qt") + mo_savepng
    means "hand the solved file to femmqt.exe and let it draw". femmqt
    opens the file fresh, with its own defaults, and could see nothing the
    script had configured -- the shell-out passed a size and nothing else.
    So
    mo_showdensityplot(1, 0, 2.0, 0, "bmag")
    mo_savepng("out.png")
    produced femmqt's default CONTOUR plot: 59% of pixels different from
    what was asked for, no error, and a perfectly valid PNG of the wrong
    plot.
    PlotStateArgs carries the state as explicit arguments -- mode, density
    quantity, bounds, greyscale, legend, contour count, and the visib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
    [main.cpp]
2026-09-13 femm: lift the "Qt is magnetics only" refusals, and fix a lying legend
    eo_/ho_/co_savepng and their three editor twins refused the Qt renderer
    outright. That was correct when written -- femmqt drew magnetics only,
    and quietly substituting the classic renderer would have handed back an
    image different from the one requested with nothing to say so. #83 gave
    femmqt a Solution Viewer for all four physics and #85 stopped an
    unreadable file hanging the render, so the premise is gone. Six copies
    of the sentence are gone with it.
    What survives is the principle the refusals were protecting. The Qt
    viewer draws exactly ONE density quantity for the other three physics
    -- the field its solver stores --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
    [main.cpp]
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
